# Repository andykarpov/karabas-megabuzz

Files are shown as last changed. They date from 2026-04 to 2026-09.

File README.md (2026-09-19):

## Karabas-MegaBuzz

Simple FPGA based sound card for ZX Spectrum (NemoBus). 
Inspired by a ZX-Multisound and karabas-opl3 soundcards :)

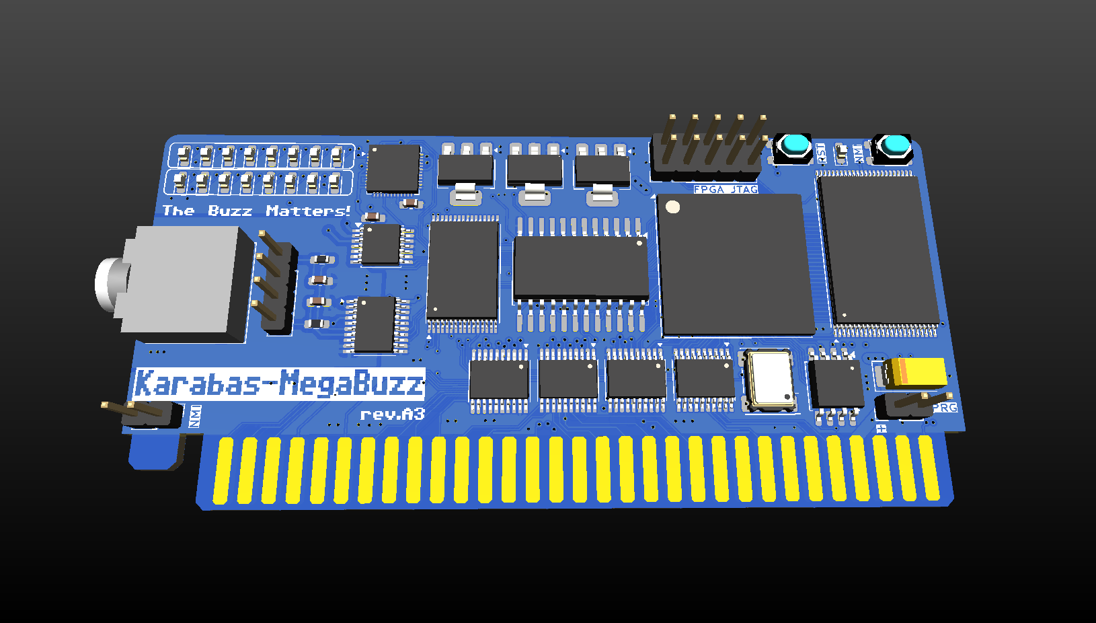
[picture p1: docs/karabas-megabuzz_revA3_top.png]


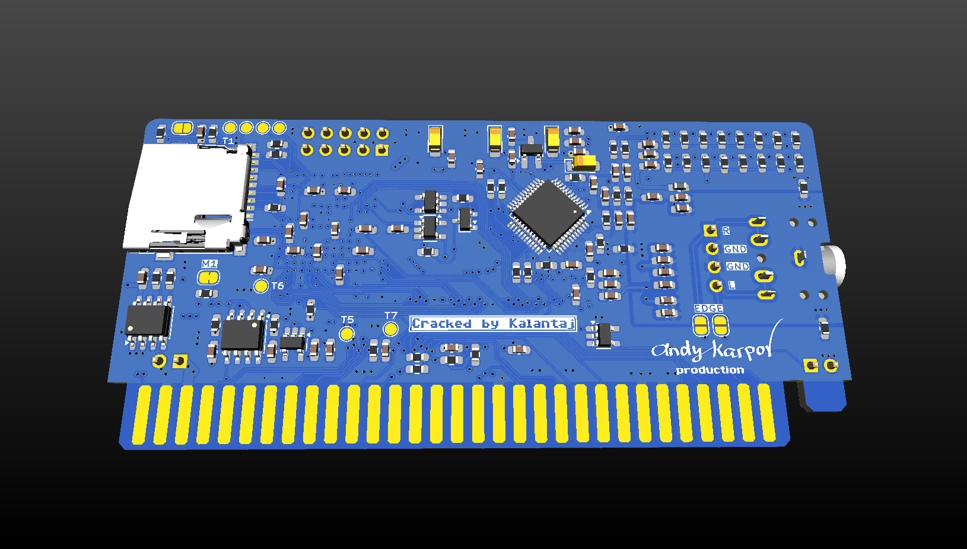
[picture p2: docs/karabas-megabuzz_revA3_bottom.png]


### Tech specs

* Turbosound FM
* General Sound 2 MB
* OPL3 sound by YMF-262-M
* MIDI by Dream SAM2695
* SAA1099
* Soundrive, Covox + Beeper
* MP3, OGG, WMA, AAC decoding by VS1053/VS1063
* 16-bit DAC PCM5102
* XC6SLX16 / XC6SLX25 FPGA
* SD Card by Z-Controller / DivMMC (since rev.A1)
* Low profile PCB: 92x44mm
* 5V only power required

### Changelog & current status [ERRATA](ERRATA.md)

* Rev.A - initial release

* Rev.A1 - intermediate revision

    * [x] Added SD card
    * [x] Changed OPL3 chip power to 3v3 rail, reset controlled by FPGA
    * [x] Added NMI button
    * [x] Added SD LED
    * [x] Added PSRAM chip
    * [x] Added new signals to grab and emit on nemobus (NMI, ROMCS)
    * [x] Added ability to pass sound out via nemobus slot

* Rev.A2 - current revision

    * [x] Removed DIP switches
    * [x] Added 128kB SRAM chip for DivMMC
    * [x] Added 8kb EEPROM chip to store configuration

* Rev.A3 - current dev version

    * [x] Added VS1053 IC

### How-to & Documentation

Please [read the manual](HOWTO.md) how to flash your card with alt tools, like Altera Usb Blaster + openocd.

Some links to the documentation files:

* revA: [Schematics](docs/karabas-megabuzz-revA.pdf), [interactive BOM](docs/karabas-megabuzz-revA-ibom.html)
* revA1: [Schematics](docs/karabas-megabuzz-revA1.pdf), [interactive BOM](docs/karabas-megabuzz-revA1-ibom.html)
* revA2: [Schematics](docs/karabas-megabuzz-revA2.pdf), [interactive BOM](docs/karabas-megabuzz-revA2-ibom.html)
* revA3: [Schematics](docs/karabas-megabuzz-revA3.pdf), [interactive BOM](docs/karabas-megabuzz-revA3-ibom.html)

### Bitstreams & ROMs to flash into the SPI flash chip

| Board Revision | FPGA XC6SLX16 | FPGA XC6SLX25 |
| :--- | :--- | :--- |
| **Rev.A** | • [(Bitstream)](firmware/src/syn/work16/karabas_megabuzz.bin)<br>• [(GS ROM)](firmware/src/rtl/sound/gs105b.rom)<br>• [(CFG)](firmware/src/syn/cfg1.rom) | • [(Bitstream)](firmware/src/syn/work25/karabas_megabuzz.bin)<br>• [(GS ROM)](firmware/src/rtl/sound/gs105b.rom)<br>• [(CFG)](firmware/src/syn/cfg1.rom) |
| **Rev.A1** | • [(Bitstream)](firmware/src/syn/work16/karabas_megabuzz_a1.bin)<br>• [(GS ROM)](firmware/src/rtl/sound/gs105b.rom)<br>• [(CFG)](firmware/src/syn/cfg1.rom) | • [(Bitstream)](firmware/src/syn/work25/karabas_megabuzz_a1.bin)<br>• [(GS ROM)](firmware/src/rtl/sound/gs105b.rom)<br>• [(CFG)](firmware/src/syn/cfg1.rom) |
| **Rev.A2** | • [(Bitstream)](firmware/src/syn/work16/karabas_megabuzz_a2.bin)<br>• [(GS ROM)](firmware/src/rtl/sound/gs105b.rom)<br>• [(CFG)](firmware/src/syn/cfg1.rom) | • [(Bitstream)](firmware/src/syn/work25/karabas_megabuzz_a2.bin)<br>• [(GS ROM)](firmware/src/rtl/sound/gs105b.rom)<br>• [(CFG)](firmware/src/syn/cfg1.rom) |
| **Rev.A3** | • [(Bitstream)](firmware/src/syn/work16/karabas_megabuzz_a3.bin)<br>• [(GS ROM)](firmware/src/rtl/sound/gs105b.rom)<br>• [(CFG)](firmware/src/syn/cfg1.rom) | • [(Bitstream)](firmware/src/syn/work25/karabas_megabuzz_a3.bin)<br>• [(GS ROM)](firmware/src/rtl/sound/gs105b.rom)<br>• [(CFG)](firmware/src/syn/cfg1.rom) |

### Related projects

* Karabas-OPL3 - [link](https://github.com/andykarpov/karabas-opl3)
* BomgeMoon - [link](https://github.com/Kulicheg/BomgeMoon)
* ZX-Multisound - [link](https://github.com/UzixLS/zx-multisound)
* Turbo Sound FM - [link](http://www.nedopc.com/TURBOSOUND/ts-fm.php)
* ZXM-SoundCard - [link](http://micklab.ru/My%20Soundcard/ZXMSoundCard.htm)
* ZXM-GeneralSound - [link](http://micklab.ru/My%20Soundcard/ZXMGeneralSound.htm)
* NeoGS - [link](http://www.nedopc.com/gs/ngs.php)

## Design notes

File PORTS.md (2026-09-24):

# 🎵 Порты Megabuzz

Все звуковые устройства на стороне Megabuzz доступны через свои порты. Также имеются служебные порты для управления самим Megabuzz (для ревизий `A2`, `A3`). В данной документации будут описаны только специфические порты - для vs1053, для управления флагами настроек.

## 🔌 Порты ZXUNO

Для управления чипом vs1053 и служебные порты доступны через набор регистров портов ZXUNO `#FC3B` / `#FD3B`.

### 🔌 Порт выбора регистра ZXUNO - `#FC3B`

Данный порт используется по стандарту ZXUNO для выбора регистра, с которым работает порт данных `#FD3B`.

На данный момент плата Megabuzz поддерживает такие кастомные регистры портов ZXUNO:

- `#F5` - регистр статуса и управления FIFO VS1053
- `#F6` - регистр данных FIFO VS1053
- `#F7` - регистр байта конфигурации Megabuzz
- `#F8` - регистр ПЗУ Megabuzz
- `#F9` - регистр управления Megabuzz
- `#FA` - регистр адреса байта конфигурации Megabuzz
- `#FB` - регистр громкости VS1053
- `#FC` - регистр эффектов VS1053

##### 📟 Регистр `#F5` - статус и управление FIFO VS1053

при чтении из порта данных, возвращается:

- 7️⃣ бит 7 - статус переполнения FIFO VS1053
- 6️⃣...0️⃣ биты 6:0 - количество занятых блоков по 32 байта в FIFO VS1053

при записи в порт данных

- 7️⃣ бит 7 - сбрасывает FIFO и VS1053 через soft reset
- 6️⃣...0️⃣ биты 6:0 = 0

##### 📟 Регистр `#F6` - данные FIFO VS1053

- при записи - записывается переданный байт данных в FIFO VS1053
- при чтении - отдается то же самое, что и для регистра #F5 (то есть статус FIFO)

##### 📟 Регистр `#F7` - регистр байта конфигурации Megabuzz

- при записи в порт данных - пишется байт конфигурации по адресу, выставленному для регистра `#FA`
- при чтении из порта данных - отдается байт конфигурации по адресу, выстанвленному для регистра `#FA`

В данных момент существует только 2 байта конфигурации

Первый байт конфигурации (адрес = 0x00):

- 0️⃣ бит 0 - DivMMC вкл = 1, выкл = 0
- 1️⃣ бит 1 - Z-Controller вкл = 1, выкл = 0
- 2️⃣ бит 2 - Soundrive
- 3️⃣ бит 3 - Beeper
- 4️⃣ бит 4 - SAA1099
- 5️⃣ бит 5 - General Sound
- 6️⃣ бит 6 - Turbosound FM + MIDI
- 7️⃣ бит 7 - OPL3

Второй байт конфигурации (адрес = 0x01)

- 0️⃣ бит 0 - Включен ли столбик VU-метра
- 1️⃣ бит 1 - Включена ли точка VU-метра
- 2️⃣ бит 2 - Переключает направление VU-метра в обратную сторону

##### 📟 Регистр `#F8` - регистр ПЗУ Megabuzz

- 0️⃣ бит 0 - переключает между штатной ПЗУ хоста или ПЗУ конфигуратора Megabuzz. `1` = ПЗУ Megabuzz, `0` - ПЗУ спектрума

##### 📟 Регистр `#F9` - регистр управления Megabuzz

- 0️⃣ бит 0 - значение `1` - осуществляет сброс хоста

##### 📟 Регистр `#FA` - адрес байта конфигурации Megabuzz

- 7️⃣...0️⃣ биты 7:0 - задают адрес байта конфигурации. Валидные значения на сегодня - `0x00`, `0x01`

##### 📟 Регистр `#FB` - громкость VS1053

- значение `0x00` - максимальная громкость
- значение `0xFE` - минимальная громкость

По-умолчанию, плата сбрасывается со значением громкости `0x08` (ослабление примерно `-5дБ` от максимальной громкости).

##### 📟 Регистр `#FС` - управление эффектами VS1053

- 7️⃣...6️⃣ биты 7:6 - ear speaker (`00` - off, `01` - low, `10` - mid, `11` - high)
- 5️⃣...3️⃣ биты 5:3 - treble boost (`000` - off, `111` - max +10.5dB) at 5kHz
- 2️⃣...0️⃣ биты 2:0 - bass boost (`000` - off, `111` - max + 14dB) at 60Hz

По-умолчанию, регистр эффектов содержит значение `0x00`

### 🔌 Порт данных ZXUNO - `#FD3B`

В данный порт пишется значение в регистр, выбранный перед этим через порт `#FC3B`.
Значения регистров доступны и для чтения через этот порт.

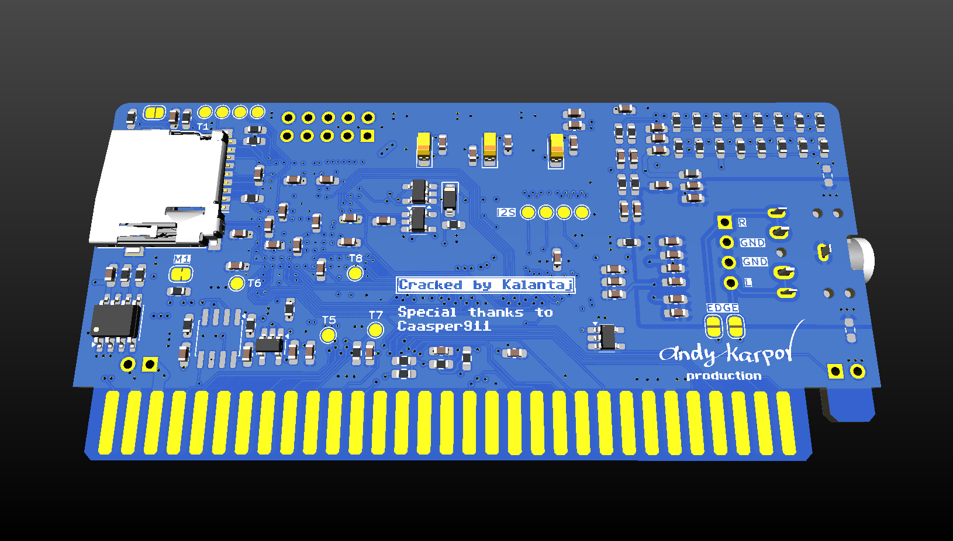
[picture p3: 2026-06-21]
docs/karabas-megabuzz_revA2_bottom.png

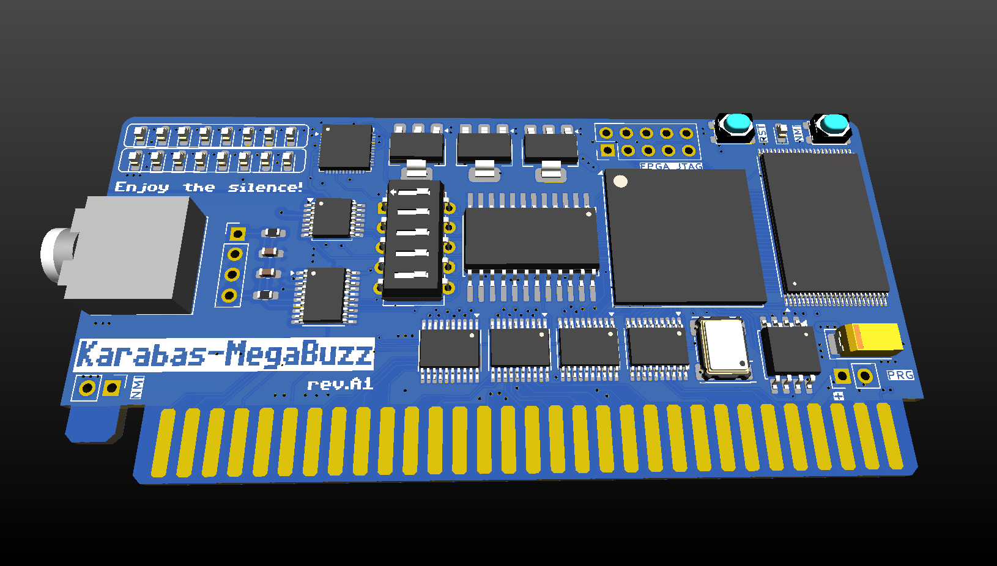
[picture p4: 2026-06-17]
docs/karabas-megabuzz_revA1_top.png

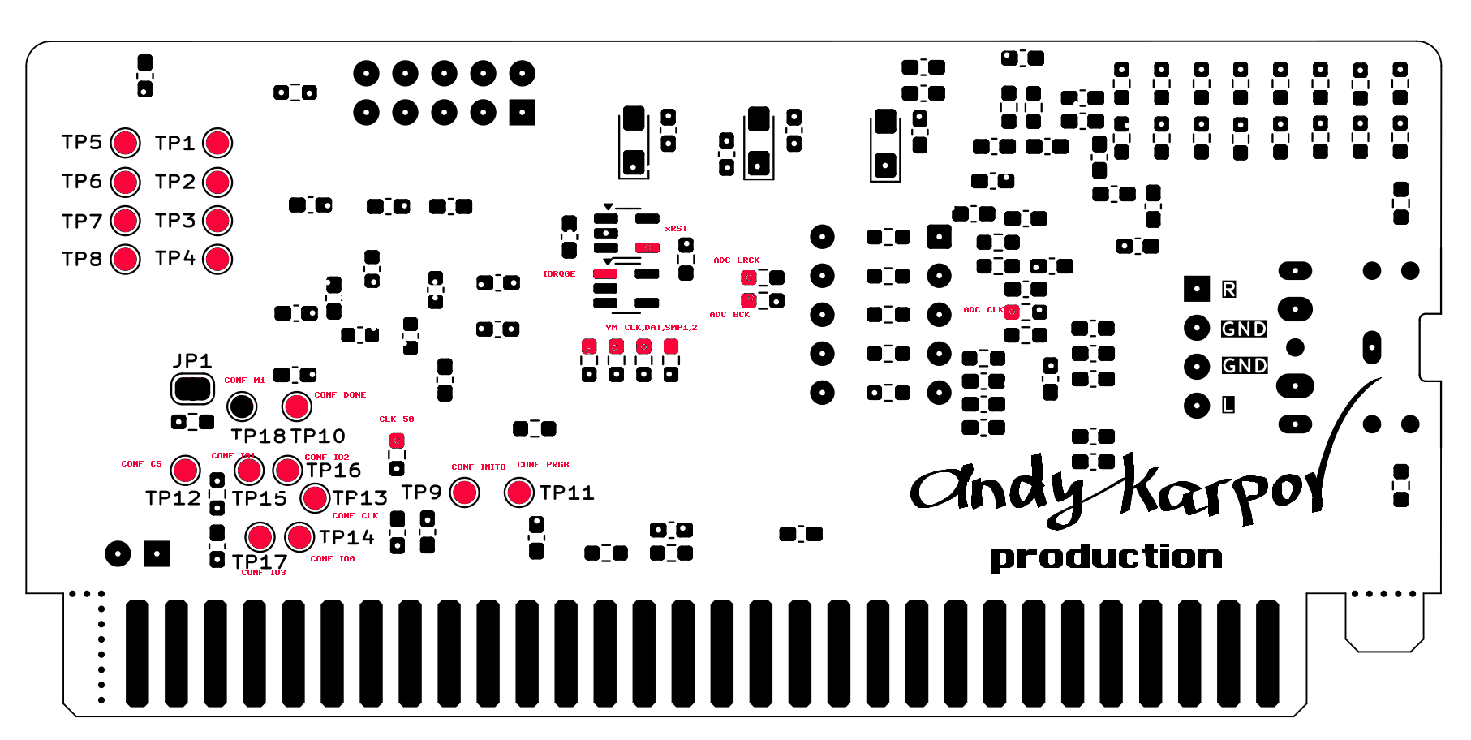
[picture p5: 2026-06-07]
docs/karabas-megabuzz_revA_bottom_map.png

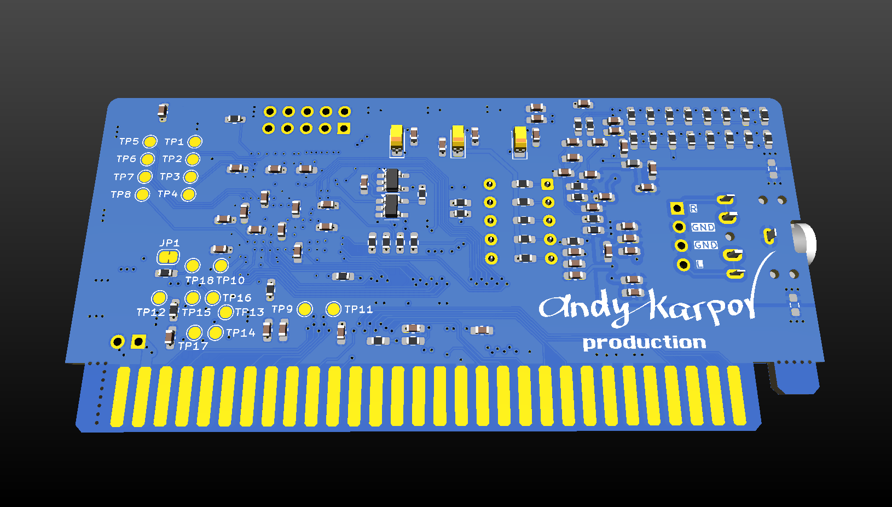
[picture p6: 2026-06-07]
docs/karabas-megabuzz_revA_bottom.png

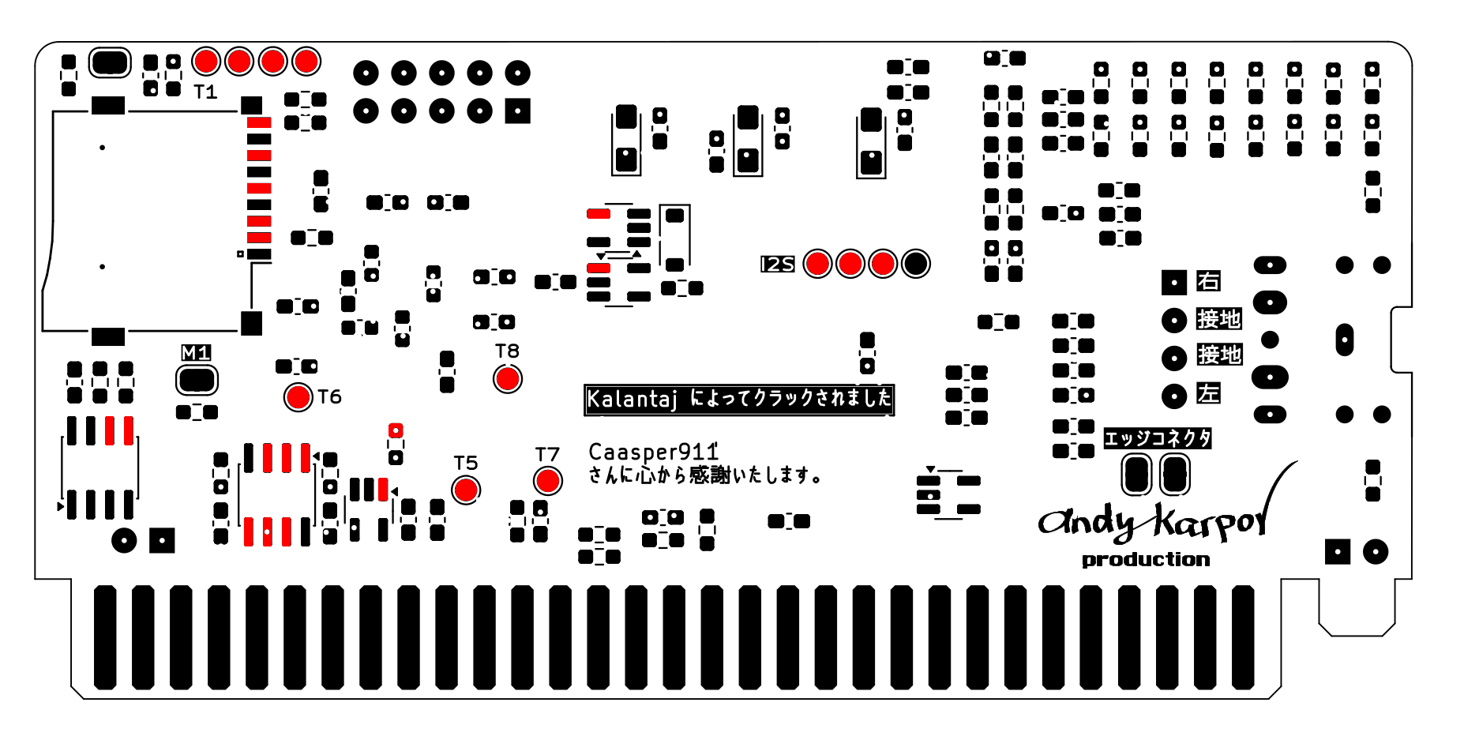
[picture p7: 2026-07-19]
docs/karabas-megabuzz_revA2_bottom_map.png

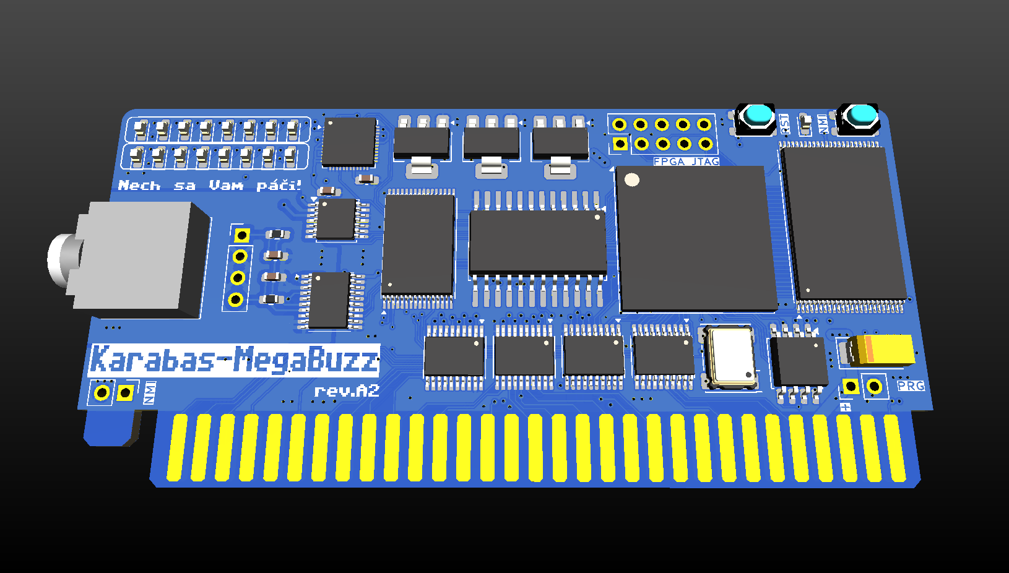
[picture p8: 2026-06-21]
docs/karabas-megabuzz_revA2_top.png

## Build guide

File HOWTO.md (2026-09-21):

## Karabas-MegaBuzz How-to

### Прозвонка спартана

Запаивание компонентов на плату желательно начать со спартана. 
После запаивания спартана, желательно прозвонить плату.
Для этого мультиметр в режиме прозвонки (диодов), красным щупом становимся на землю. 
А черным щупом тыкаем в пятаки, отмеченные красным цветом на карте прозвонки [верх revA](docs/karabas-megabuzz_revA_top_map.png) и [низ revA](docs/karabas-megabuzz_revA_bottom_map.png).
Для ревизии revA2 также имеются карты прозвонки: [верх revA2](docs/karabas-megabuzz_revA2_top_map.png) и [низ revA2](docs/karabas-megabuzz_revA2_bottom_map.png)
Все отмеченные пятаки должны показывать примеро одинаковые показания.
Если звонится в 0 - значит, вероятно, шар имеет КЗ с землей.
Если не звонится - значит, вероятно, шар не сел. Нужно еще раз подогреть плату, подуть феном, качнуть камень.

### Прошивка

Чтобы запустить плату, ее необходимо прошить.
Для удешевления конструкции, на плате JTAG header разведен для подключения Altera USB Blaster.

Соответственно, шить SPI флешку можно несколькими путями:

1) засунуть в программатор и прошить BIN-файл прошивки, ПЗУ для GS и конфигурационную ПЗУ (битстрим с 0 адреса, ПЗУ для GS с адреса 0x100000, конфиг с адреса 0x1F0000)
2) подключить Xilinx Platform USB Cable программатор и прошить с помощью iMPACT (битстрим с 0 адреса, ПЗУ для GS с адреса 0x100000, конфиг с адреса 0x1F0000)
3) взять сторонний опен-сорсный проект openFPGALoader и прошить любым JTAG-совместимым программатором, включая Altera USB Blaster
4) то же самое, но через openOCD
5) то же самое, но через urJTAG

Первые 2 пункта нет смысла описывать.
Остановимся подробнее на пунктах 3 и 4 - openFPGALoader (годится пока только для камней xc6slx16, под xc6slx25 в openFpgaLoader'е есть какие-то косяки, флешку он через jtag-spi мост не видит) и openocd.

#### Прошивка с помощью openFPGALoader

1) Ставим openFPGALoader (в современных linux-дистрибутивах он есть из коробки, но версия древняя, поэтому лучше собрать из сырцов согласно мануалу с сайта производителя). Также имеются сборки под windows и mac os.
2) Подключаем USB Blaster
3) Подаем питание 5В на плату (можно через специальный разъем prg на плате)
4) make flash - прошьет прошивку под камень XC6SLX16 для revA
5) make flash_a1 - прошьет прошивку под камень XC6SLX16 для revA1
6) makr flash_a2 - прошьет прошивку под камень XC6SLX16 для revA2
7) make flash_rom - прольет 32kB образ ПЗУ GS по адресу 0x100000 во флеш (актуально для revA1 и revA2, опционально для revA)
8) make flash_cfg1 - прольет 256 байт конфига cfg1 по адресу 0x1F0000 во флеш (актуально для revA2, опционально для revA и revA1)
9) make flash_cfg2 - прольет 256 байт конфига cfg2 по адресу 0x1F0000 во флеш (актуально для revA2, опционально для revA и revA1)

Если влом юзать makefile, можно руками, пример прошивки битстрима для SLX16:

`openFPGALoader -c usb-blaster --fpga-part xc6slx16ftg256 -f work16/karabas_megabuzz.bit`

Пример прошивки ПЗУ GS:

`openFPGALoader -c usb-blaster --fpga-part xc6slx16ftg256 -f -o 0x100000 ../rtl/sound/gs105b.rom`

После программирования плата запустится.
Покажет индикацию уровня сигнала от максимума до минимума.
Кнопкой RESET также покажет индикацию. Это верный признак, что FPGA-часть платы запустилась.

#### Прошивка с помощью openocd

1) Ставим openocd (в современных linux-дистрибутивах он есть из коробки). Также имеются сборки под windows и mac os.
2) Подключаем USB Blaster
3) Подаем питание 5В на плату (можно через специальный разъем prg на плате)
4) make flash25 - прошьет прошивку под камень XC6SLX25 для revA
5) make flash25_a1 - прошьет прошивку под камень XC6SLX25 для revA1 с ПЗУ GS и конфигом cfg1
6) make flash25_a2 - прошьет прошивку под камень XC6SLX25 для revA2 с ПЗУ GS и конфигом cfg1
7) make flash25_a2_nommc - прошьет прошивку под камень XC6SLX25 для revA2 с ПЗУ GS и конфигом cfg2

Если влом юзать makefile, можно руками, пример прошивки битстрима для SLX25:

`sudo openocd -f ocd.cfg -c "init; jtagspi_init 0 bscan_spi_xc6slx25.bit; jtagspi_program work25/karabas_megabuzz_a2.bin 0; jtagspi_program ../rtl/sound/gs105b.rom 0x100000; jtagspi_program cfg1.rom 0x1F0000; xc6s_program xc6s.tap; exit"`

После программирования плата запустится.
Покажет индикацию уровня сигнала от максимума до минимума.
Кнопкой RESET также покажет индикацию. Это верный признак, что FPGA-часть платы запустилась.

ЗЫ: по аналогии можно шить и XC6SLX16 камни, через openocd. соответствующий jtag-spi мост есть - bscan_spi_xc6slx16.bit.

### DIP-переключатели

На плате revA и revA1 имеется 5 дип-переключателей.
Если его не запаивать, все девайсы на плате будут работать.

#### Назначение переключателей для revA:

1) SW1 - Soundrive + Covox + Beeper
2) SW2 - SAA1099
3) SW3 - General Sound
4) SW4 - TurbosoundFM + Midi
5) SW5 - OPL3

#### Назначение переключателей для revA1:

1) SW1 - DivMMC
2) SW2 - Soundrive + Covox + Beeper + SAA1099
3) SW3 - General Sound
4) SW4 - TurbosoundFM + Midi
5) SW5 - OPL3

#### Назначение переключателей для revA2 и revA3:

на плате отсутствуют дип-переключатели.
вместо этого в первом байте конфигурационной ПЗУ (cfg1.rom или cfg2.rom) это все переключается битами (1 - включено, 0 - выключено. например байт 0xFF означает, что все оборудование включечно):

- бит 0 - DivMMC
- бит 1 - ZC
- бит 2 - Soundrive + Covox
- бит 3 - Beeper
- бит 4 - SAA1099
- бит 5 - General Sound
- бит 6 - Turbosound + FM + Midi
- бит 7 - OPL3

Важно: Если после старта платы зажать на ней кнопки reset + nmi, то плата провалится в конфигурационную ПЗУ, с помощью которой можно настроить все эти биты конфигурации и применить их (сохранить в байт конфигурации на флеш). 

Из бонусов, кроме звуковых устройств, также можно настраивать тип светодиодного индикатора и менять его направление. Можно вообще отключить, чтоб не мозолил глаза :)

### Тест-поинты на обратной стороне платы

#### revA

- TP1 - выход /OPL3_RST - для доработки rev.A (сброс OPL3 при старте платы - нужно оторвать ногу 8 RST от платы и завести проводком на TP1)
- TP2 - если засоплить на землю, меняет направление индикаторов
- TP3 - если засоплить на землю, не будет показывать столбик VU
- TP4 - если засоплить на землю, не будет показывать точку VU
- TP5-TP8 - пока свободны
- Остальные - связаны с соотв сигналами конфигурации спартана.

#### revA1

- TP1 - TP4 - зарезервировано
- TP5 - TP8 - системные

#### revA2, revA3

- TP1 - TP4 - зарезервировано
- TP5 - TP8 - системные
- I2S - выход звука i2s

### Воспроизведение MP3

На плате ревизии A3 имеется аппаратный mp3 декодер (микросхема vs1053 / vs1063).
Для NMI browser от Bob Fossil имеется плагин mp3, который нужно положить в bin/bplugins/ на SD-карте.
Умеет воспроизводить MP3 файлы, в том числе подряд в директории.

Управление:

    - Space - следующий трек
    - Q - выход

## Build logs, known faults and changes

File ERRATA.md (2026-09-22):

### revA:
----

1. Начальный сброс OPL3.

Чипу OPL3 нужен сброс, когда у нее есть тактирование.
Хост стартует быстрее, чем плата megabuzz, соответственно чип не ресетится при старте и имеет какой-то мусор в регистрах. 
В результате - какое-то бульканье из OPL3 чипа, пока не сбросить хост еще раз.

2. Слишком короткий сигнал сброса в ZX-Evolution - чип OPL3 не успевает сброситься по F12.

Решение обеих проблем: не подключать /RST сигнал чипа OPL3 к ZX-BUS, а управлять им со стороны FPGA.
Формировать сигнал сброса для OPL3 (и для MIDI чипа заодно) длительностью не менее 2.7мкс.

Внимание: Эти моменты с сигналом /RST поправлены в последних обновлениях схемы и герберах revA от 2026-06-04.
Только первоначальная ревизия платы revA требует доработок.
Для тех, кто заказал первые ревизии плат revA, чтобы пофиксить эту проблемку, нужно поднять ногу /RST у OPL3 чипа и прокинуть ее проводочком на TP1.
Так как чип на одной стороне платы, а TP1 на другой, предлагается пропустить проводок через один из неиспользуемых пинов разъема JTAG, предварительно не запаивая туда пин.

3. 5в сигналы от OPL3 к FPGA. сейчас идут по упрощенной схеме через гасящие резисторы.
Но сколько так продержится FPGA - непонятно.
Было решено в ревизии A1 запитать чип OPL3 от 3.3В (пишут, что неофициально - это работает).
И, соответственно, прокинуть сигналы ШД с 3.3-вольтовой шины данных.
Это готово в rev.A1, протестировано, вполне работает.

### RevA1:

1. Неправильно разведены сигналы блокировки ПЗУ
- отрезать сигнал от A25 слота NemoBus
- подсоединить A15 и B4 к месту, откуда шел сигнал к A25

2. Светодиод LED1 не подключен к FPGA
- хотфикса нет (не принципиально, не горит - и фиг с ним)

(В master ветке проекта от 2026-06-17 уже внесены соотв исправления на плату revA1).

### RevA2:

- пока багов в схеме и разводке не обнаружено.

### RevA3:

- отсутствуют pulldown на GPIO0, GPIO1 у чипа VS1053. как хотфикс - просто засоплить на землю (земляная нога есть рядом).
- отсутствует pullup на RX у VS1053. хотфикс - притянуть к ближайшему 3.3v
- исправления необходимы только для плат, выпущенных до 2026-09-23.

(В master ветке проекта от 2026-09-23 уже внесены соотв исправления на плату revA3).

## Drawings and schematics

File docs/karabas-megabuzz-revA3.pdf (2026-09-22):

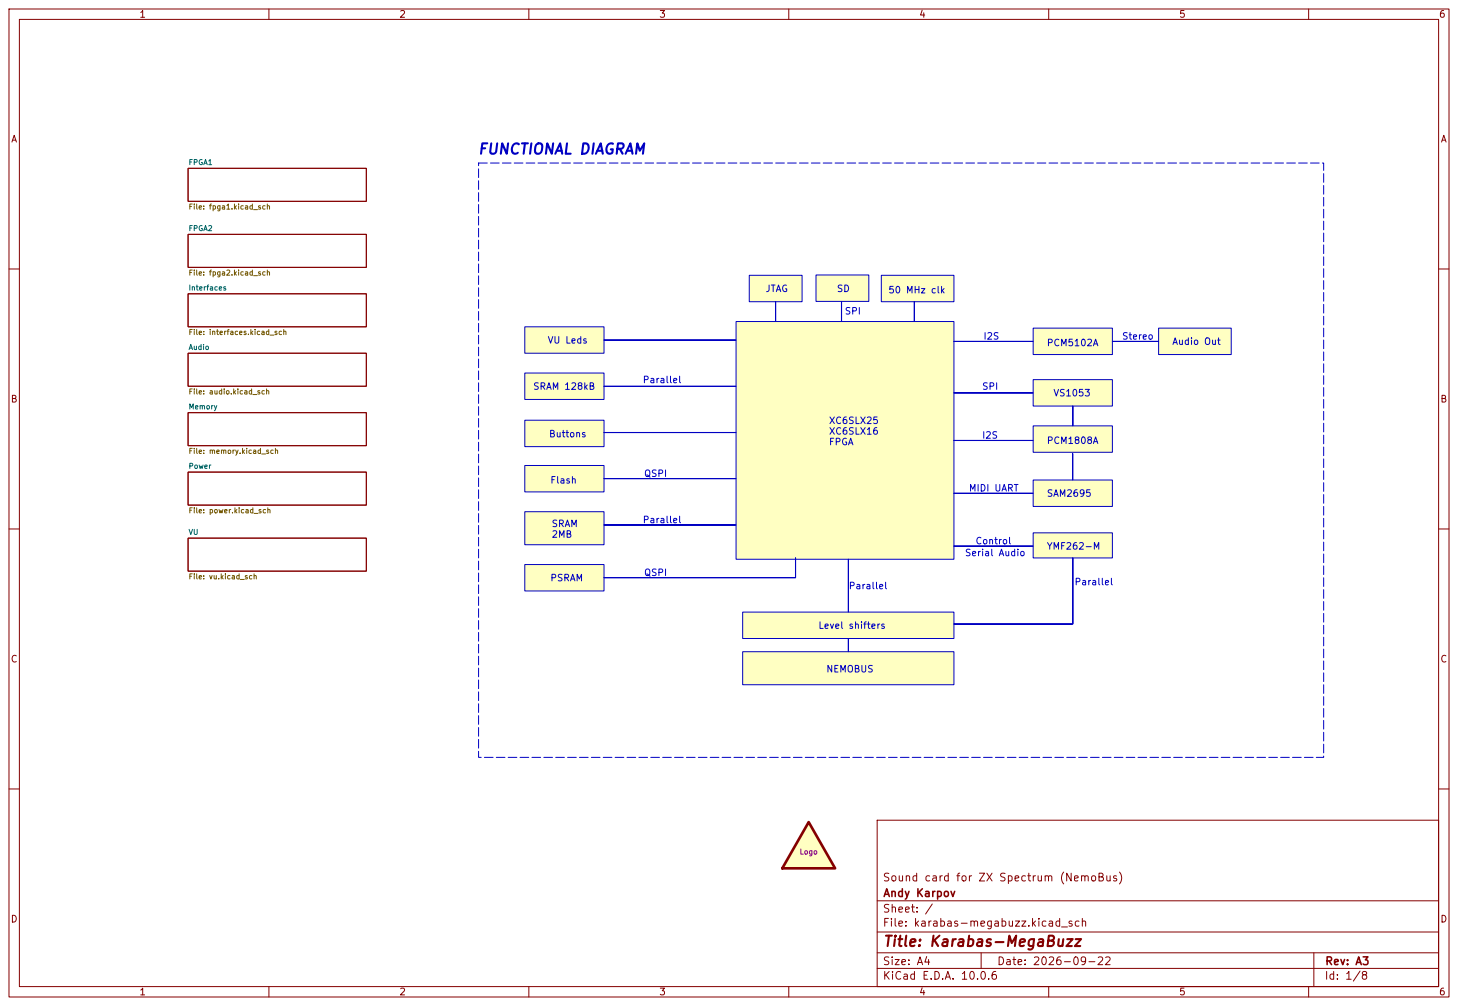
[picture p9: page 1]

File: fpga1.kicad_sch Memory File: memory.kicad_sch
Interfaces File: interfaces.kicad_sch Power File: power.kicad_sch

Audio Out Stereo PSRAM

Sound card for ZX Spectrum (NemoBus)
Andy Karpov
Sheet: /
File: karabas-megabuzz.kicad_sch
Title: Karabas-MegaBuzz

Size: A4 | Rev: A3
KiCad E.D.A. 10.0.6 | Id: 1/8

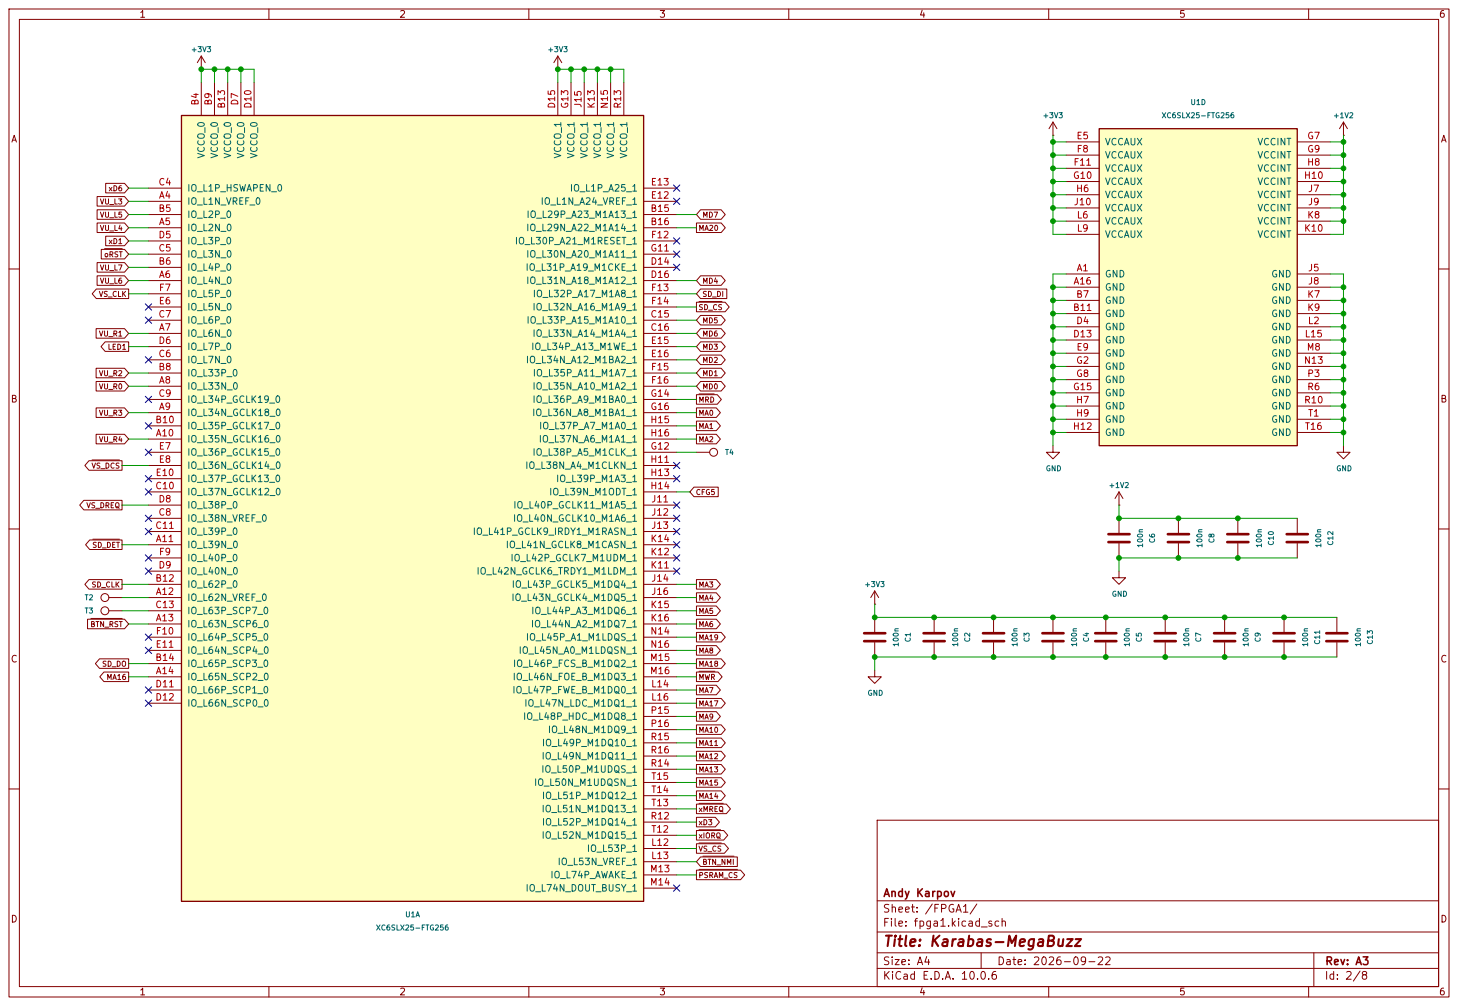
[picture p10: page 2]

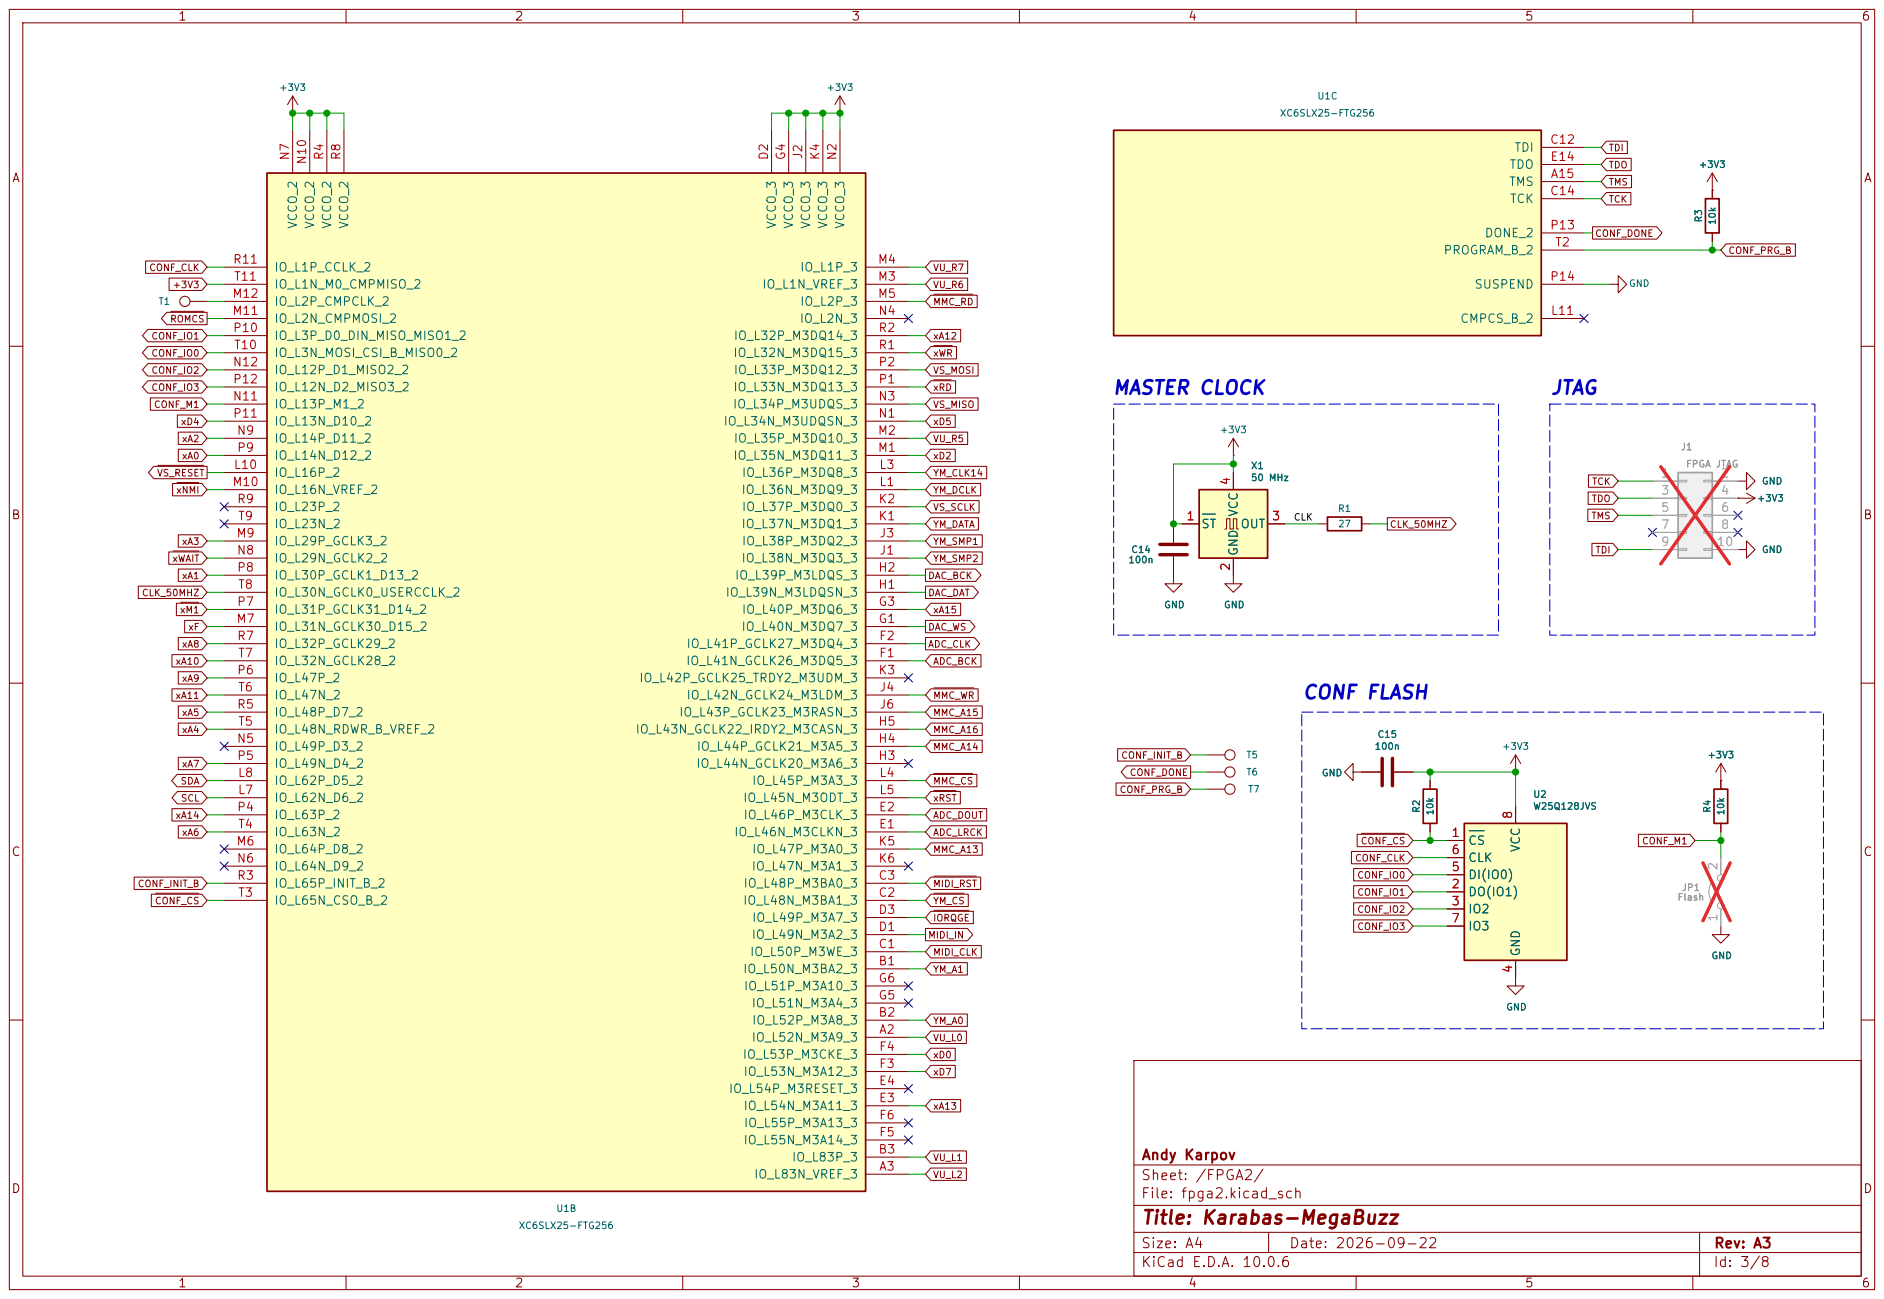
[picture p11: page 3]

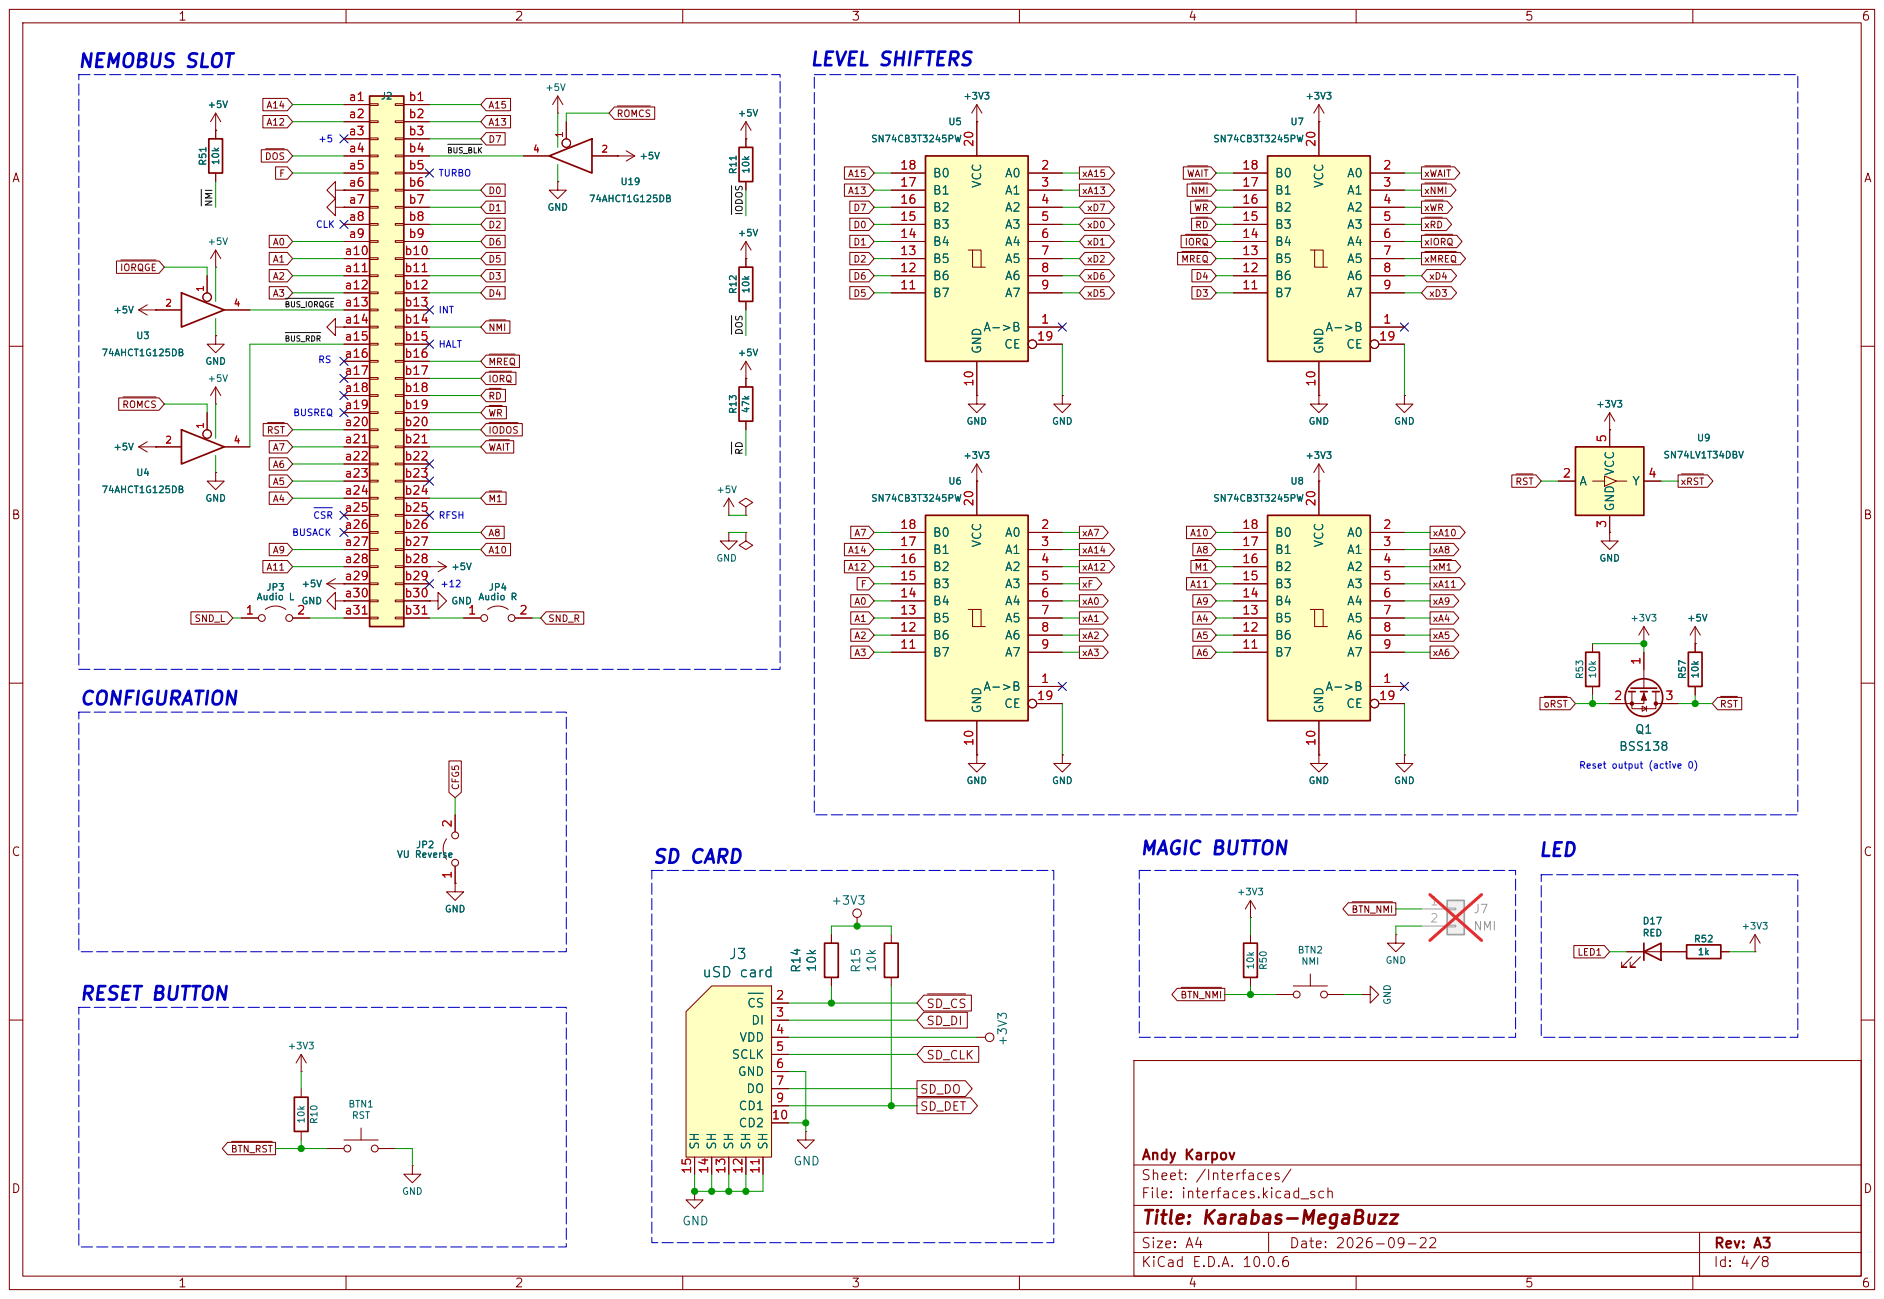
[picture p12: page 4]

SCLK 5 GND 6 DO 7 CD1 9 CD2 10 SH 11 SH 12 SH 13 SH 14 SH 15

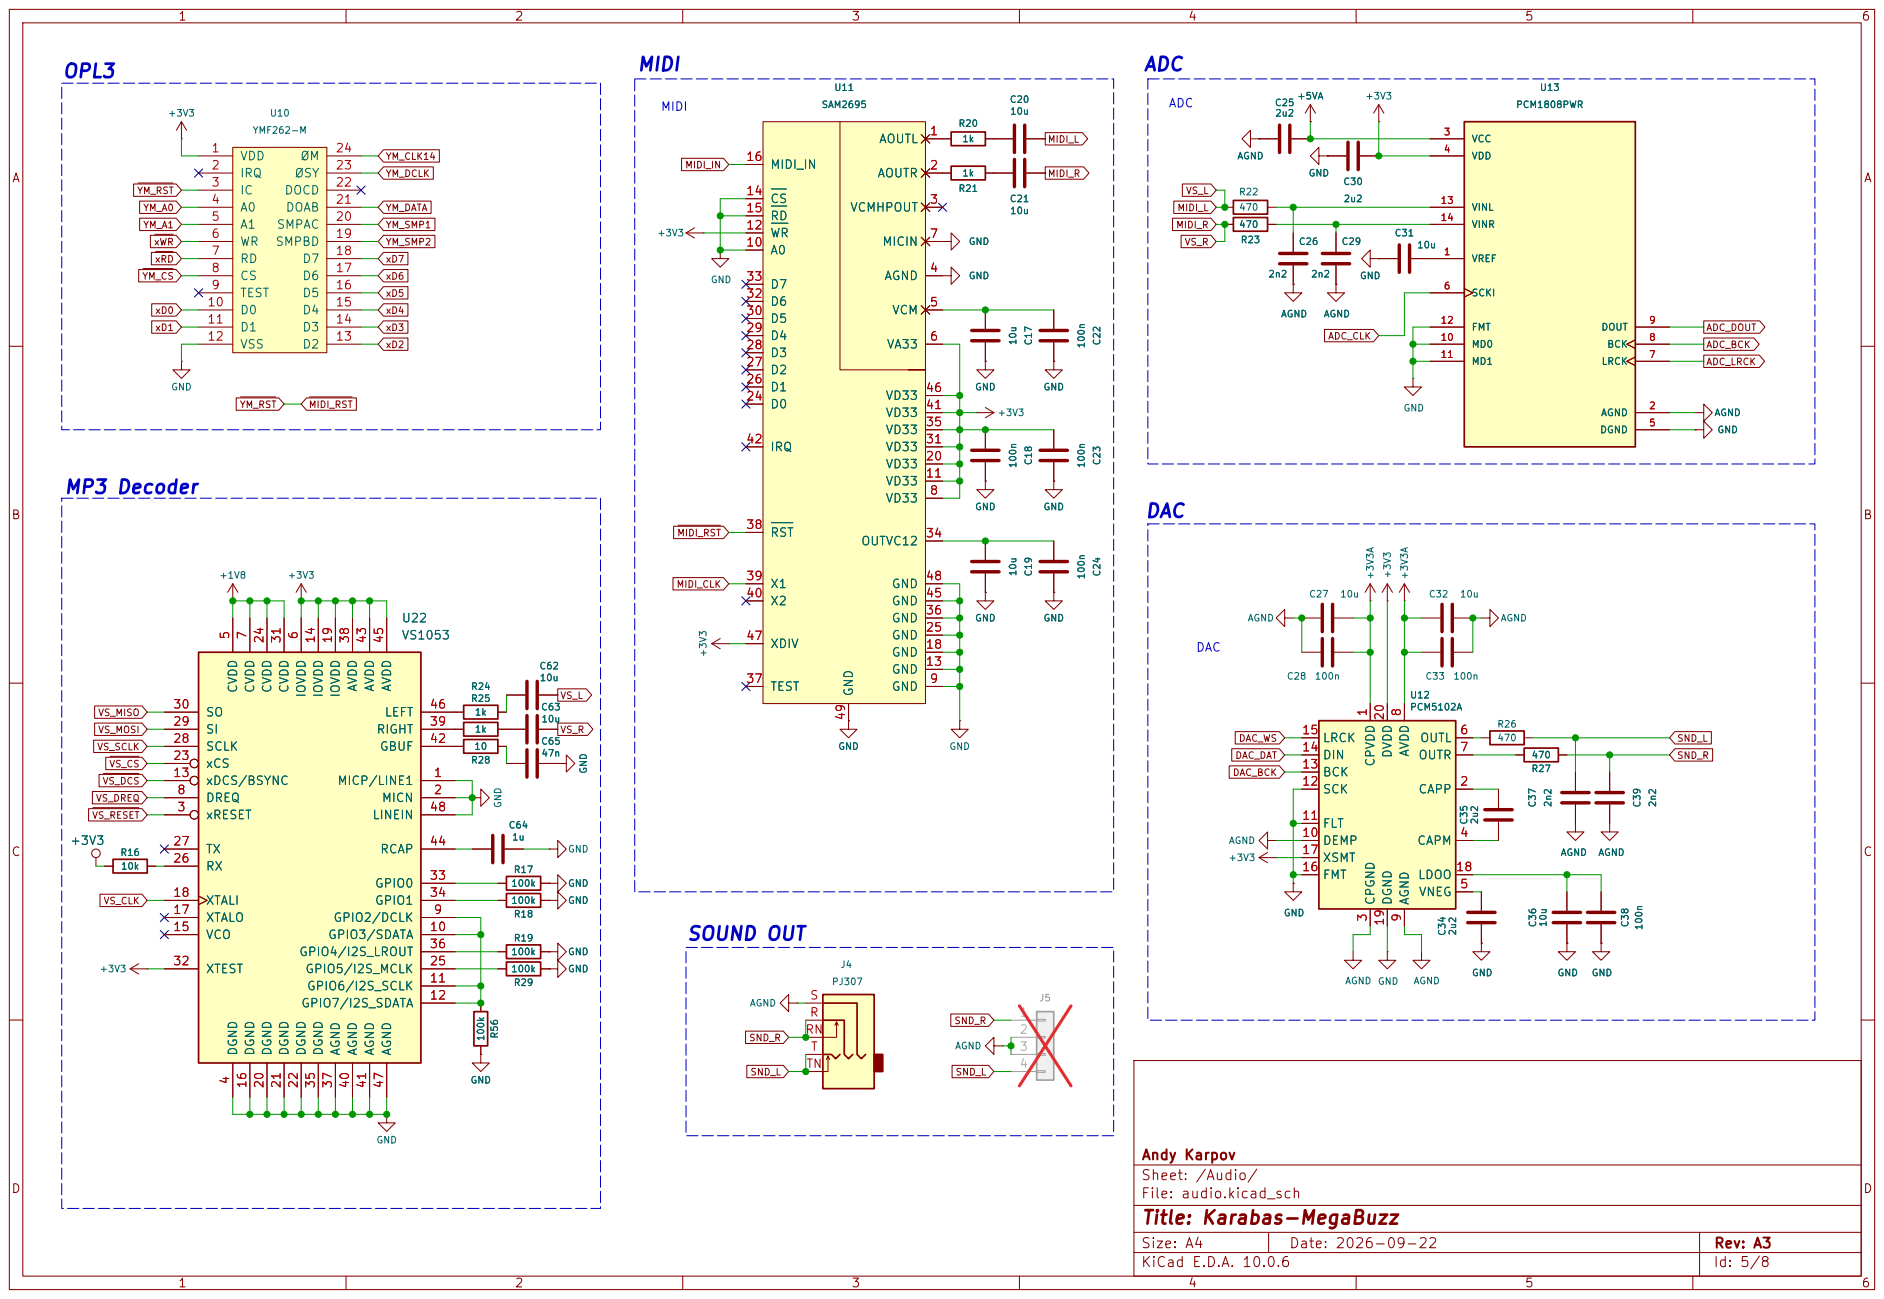
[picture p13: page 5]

SCK 12 BCK 13 DIN 14 LRCK 15

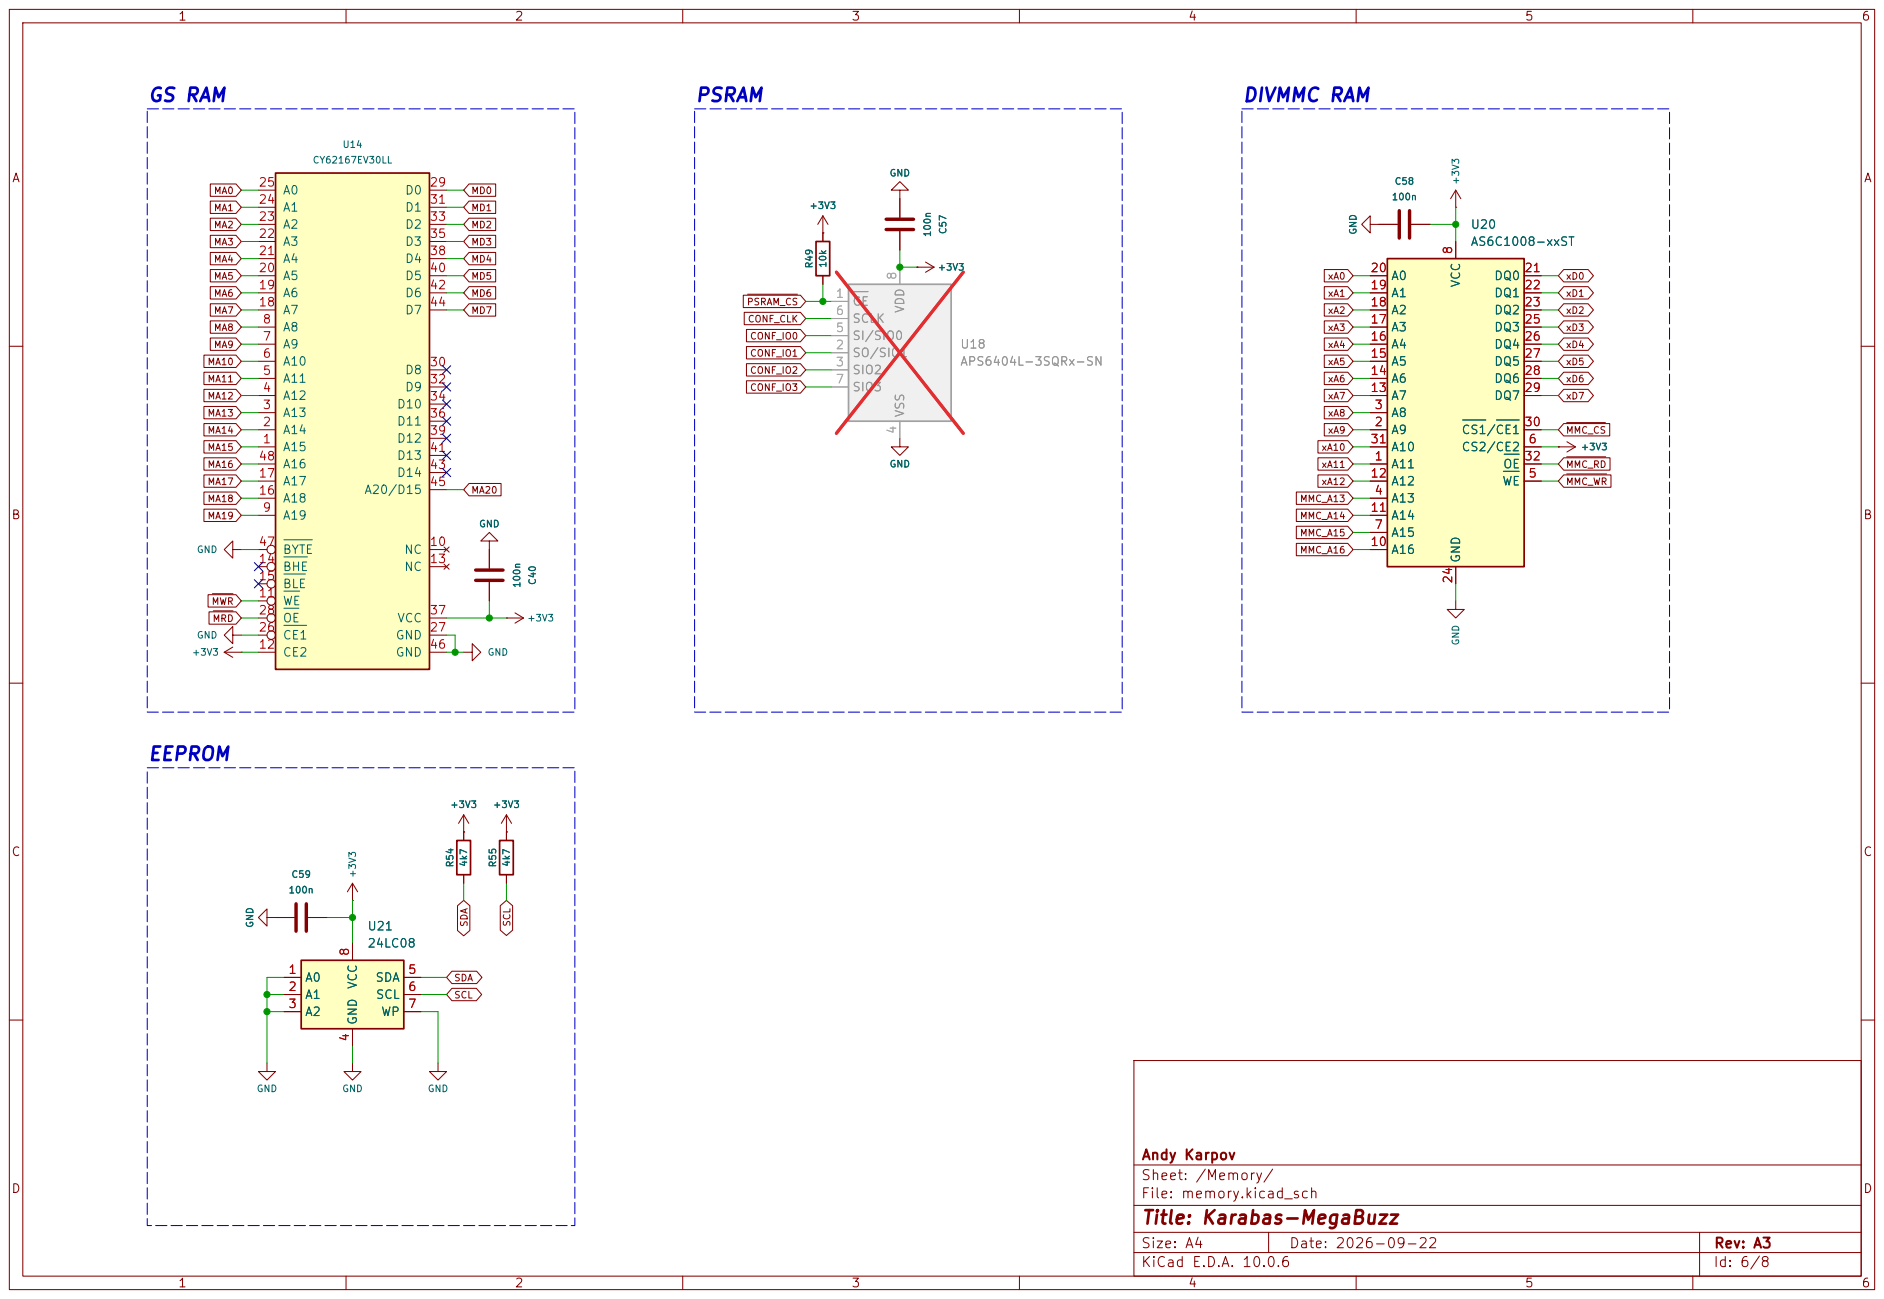
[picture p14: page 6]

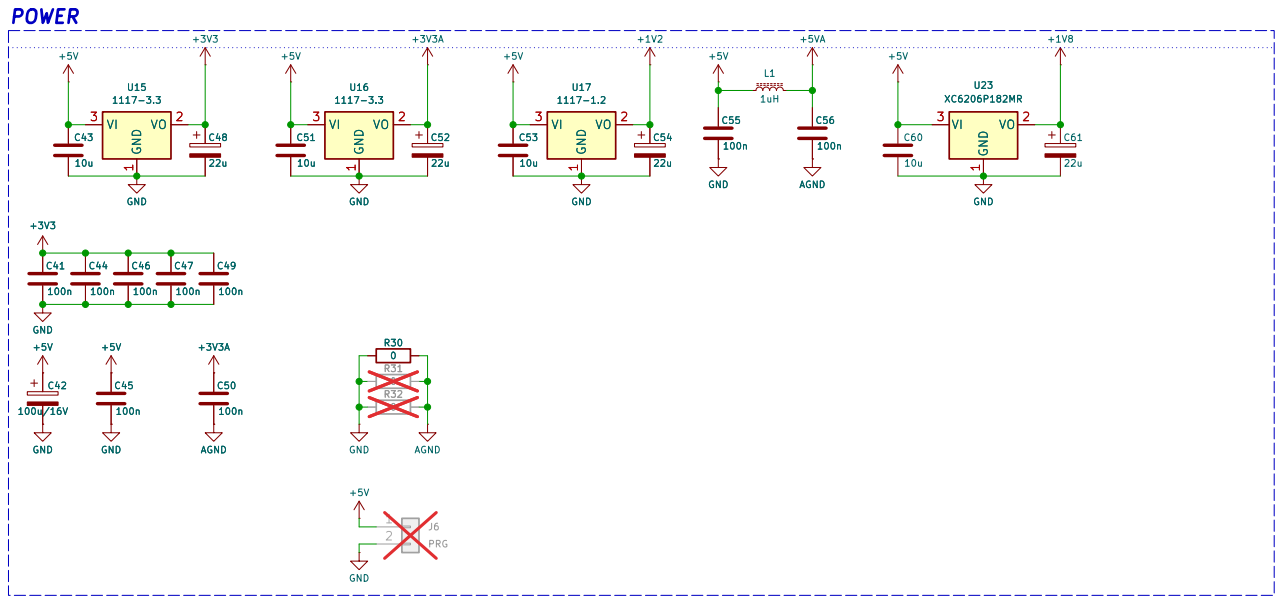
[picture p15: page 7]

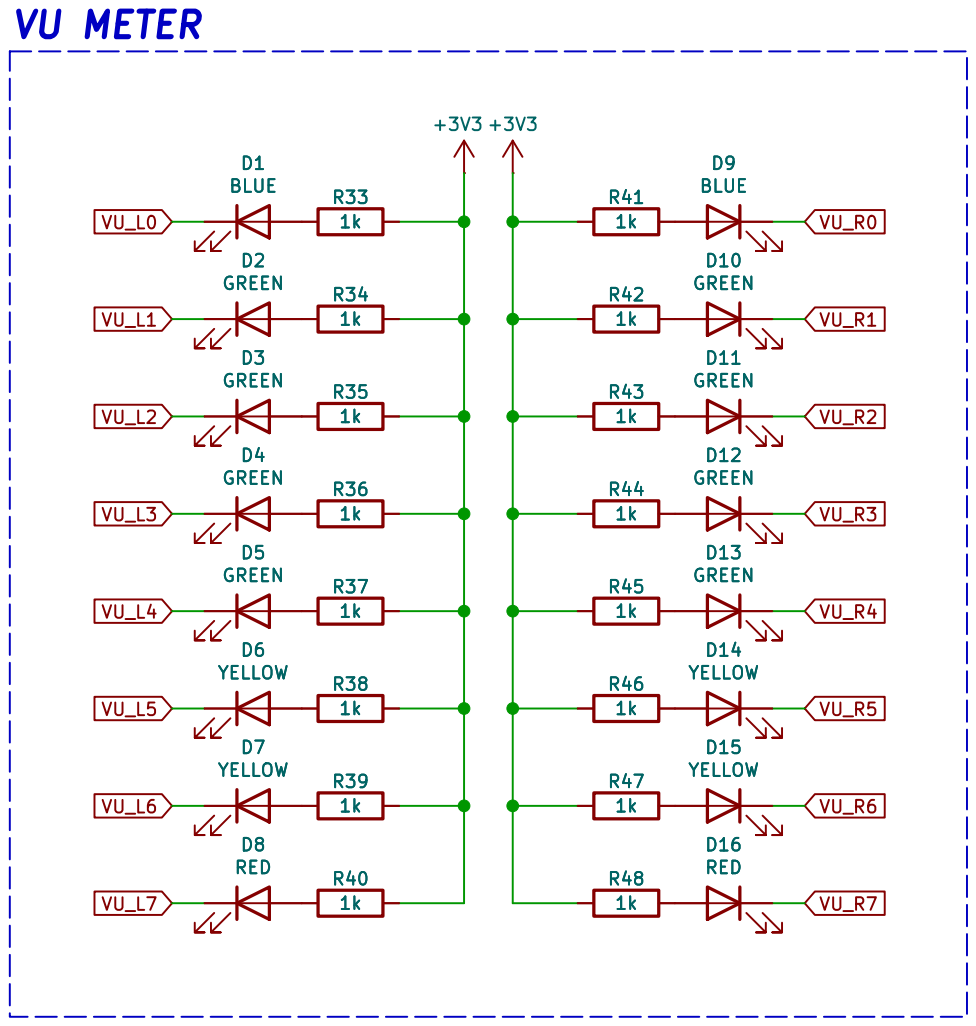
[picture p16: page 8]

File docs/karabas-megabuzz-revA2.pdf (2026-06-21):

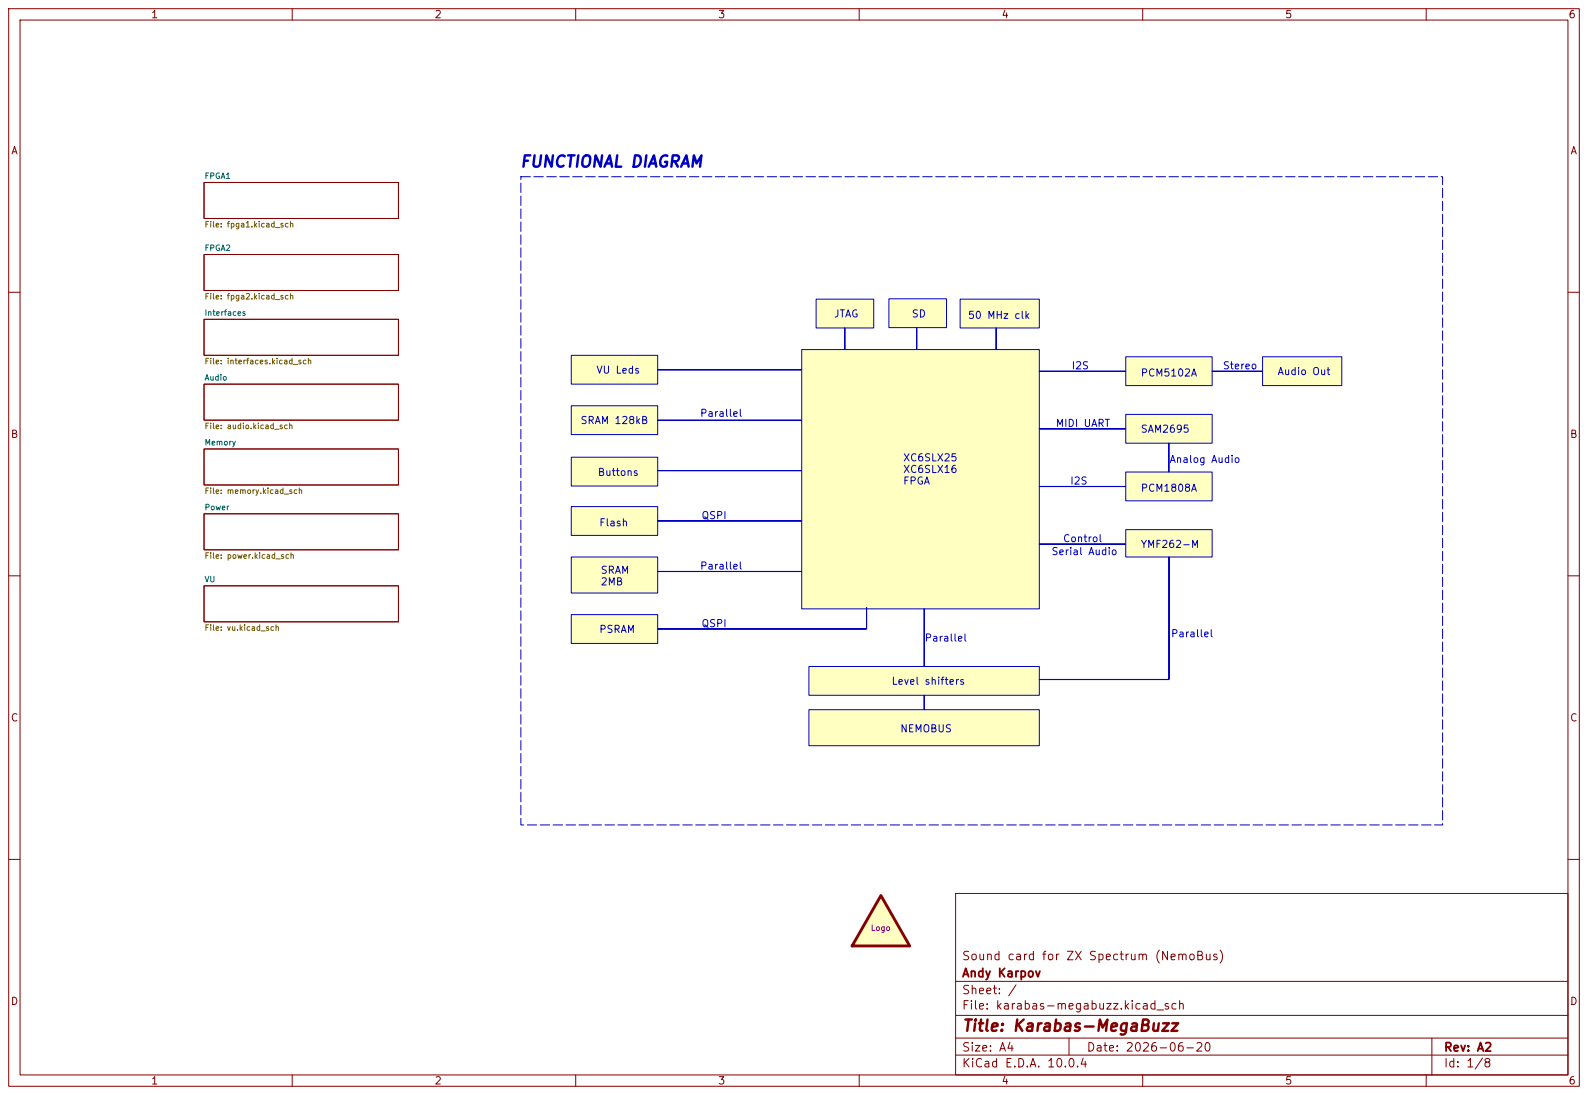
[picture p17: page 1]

File: fpga1.kicad_sch Power File: power.kicad_sch

File: audio.kicad_sch Memory File: memory.kicad_sch

Sound card for ZX Spectrum (NemoBus)
Andy Karpov
Sheet: /
File: karabas-megabuzz.kicad_sch
Title: Karabas-MegaBuzz

Size: A4 | Rev: A2
KiCad E.D.A. 10.0.4 | Id: 1/8

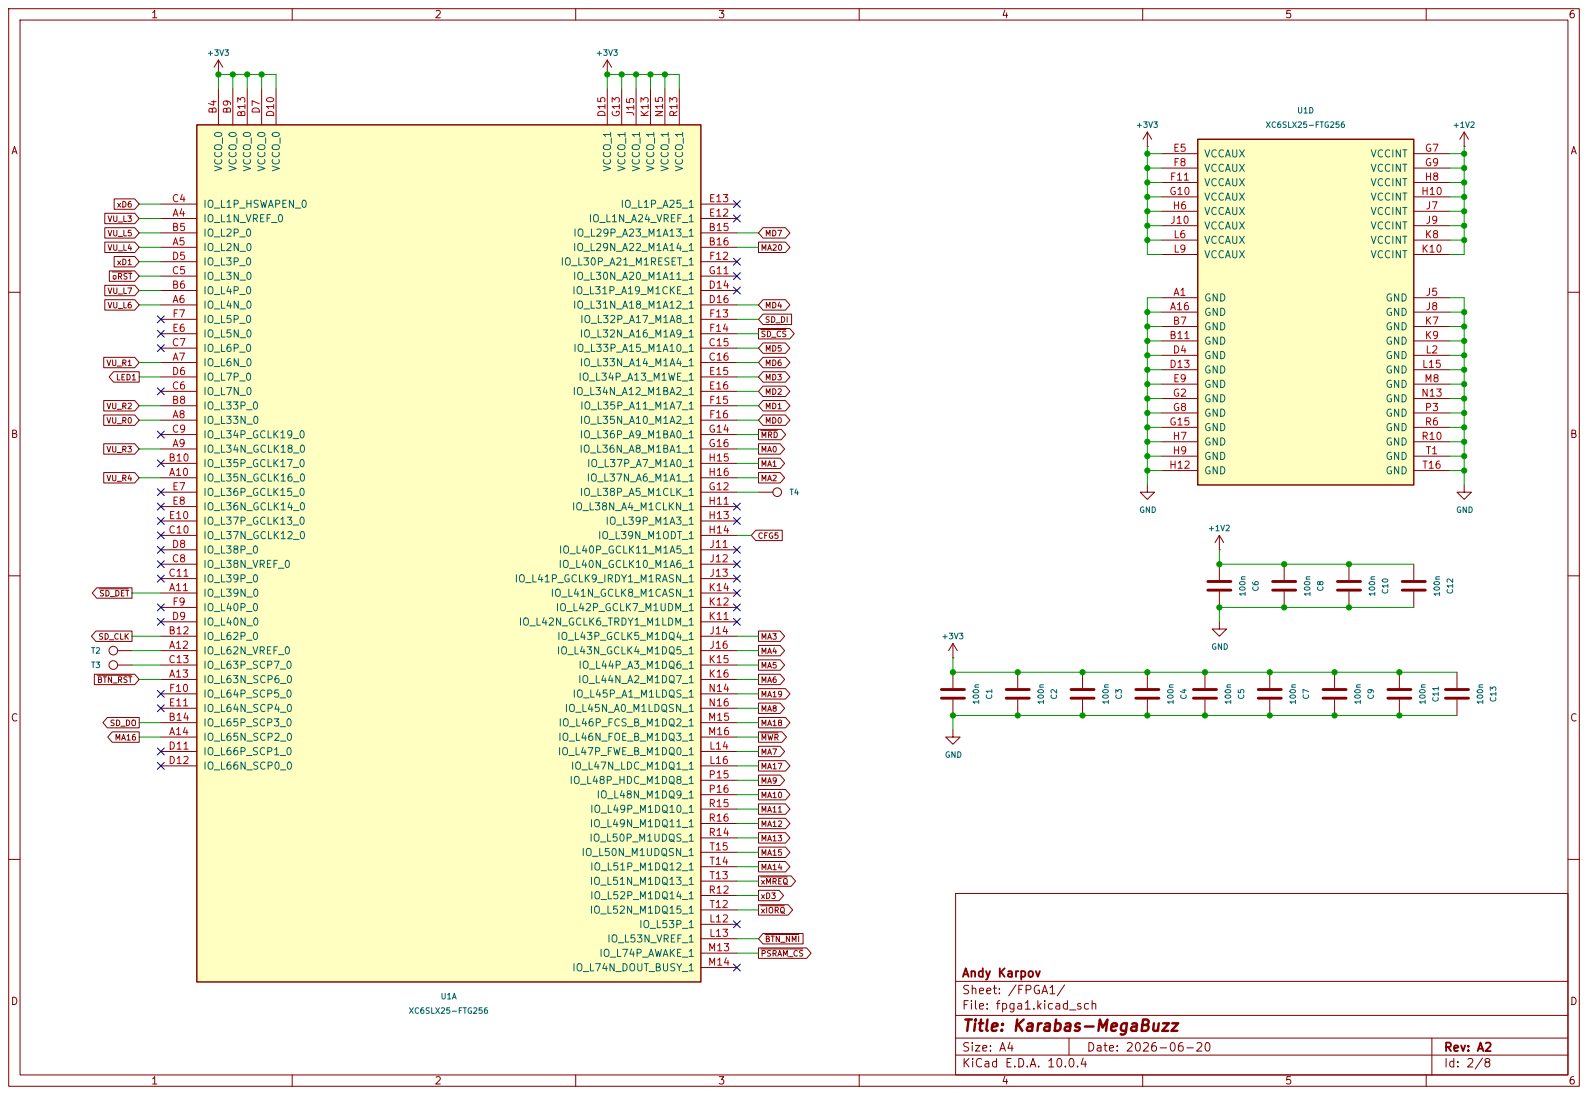
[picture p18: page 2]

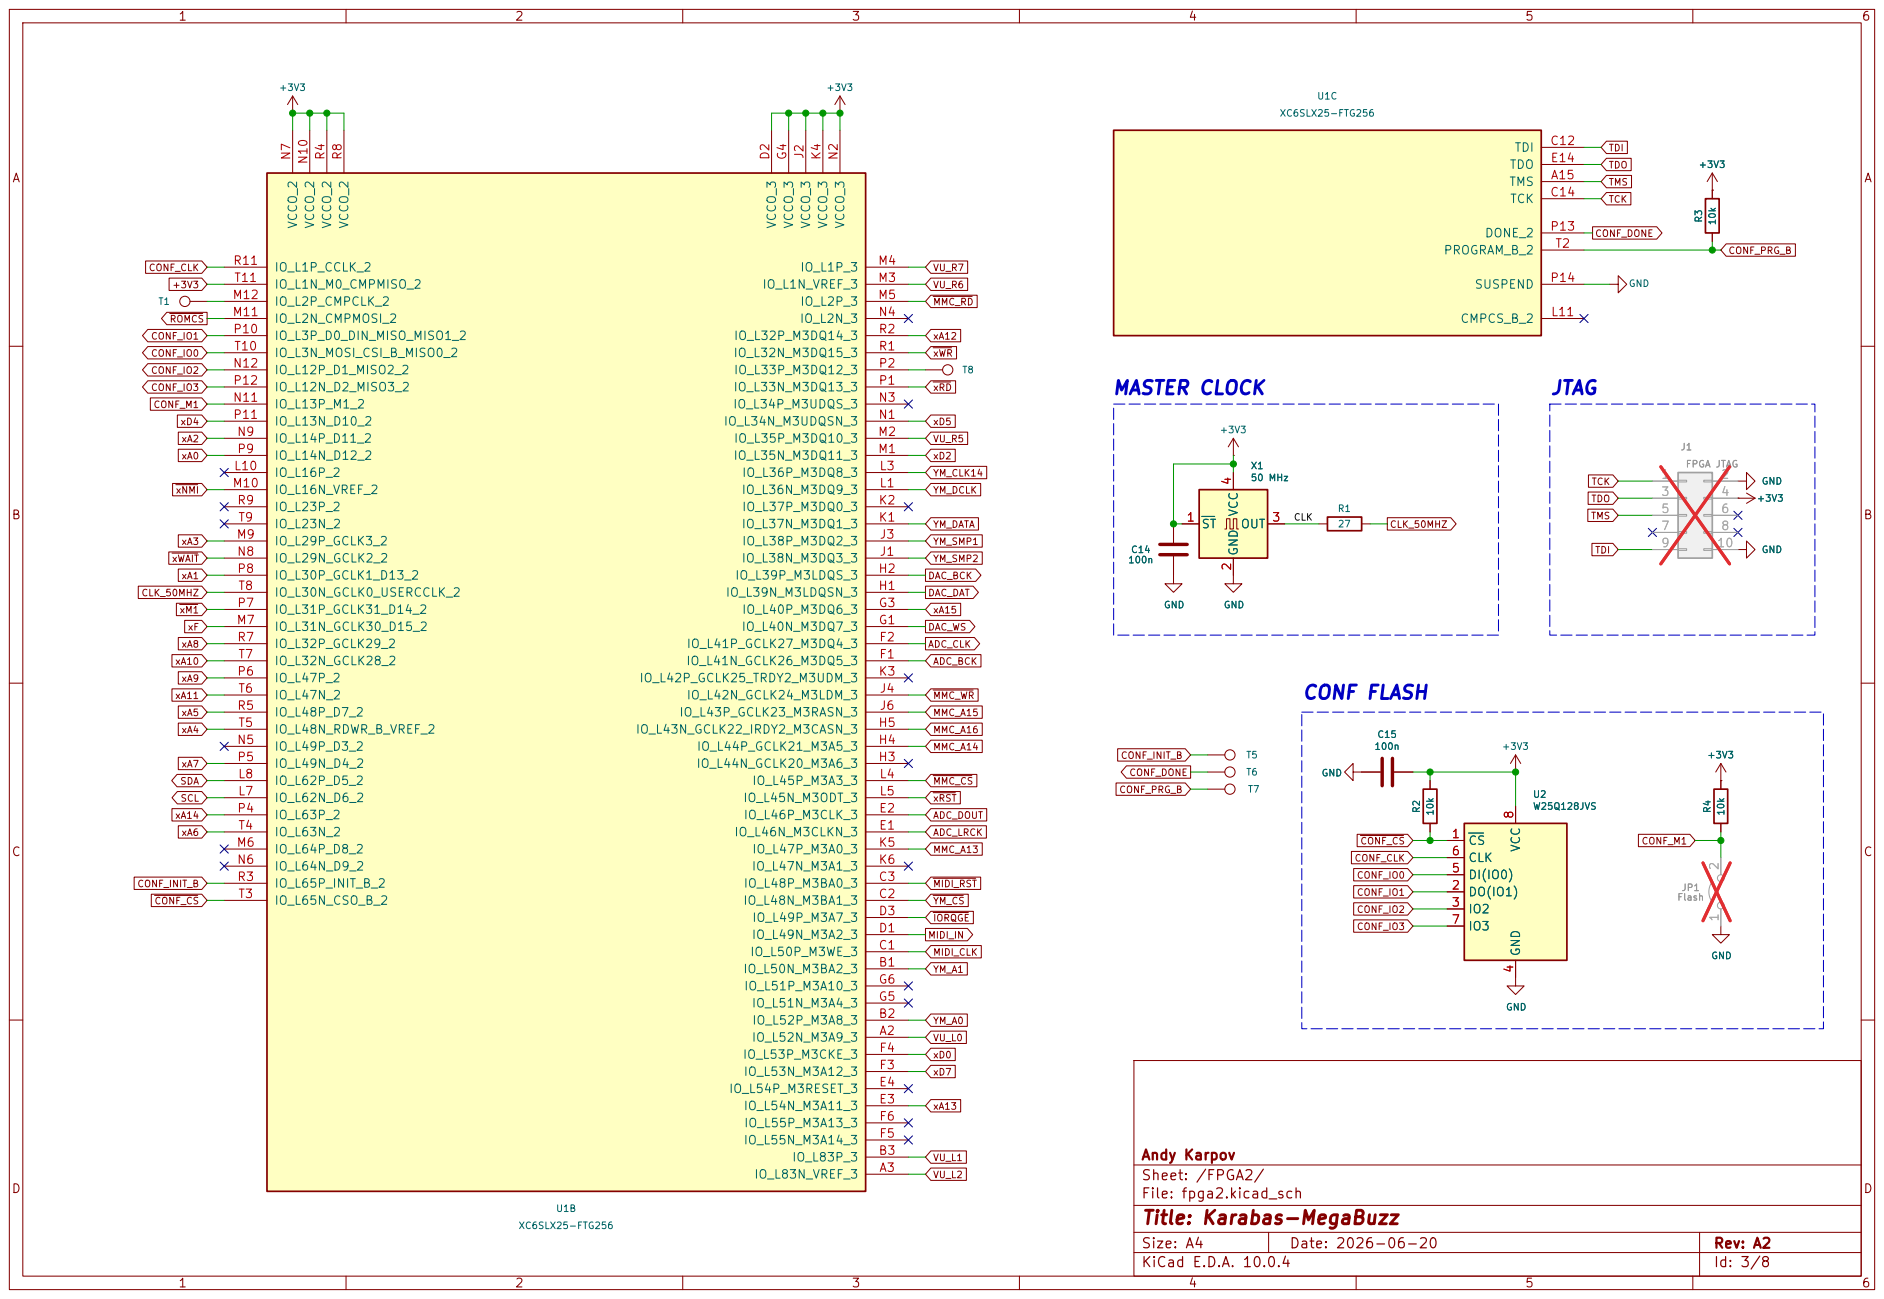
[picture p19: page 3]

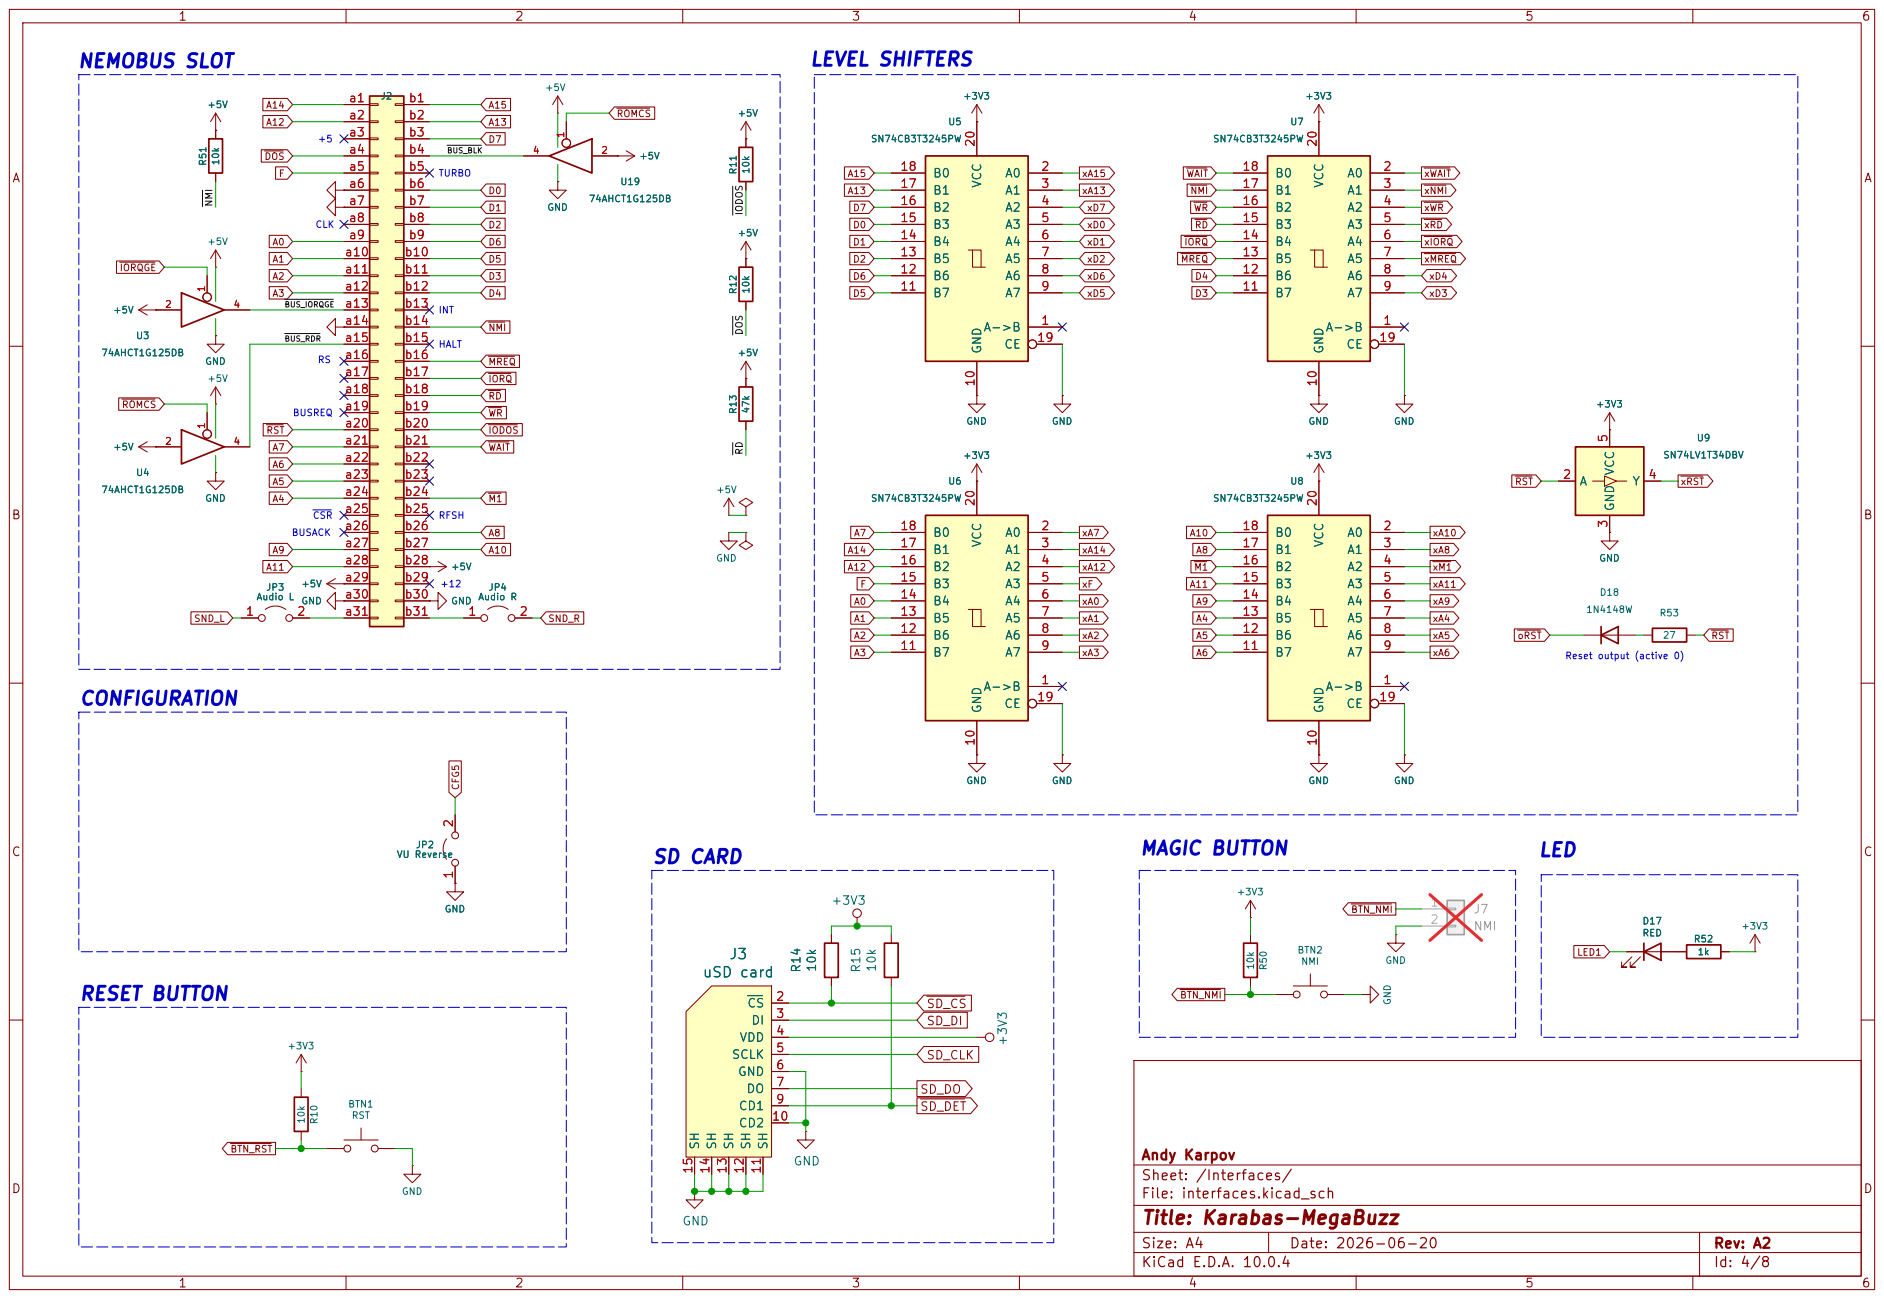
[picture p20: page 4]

Reset output (active 0) +5 CLK

uSD card
Andy Karpov CS 2 DI 3

SCLK 5 GND 6 DO 7 CD1 9 CD2 10 SH 11 SH 12 SH 13 SH 14 SH 15


U12 PCM5102A GND
SCK 12 BCK 13 DIN 14 LRCK 15




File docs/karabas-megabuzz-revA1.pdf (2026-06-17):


File: fpga1.kicad_sch Power File: power.kicad_sch

Level shifters QSPI VU Leds PSRAM

File: audio.kicad_sch Memory File: memory.kicad_sch

Sound card for ZX Spectrum (NemoBus)
Andy Karpov
Sheet: /
File: karabas-megabuzz.kicad_sch
Title: Karabas-MegaBuzz

Size: A4 | Rev: A1
KiCad E.D.A. 10.0.3 | Id: 1/8




2 2
3 3
4 4

SCLK 5 GND 6 DO 7 CD1 9 CD2 10 SH 11 SH 12 SH 13 SH 14 SH 15


SCK 12 BCK 13 DIN 14 LRCK 15




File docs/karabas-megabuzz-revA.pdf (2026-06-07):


File: fpga1.kicad_sch Memory File: memory.kicad_sch
Interfaces File: interfaces.kicad_sch Power File: power.kicad_sch

JTAG QSPI Flash SRAM

FPGAParallel Level shifters Button DIP Switches VU Leds

Sound card for ZX Spectrum (NemoBus)
Andy Karpov
Sheet: /
File: karabas-megabuzz.kicad_sch
Title: Karabas-MegaBuzz

Size: A4 | Rev: A
KiCad E.D.A. 10.0.3 | Id: 1/8





SCK 12 BCK 13 DIN 14 LRCK 15




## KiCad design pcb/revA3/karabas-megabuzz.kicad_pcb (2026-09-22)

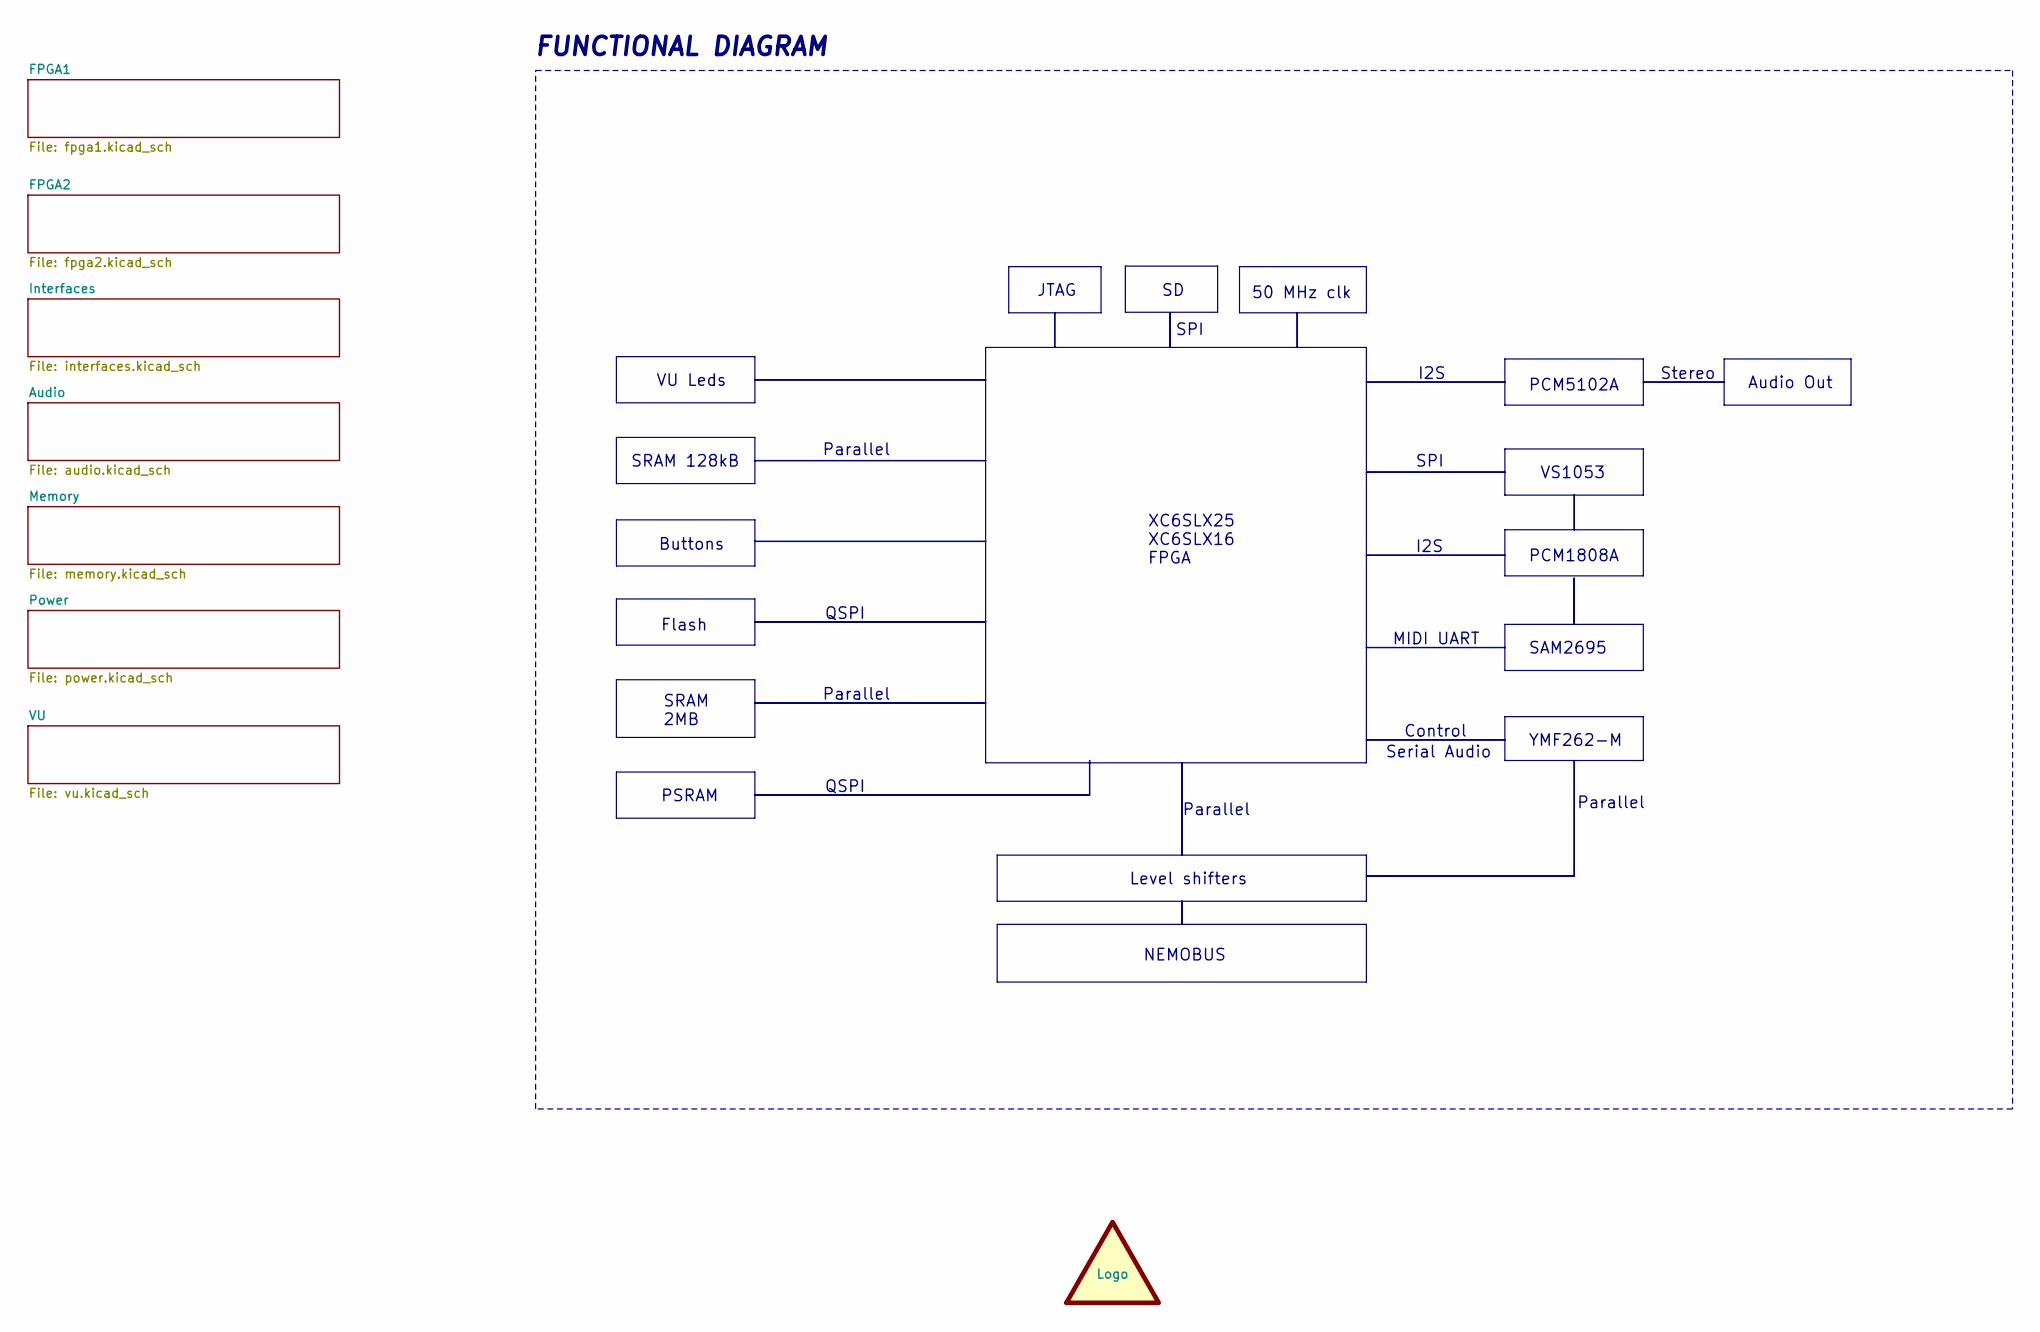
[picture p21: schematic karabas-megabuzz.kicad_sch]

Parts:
LOGO1: graphic; andy_karpov_logo5_silk

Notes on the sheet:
PCM5102A
VU Leds
XC6SLX25 XC6SLX16 FPGA
MIDI UART
Buttons
PCM1808A
VS1053
Parallel
YMF262-M
NEMOBUS
SRAM 128kB
Audio Out
I2S
QSPI
SPI
JTAG
50 MHz clk
Flash
SRAM 2MB
Level shifters
Control
Serial Audio
PSRAM
FUNCTIONAL DIAGRAM
SAM2695
Stereo

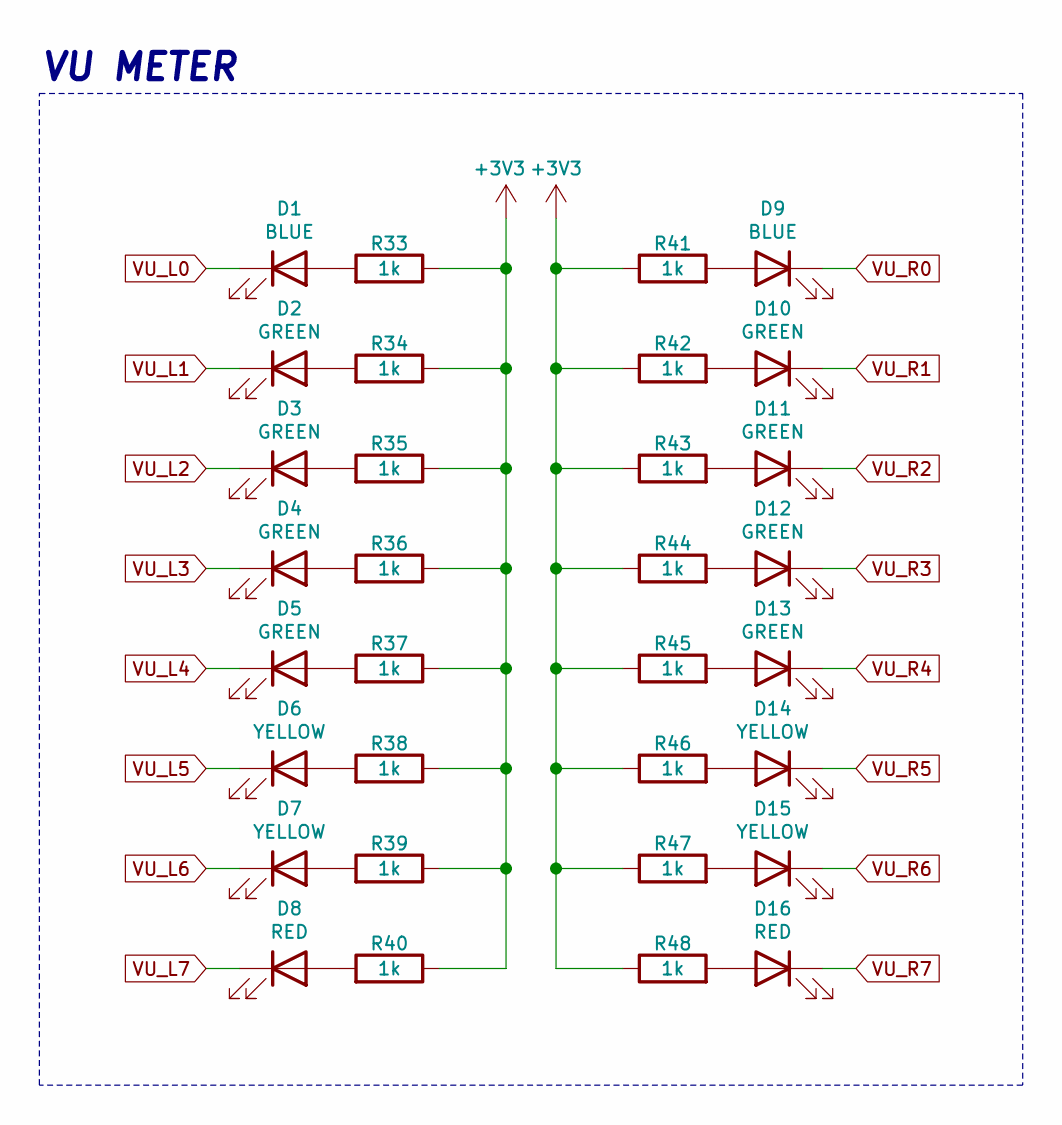
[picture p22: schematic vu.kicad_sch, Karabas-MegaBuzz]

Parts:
D1, D9: BLUE; LED_0603_1608Metric_Pad1.05x0.95mm_HandSolder
D2, D3, D4, D5, D10, D11, D12, D13: GREEN; LED_0603_1608Metric_Pad1.05x0.95mm_HandSolder
D6, D7, D14, D15: YELLOW; LED_0603_1608Metric_Pad1.05x0.95mm_HandSolder
D8, D16: RED; LED_0603_1608Metric_Pad1.05x0.95mm_HandSolder
R33, R34, R35, R36, R37, R38, R39, R40, R41, R42, R43, R44, R45, R46, R47, R48: 1k; R_0603_1608Metric_Pad0.98x0.95mm_HandSolder

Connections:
+3V3: R33.1, R34.1, R35.1, R36.1, R37.1, R38.1, R39.1, R40.1, R41.1, R42.1, R43.1, R44.1, R45.1, R46.1, R47.1, R48.1; also elsewhere on the board
unnamed: D1.2 (A), R33.2
unnamed: D2.2 (A), R34.2
unnamed: D3.2 (A), R35.2
unnamed: D4.2 (A), R36.2
unnamed: D5.2 (A), R37.2
unnamed: D6.2 (A), R38.2
unnamed: D7.2 (A), R39.2
unnamed: D8.2 (A), R40.2
unnamed: D9.2 (A), R41.2
unnamed: D10.2 (A), R42.2
unnamed: D11.2 (A), R43.2
unnamed: D12.2 (A), R44.2
unnamed: D13.2 (A), R45.2
unnamed: D14.2 (A), R46.2
unnamed: D15.2 (A), R47.2
unnamed: D16.2 (A), R48.2
VU_L0: D1.1 (K); also elsewhere on the board
VU_L1: D2.1 (K); also elsewhere on the board
VU_L2: D3.1 (K); also elsewhere on the board
VU_L3: D4.1 (K); also elsewhere on the board
VU_L4: D5.1 (K); also elsewhere on the board
VU_L5: D6.1 (K); also elsewhere on the board
VU_L6: D7.1 (K); also elsewhere on the board
VU_L7: D8.1 (K); also elsewhere on the board
VU_R0: D9.1 (K); also elsewhere on the board
VU_R1: D10.1 (K); also elsewhere on the board
VU_R2: D11.1 (K); also elsewhere on the board
VU_R3: D12.1 (K); also elsewhere on the board
VU_R4: D13.1 (K); also elsewhere on the board
VU_R5: D14.1 (K); also elsewhere on the board
VU_R6: D15.1 (K); also elsewhere on the board
VU_R7: D16.1 (K); also elsewhere on the board

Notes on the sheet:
VU METER

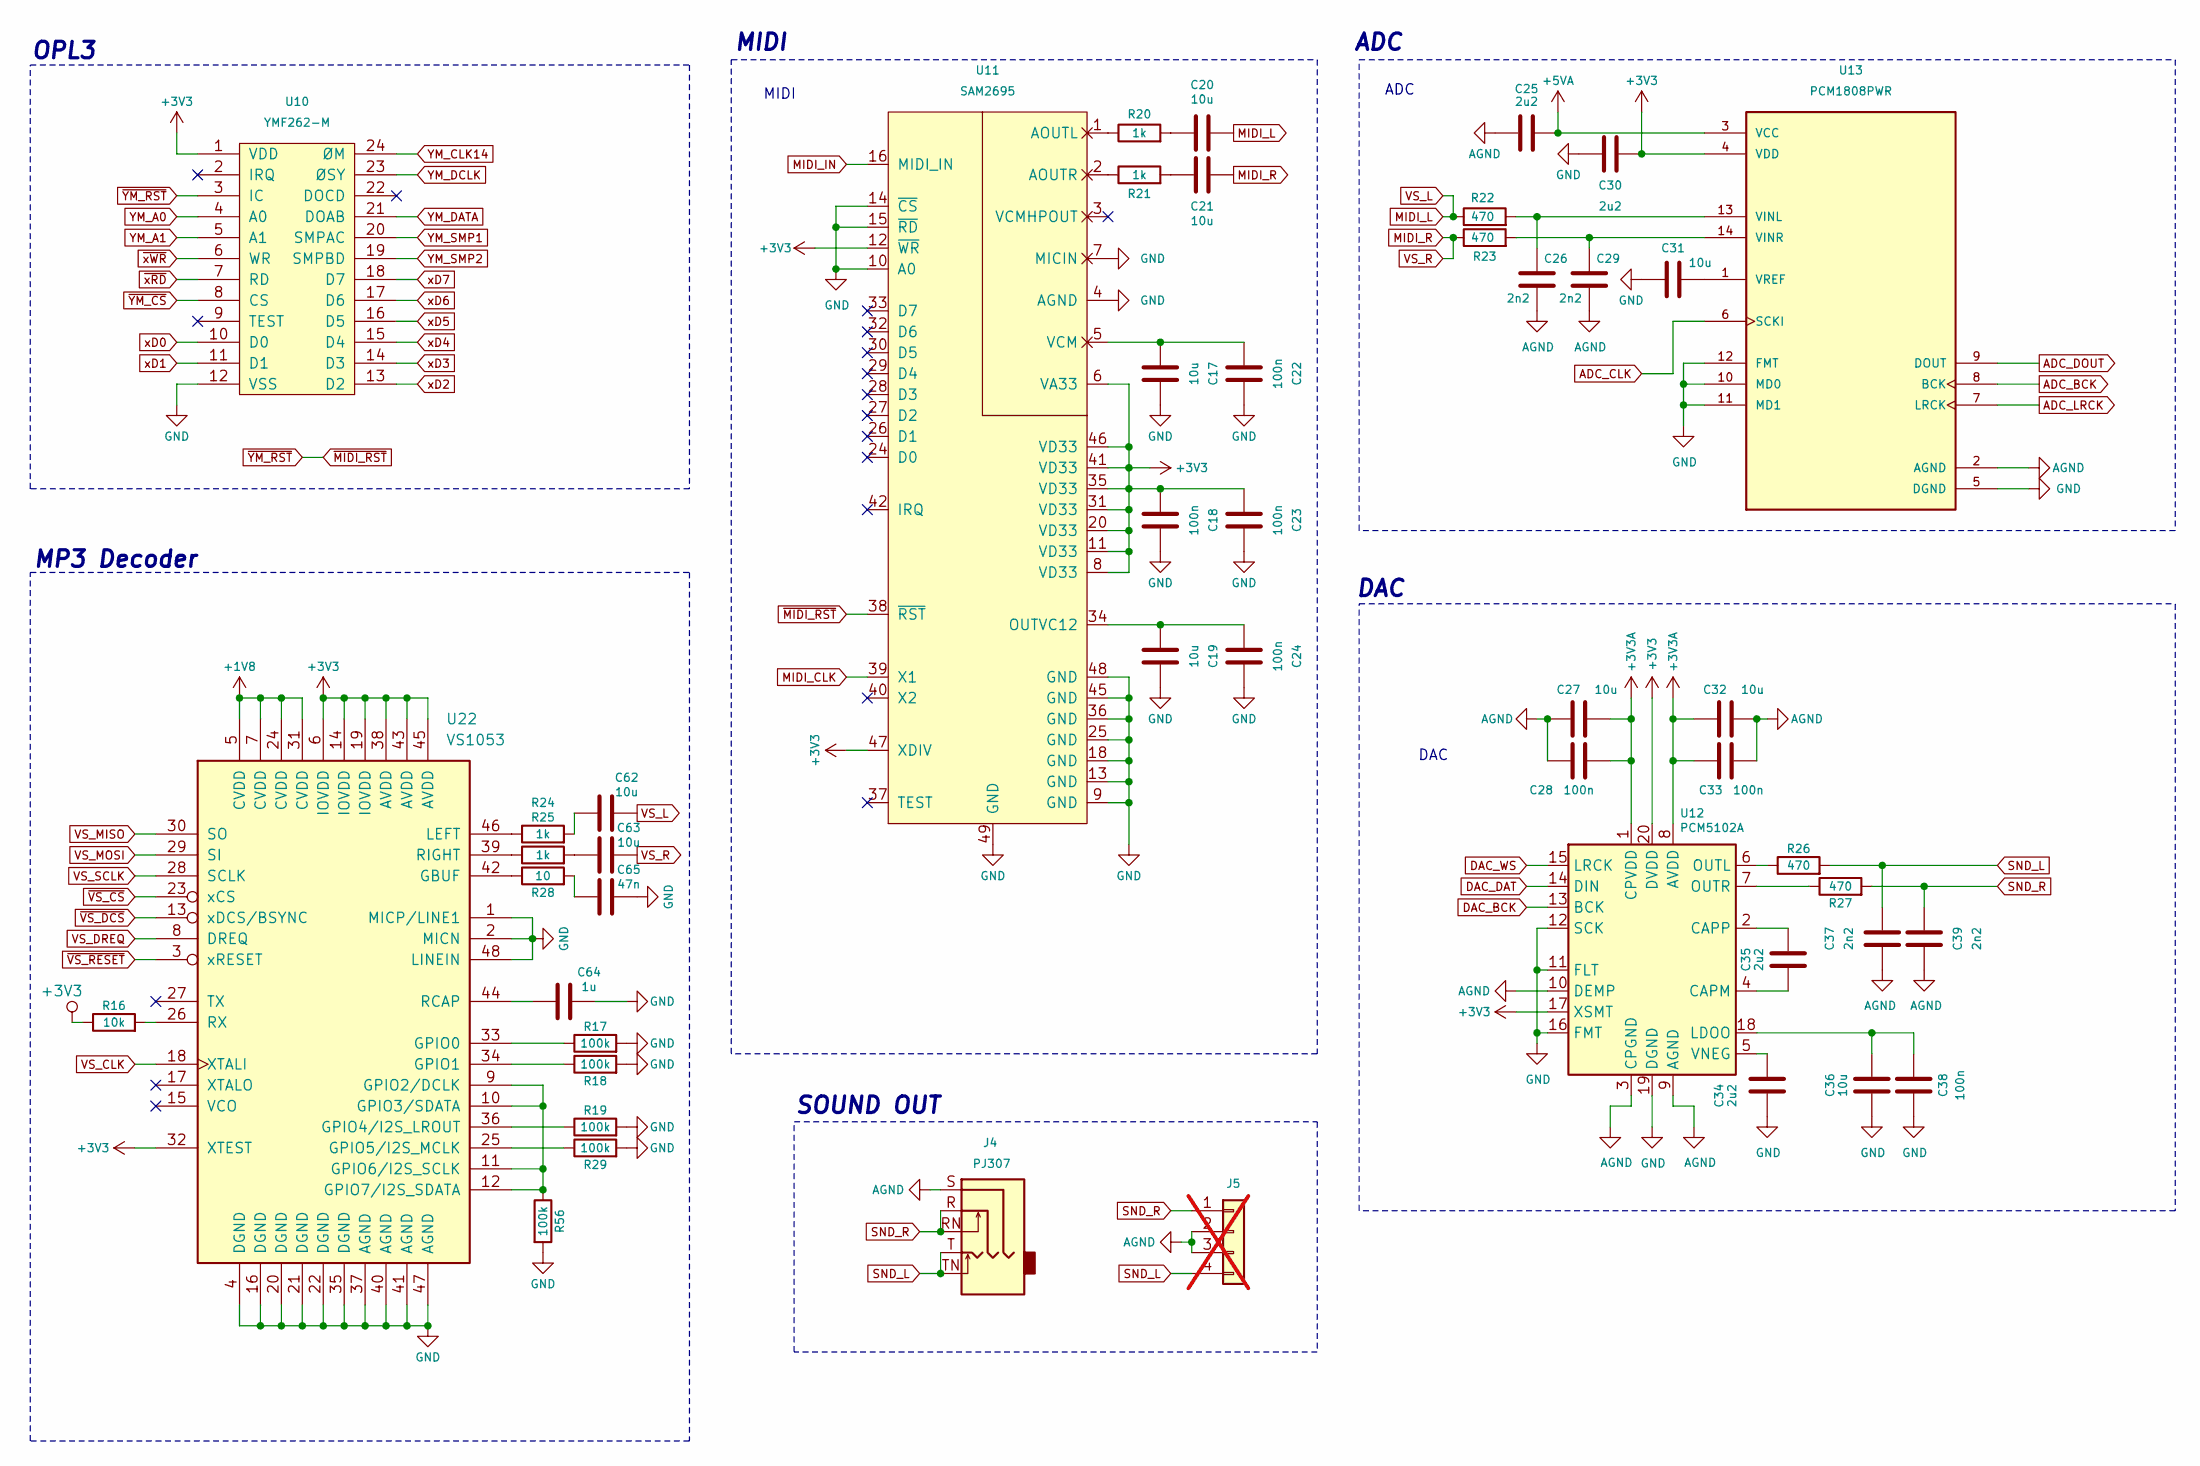
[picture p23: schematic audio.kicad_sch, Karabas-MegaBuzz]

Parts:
C17, C19, C20, C21, C27, C31, C32, C36, C62, C63: 10u; C_0603_1608Metric_Pad1.08x0.95mm_HandSolder
C18, C22, C23, C24, C28, C33, C38: 100n; C_0603_1608Metric_Pad1.08x0.95mm_HandSolder
C25, C30, C34, C35: 2u2; C_0603_1608Metric_Pad1.08x0.95mm_HandSolder
C26, C29, C37, C39: 2n2; C_0603_1608Metric_Pad1.08x0.95mm_HandSolder
C64: 1u; C_0603_1608Metric_Pad1.08x0.95mm_HandSolder
C65: 47n; C_0603_1608Metric_Pad1.08x0.95mm_HandSolder
J4: PJ307; Jack_3.5mm_CUI_SJ1-3525N_Horizontal
J5: Conn_01x04; PinHeader_1x04_P2.54mm_Vertical; not fitted
R16: 10k; R_0603_1608Metric_Pad0.98x0.95mm_HandSolder
R17, R18, R19, R29, R56: 100k; R_0603_1608Metric_Pad0.98x0.95mm_HandSolder
R20, R21, R24, R25: 1k; R_0603_1608Metric_Pad0.98x0.95mm_HandSolder
R22, R23, R26, R27: 470; R_0603_1608Metric_Pad0.98x0.95mm_HandSolder
R28: 10; R_0603_1608Metric_Pad0.98x0.95mm_HandSolder
U10: YMF262-M; ymf-262-m
U11: SAM2695; QFN-48-1EP_6x6mm_P0.4mm_EP4.2x4.2mm
U12: PCM5102A; TSSOP-20_4.4x6.5mm_P0.65mm
U13: PCM1808PWR; TSSOP-14_4.4x5mm_P0.65mm; PARTREV B
U22: VS1053; LQFP-48_7x7mm_P0.5mm

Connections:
+1V8: U22.5 (CVDD), U22.7 (CVDD), U22.24 (CVDD), U22.31 (CVDD); also elsewhere on the board
+3V3: C18.1, C23.1, C30.1, R16.1, U10.1 (VDD), U11.6 (VA33), U11.8 (VD33), U11.11 (VD33), U11.12 (~WR), U11.20 (VD33), U11.31 (VD33), U11.35 (VD33), U11.41 (VD33), U11.46 (VD33), U11.47 (XDIV), U12.17 (XSMT), U12.20 (DVDD), U13.4 (VDD), U22.6 (IOVDD), U22.14 (IOVDD), U22.19 (IOVDD), U22.32 (XTEST), U22.38 (AVDD), U22.43 (AVDD), U22.45 (AVDD); also elsewhere on the board
+3V3A: C27.1, C28.1, C32.2, C33.2, U12.1 (CPVDD), U12.8 (AVDD); also elsewhere on the board
+5VA: C25.2, U13.3 (VCC); also elsewhere on the board
ADC_BCK: U13.8 (BCK); also elsewhere on the board
ADC_CLK: U13.6 (SCKI); also elsewhere on the board
ADC_DOUT: U13.9 (DOUT); also elsewhere on the board
ADC_LRCK: U13.7 (LRCK); also elsewhere on the board
AGND: C25.1, C26.2, C27.2, C28.2, C29.2, C32.1, C33.1, C37.1, C39.1, J4.S, J5.2, J5.3, U12.3 (CPGND), U12.9 (AGND), U12.10 (DEMP), U13.2 (AGND); also elsewhere on the board
DAC_BCK: U12.13 (BCK); also elsewhere on the board
DAC_DAT: U12.14 (DIN); also elsewhere on the board
DAC_WS: U12.15 (LRCK); also elsewhere on the board
GND: C17.2, C18.2, C19.2, C22.2, C23.2, C24.2, C30.2, C31.1, C34.1, C36.1, C38.1, C64.2, C65.2, R17.2, R18.2, R19.2, R29.2, R56.2, U10.12 (VSS), U11.4 (AGND), U11.7 (MICIN), U11.9 (GND), U11.10 (A0), U11.13 (GND), U11.14 (~CS), U11.15 (~RD), U11.18 (GND), U11.25 (GND), U11.36 (GND), U11.45 (GND), U11.48 (GND), U11.49 (GND), U12.11 (FLT), U12.12 (SCK), U12.16 (FMT), U12.19 (DGND), U13.5 (DGND), U13.10 (MD0), U13.11 (MD1), U13.12 (FMT), U22.1 (MICP/LINE1), U22.2 (MICN), U22.4 (DGND), U22.16 (DGND), U22.20 (DGND), U22.21 (DGND), U22.22 (DGND), U22.35 (DGND), U22.37 (AGND), U22.40 (AGND), U22.41 (AGND), U22.47 (AGND), U22.48 (LINEIN); also elsewhere on the board
MIDI_CLK: U11.39 (X1); also elsewhere on the board
MIDI_IN: U11.16 (MIDI_IN); also elsewhere on the board
MIDI_L: C20.2, C62.2, R22.1
MIDI_R: C21.2, C63.2, R23.1
unnamed: C20.1, R20.2
unnamed: C21.1, R21.2
unnamed: C62.1, R24.2
unnamed: C63.1, R25.2
unnamed: C65.1, R28.2
unnamed: R20.1, U11.1 (AOUTL)
unnamed: R21.1, U11.2 (AOUTR)
unnamed: C19.1, C24.1, U11.34 (OUTVC12)
unnamed: C17.1, C22.1, U11.5 (VCM)
unnamed: C35.1, U12.4 (CAPM)
unnamed: C35.2, U12.2 (CAPP)
unnamed: C36.2, C38.2, U12.18 (LDOO)
unnamed: R26.1, U12.6 (OUTL)
unnamed: R27.1, U12.7 (OUTR)
unnamed: C34.2, U12.5 (VNEG)
unnamed: C26.1, R22.2, U13.13 (VINL)
unnamed: C29.1, R23.2, U13.14 (VINR)
unnamed: C31.2, U13.1 (VREF)
unnamed: R28.1, U22.42 (GBUF)
unnamed: R17.1, U22.33 (GPIO0)
unnamed: R18.1, U22.34 (GPIO1)
unnamed: R56.1, U22.9 (GPIO2/DCLK), U22.10 (GPIO3/SDATA), U22.11 (GPIO6/I2S_SCLK), U22.12 (GPIO7/I2S_SDATA)
unnamed: R19.1, U22.36 (GPIO4/I2S_LROUT)
unnamed: R29.1, U22.25 (GPIO5/I2S_MCLK)
unnamed: R24.1, U22.46 (LEFT)
unnamed: C64.1, U22.44 (RCAP)
unnamed: R25.1, U22.39 (RIGHT)
unnamed: R16.2, U22.26 (RX)
SND_L: C37.2, J4.T, J4.TN, J5.4, R26.2; also elsewhere on the board
SND_R: C39.2, J4.R, J4.RN, J5.1, R27.2; also elsewhere on the board
VS_CLK: U22.18 (XTALI); also elsewhere on the board
VS_DREQ: U22.8 (DREQ); also elsewhere on the board
VS_MISO: U22.30 (SO); also elsewhere on the board
VS_MOSI: U22.29 (SI); also elsewhere on the board
VS_SCLK: U22.28 (SCLK); also elsewhere on the board
YM_A0: U10.4 (A0); also elsewhere on the board
YM_A1: U10.5 (A1); also elsewhere on the board
YM_CLK14: U10.24 (ØM); also elsewhere on the board
YM_DATA: U10.21 (DOAB); also elsewhere on the board
YM_DCLK: U10.23 (ØSY); also elsewhere on the board
YM_SMP1: U10.20 (SMPAC); also elsewhere on the board
YM_SMP2: U10.19 (SMPBD); also elsewhere on the board
xD0: U10.10 (D0); also elsewhere on the board
xD1: U10.11 (D1); also elsewhere on the board
xD2: U10.13 (D2); also elsewhere on the board
xD3: U10.14 (D3); also elsewhere on the board
xD4: U10.15 (D4); also elsewhere on the board
xD5: U10.16 (D5); also elsewhere on the board
xD6: U10.17 (D6); also elsewhere on the board
xD7: U10.18 (D7); also elsewhere on the board
~MIDI_RST: U10.3 (IC), U11.38 (~RST); also elsewhere on the board
~VS_CS: U22.23 (xCS); also elsewhere on the board
~VS_DCS: U22.13 (xDCS/BSYNC); also elsewhere on the board
~VS_RESET: U22.3 (xRESET); also elsewhere on the board
~YM_CS: U10.8 (CS); also elsewhere on the board
~xRD: U10.7 (RD); also elsewhere on the board
~xWR: U10.6 (WR); also elsewhere on the board

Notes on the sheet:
SOUND OUT
MP3 Decoder
ADC
MIDI
DAC
OPL3

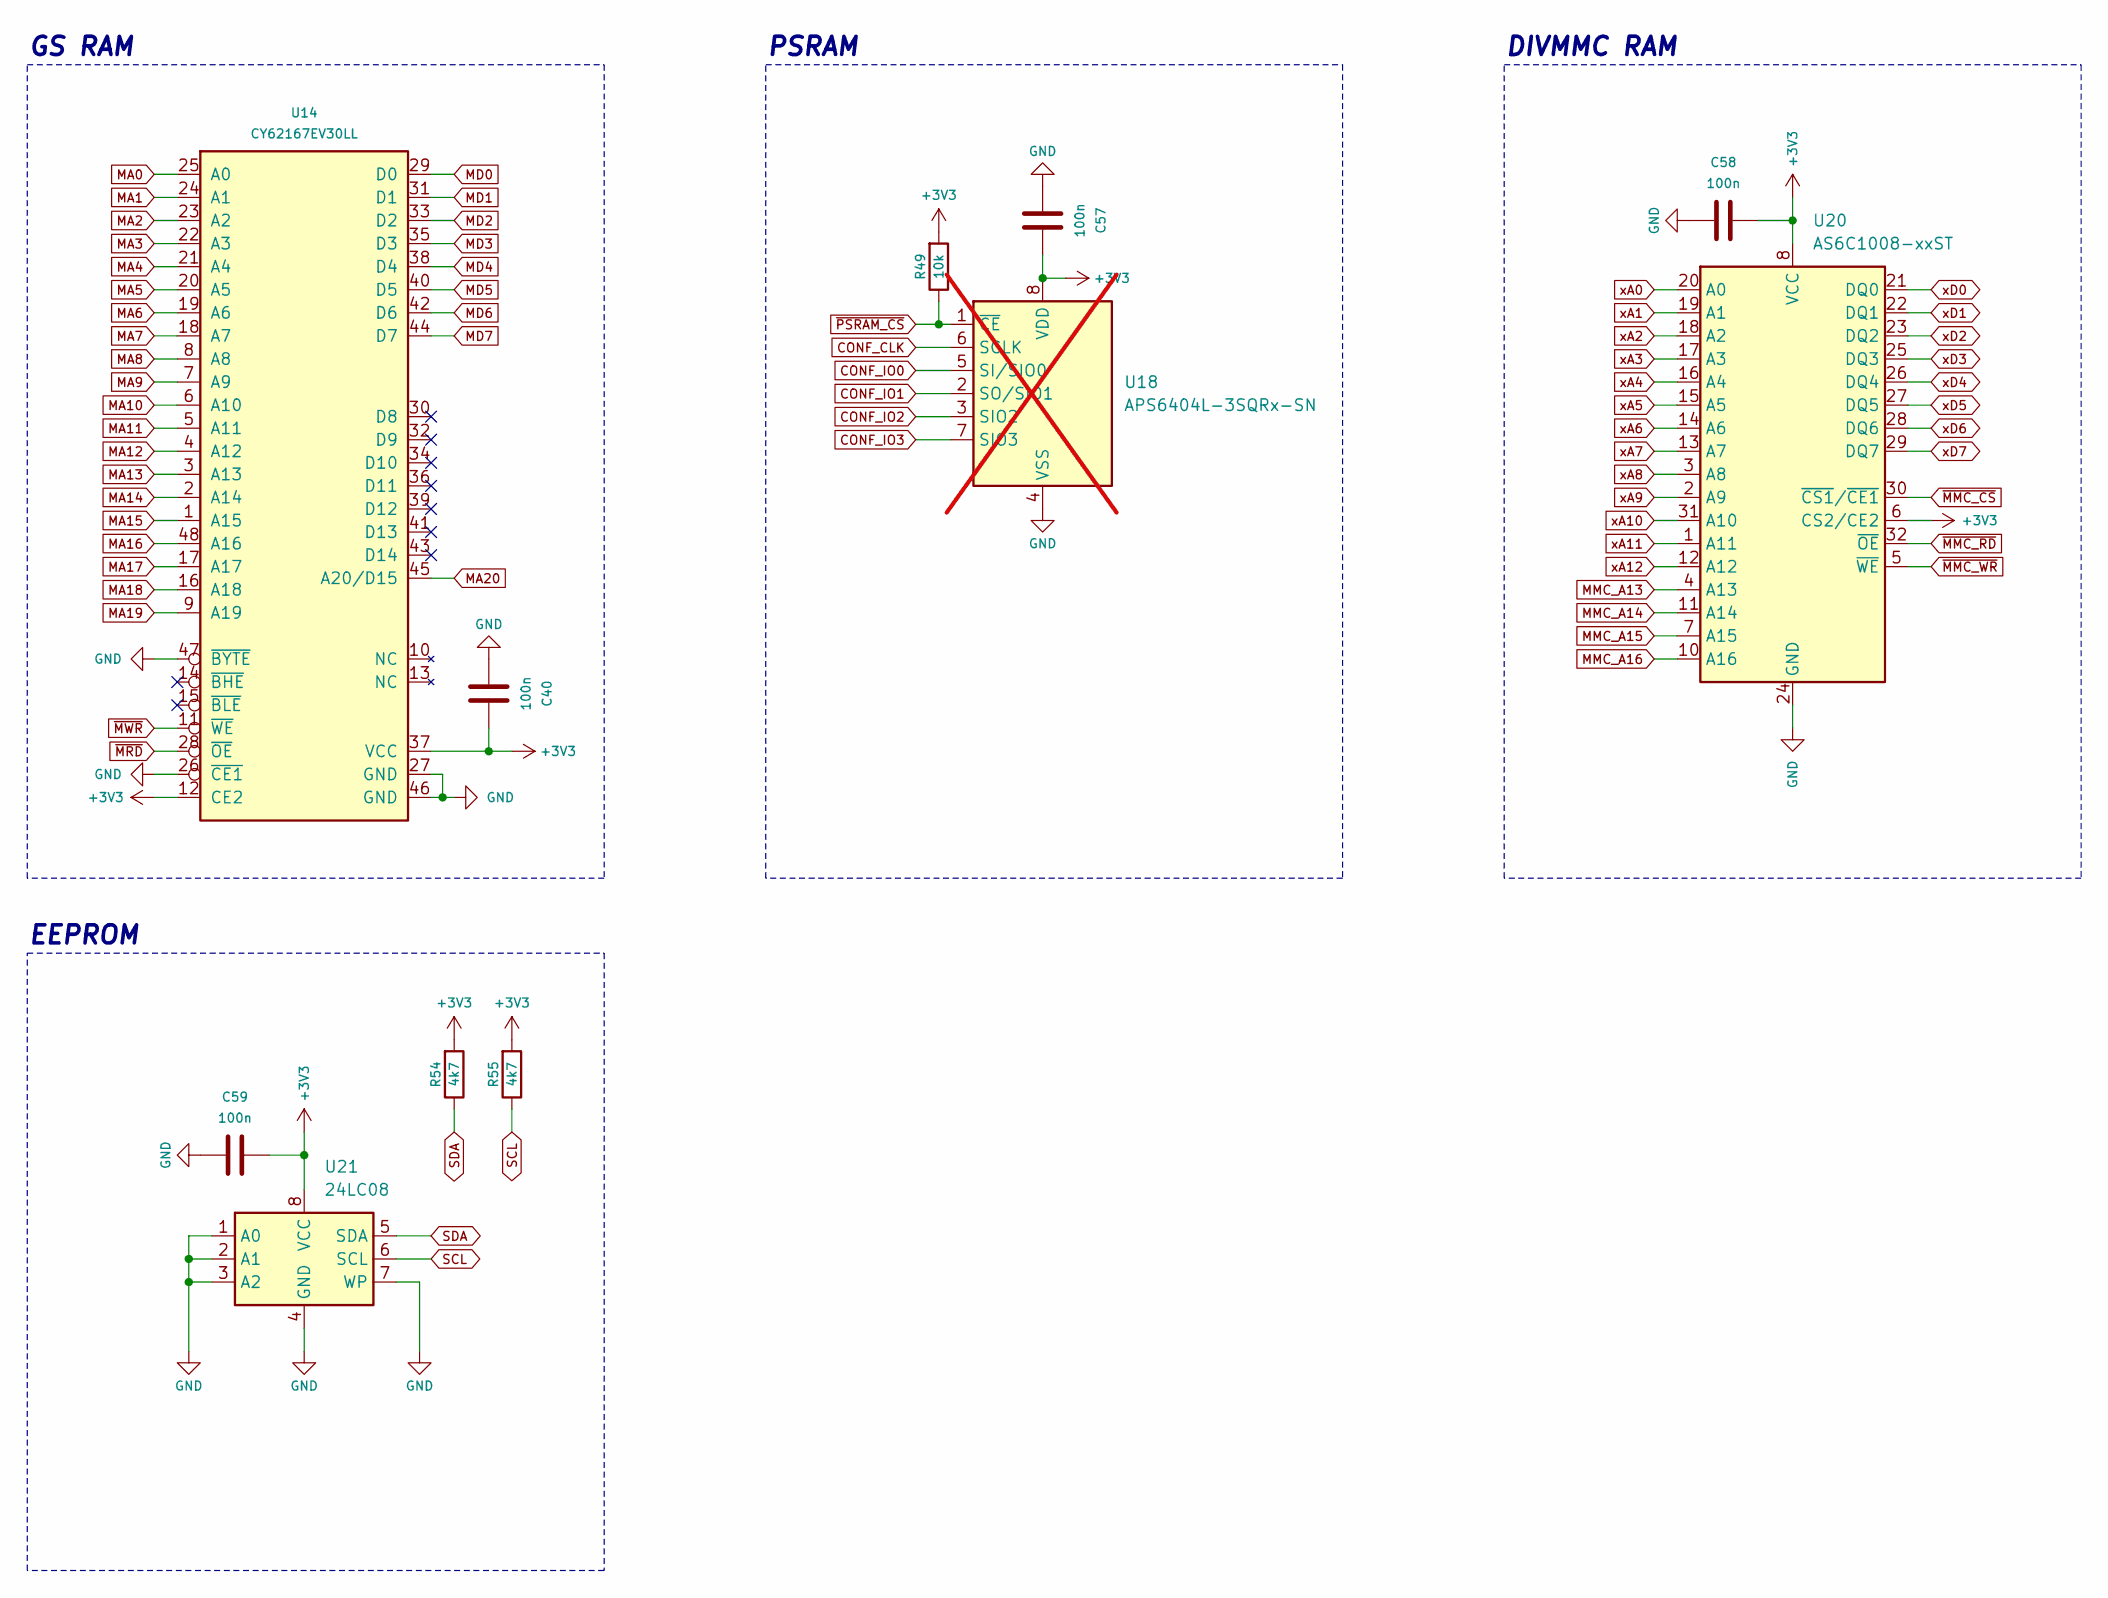
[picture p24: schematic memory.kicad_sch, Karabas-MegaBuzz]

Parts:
C40, C57, C58, C59: 100n; C_0603_1608Metric_Pad1.08x0.95mm_HandSolder
R49: 10k; R_0603_1608Metric_Pad0.98x0.95mm_HandSolder
R54, R55: 4k7; R_0603_1608Metric_Pad0.98x0.95mm_HandSolder
U14: CY62167EV30LL; TSOP-I-48_18.4x12mm_P0.5mm
U18: APS6404L-3SQRx-SN; SOIC-8_3.9x4.9mm_P1.27mm; not fitted
U20: AS6C1008-xxST; TSOP-I-32_11.8x8mm_P0.5mm
U21: 24LC08; SOIC-8_3.9x4.9mm_P1.27mm

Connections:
+3V3: C40.2, C57.2, C58.2, C59.2, R49.2, R54.2, R55.2, U14.12 (CE2), U14.37 (VCC), U18.8 (VDD), U20.6 (CS2/CE2), U20.8 (VCC), U21.8 (VCC); also elsewhere on the board
CONF_CLK: U18.6 (SCLK); also elsewhere on the board
CONF_IO0: U18.5 (SI/SIO0); also elsewhere on the board
CONF_IO1: U18.2 (SO/SIO1); also elsewhere on the board
CONF_IO2: U18.3 (SIO2); also elsewhere on the board
CONF_IO3: U18.7 (SIO3); also elsewhere on the board
GND: C40.1, C57.1, C58.1, C59.1, U14.26 (~CE1), U14.27 (GND), U14.46 (GND), U14.47 (~BYTE), U18.4 (VSS), U20.24 (GND), U21.1 (A0), U21.2 (A1), U21.3 (A2), U21.4 (GND), U21.7 (WP); also elsewhere on the board
MA0: U14.25 (A0); also elsewhere on the board
MA1: U14.24 (A1); also elsewhere on the board
MA2: U14.23 (A2); also elsewhere on the board
MA3: U14.22 (A3); also elsewhere on the board
MA4: U14.21 (A4); also elsewhere on the board
MA5: U14.20 (A5); also elsewhere on the board
MA6: U14.19 (A6); also elsewhere on the board
MA7: U14.18 (A7); also elsewhere on the board
MA8: U14.8 (A8); also elsewhere on the board
MA9: U14.7 (A9); also elsewhere on the board
MA10: U14.6 (A10); also elsewhere on the board
MA11: U14.5 (A11); also elsewhere on the board
MA12: U14.4 (A12); also elsewhere on the board
MA13: U14.3 (A13); also elsewhere on the board
MA14: U14.2 (A14); also elsewhere on the board
MA15: U14.1 (A15); also elsewhere on the board
MA16: U14.48 (A16); also elsewhere on the board
MA17: U14.17 (A17); also elsewhere on the board
MA18: U14.16 (A18); also elsewhere on the board
MA19: U14.9 (A19); also elsewhere on the board
MA20: U14.45 (A20/D15); also elsewhere on the board
MD0: U14.29 (D0); also elsewhere on the board
MD1: U14.31 (D1); also elsewhere on the board
MD2: U14.33 (D2); also elsewhere on the board
MD3: U14.35 (D3); also elsewhere on the board
MD4: U14.38 (D4); also elsewhere on the board
MD5: U14.40 (D5); also elsewhere on the board
MD6: U14.42 (D6); also elsewhere on the board
MD7: U14.44 (D7); also elsewhere on the board
MMC_A13: U20.4 (A13); also elsewhere on the board
MMC_A14: U20.11 (A14); also elsewhere on the board
MMC_A15: U20.7 (A15); also elsewhere on the board
MMC_A16: U20.10 (A16); also elsewhere on the board
SCL: R55.1, U21.6 (SCL); also elsewhere on the board
SDA: R54.1, U21.5 (SDA); also elsewhere on the board
xA0: U20.20 (A0); also elsewhere on the board
xA1: U20.19 (A1); also elsewhere on the board
xA2: U20.18 (A2); also elsewhere on the board
xA3: U20.17 (A3); also elsewhere on the board
xA4: U20.16 (A4); also elsewhere on the board
xA5: U20.15 (A5); also elsewhere on the board
xA6: U20.14 (A6); also elsewhere on the board
xA7: U20.13 (A7); also elsewhere on the board
xA8: U20.3 (A8); also elsewhere on the board
xA9: U20.2 (A9); also elsewhere on the board
xA10: U20.31 (A10); also elsewhere on the board
xA11: U20.1 (A11); also elsewhere on the board
xA12: U20.12 (A12); also elsewhere on the board
xD0: U20.21 (DQ0); also elsewhere on the board
xD1: U20.22 (DQ1); also elsewhere on the board
xD2: U20.23 (DQ2); also elsewhere on the board
xD3: U20.25 (DQ3); also elsewhere on the board
xD4: U20.26 (DQ4); also elsewhere on the board
xD5: U20.27 (DQ5); also elsewhere on the board
xD6: U20.28 (DQ6); also elsewhere on the board
xD7: U20.29 (DQ7); also elsewhere on the board
~MMC_CS: U20.30 (~CS1/~CE1); also elsewhere on the board
~MMC_RD: U20.32 (~OE); also elsewhere on the board
~MMC_WR: U20.5 (~WE); also elsewhere on the board
~MRD: U14.28 (~OE); also elsewhere on the board
~MWR: U14.11 (~WE); also elsewhere on the board
~PSRAM_CS: R49.1, U18.1 (~CE); also elsewhere on the board

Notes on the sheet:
PSRAM
GS RAM
DIVMMC RAM
EEPROM

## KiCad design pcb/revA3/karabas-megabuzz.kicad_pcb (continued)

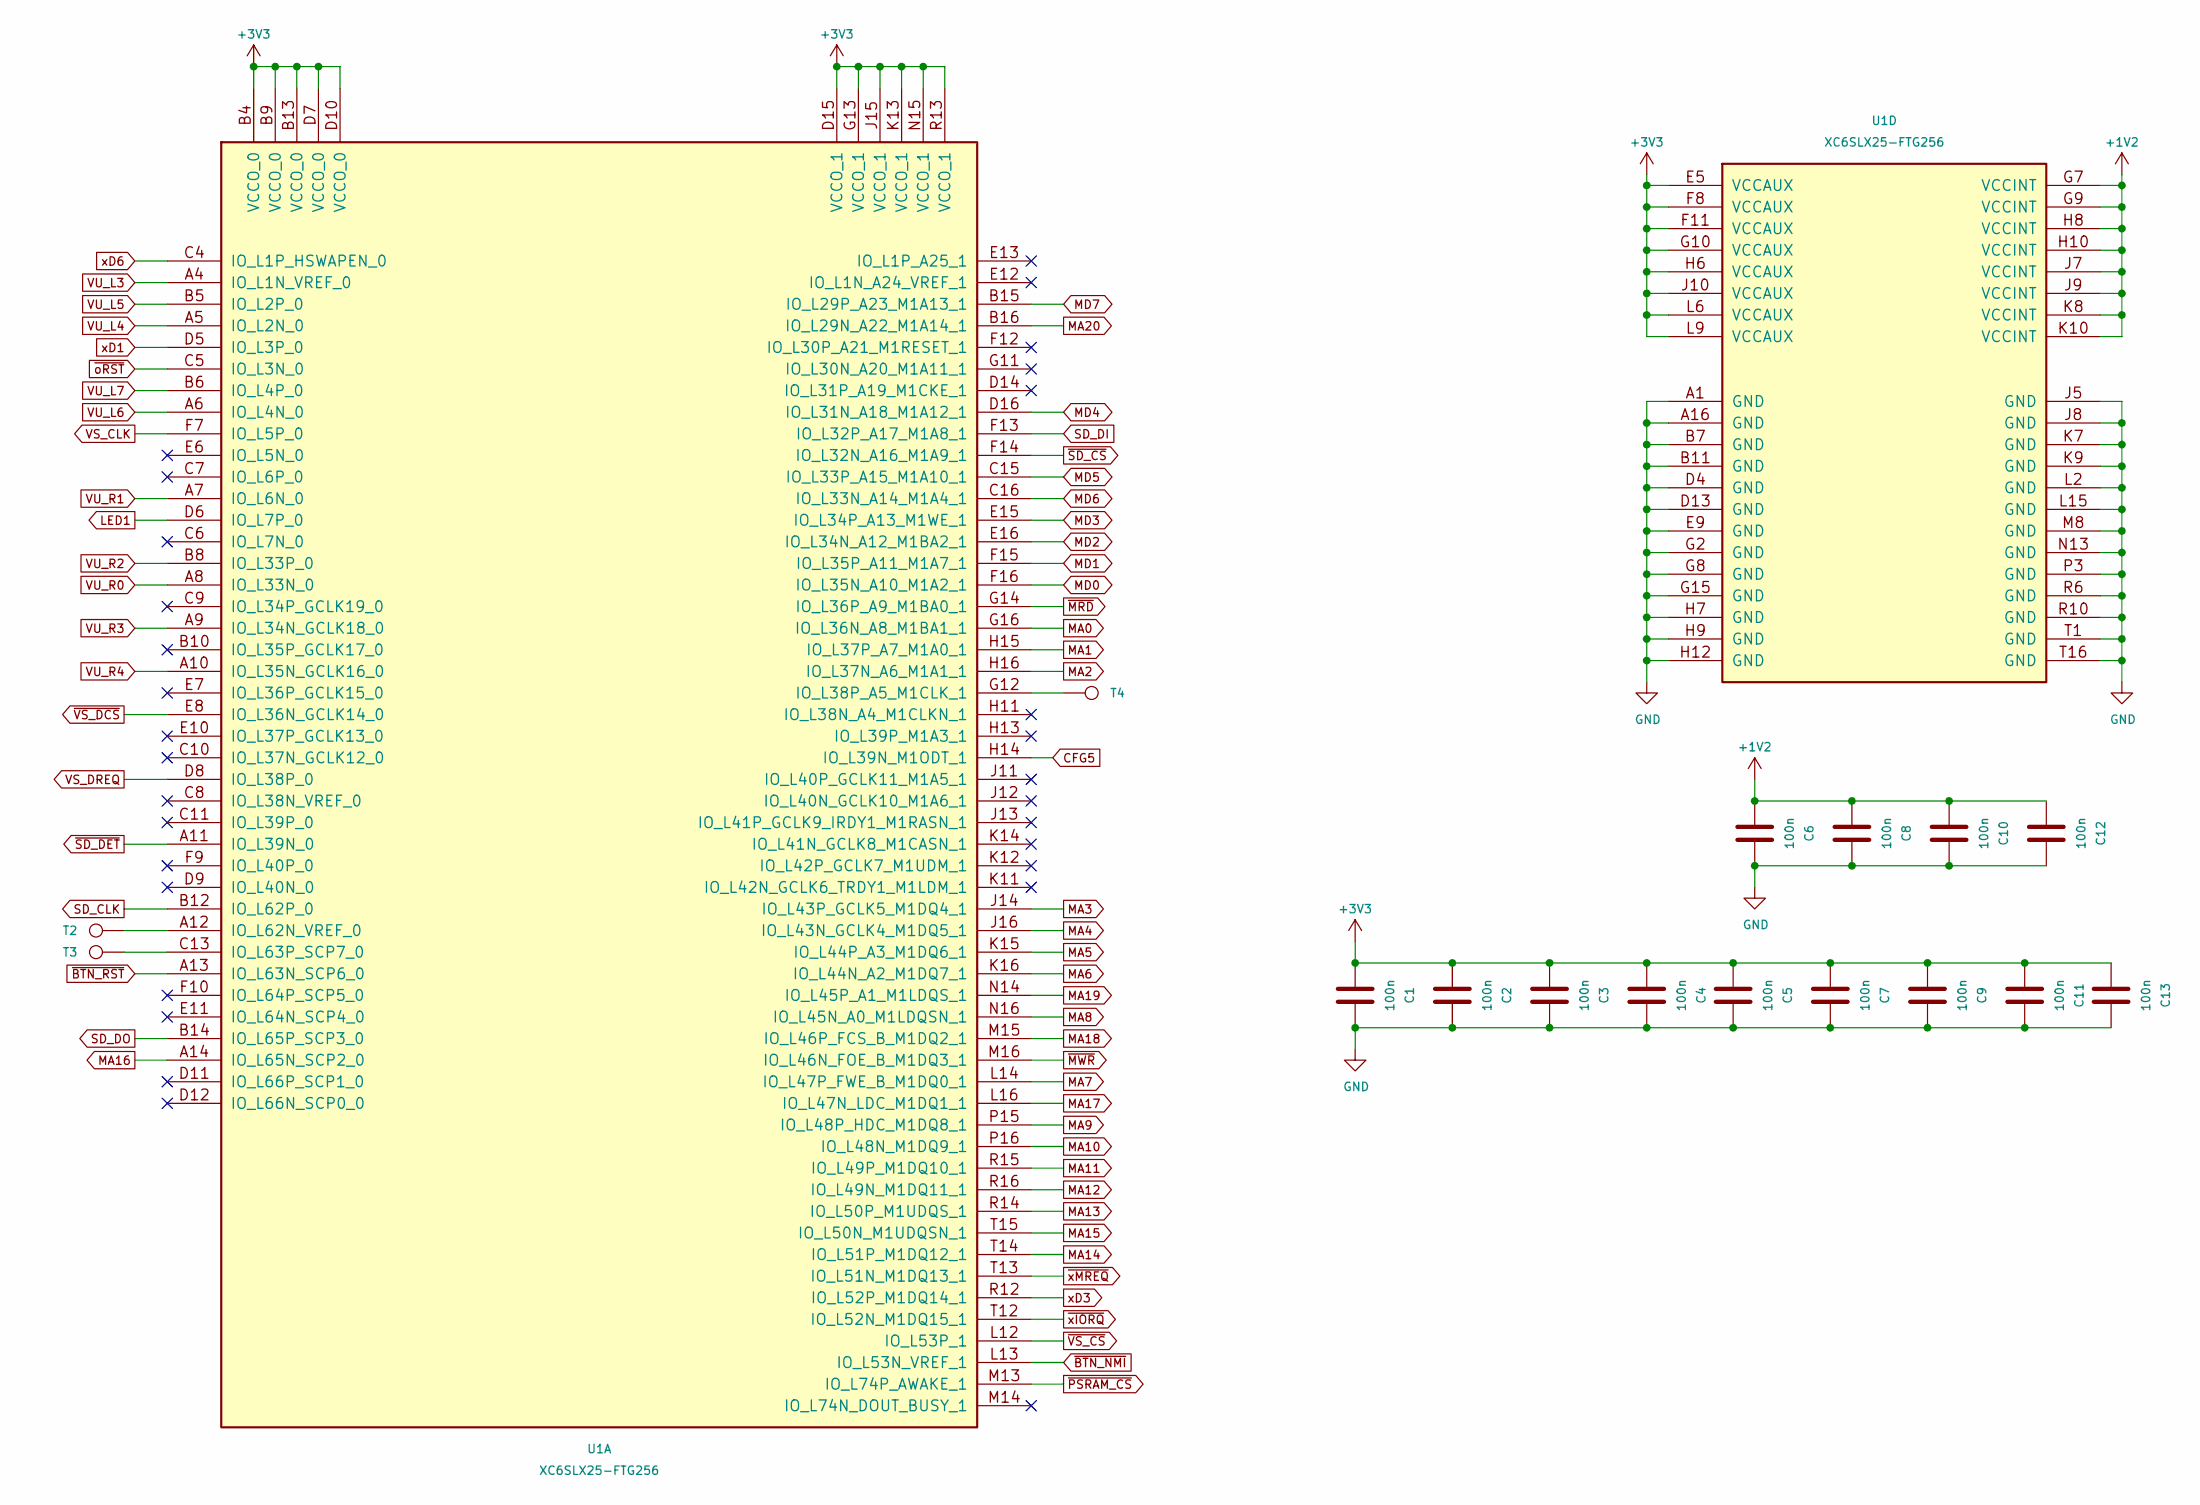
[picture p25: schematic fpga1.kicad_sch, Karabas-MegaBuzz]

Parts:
C1, C2, C3, C4, C5, C7, C9, C11, C13: 100n; C_0603_1608Metric_Pad1.08x0.95mm_HandSolder
C6, C8, C10, C12: 100n; C_0603_1608Metric
T2: TestPoint2; TestPoint_Pad_D1.5mm
T3, T4: TestPoint; TestPoint_Pad_D1.5mm
U1: XC6SLX25-FTG256; BGA-256_17.0x17.0mm_Layout16x16_P1.0mm_Ball0.5mm_Pad0.4mm_N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

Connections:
+1V2: C6.1, C8.1, C10.1, C12.1, U1.G7 (VCCINT), U1.G9 (VCCINT), U1.H8 (VCCINT), U1.H10 (VCCINT), U1.J7 (VCCINT), U1.J9 (VCCINT), U1.K8 (VCCINT), U1.K10 (VCCINT); also elsewhere on the board
+3V3: C1.1, C2.1, C3.1, C4.1, C5.1, C7.1, C9.1, C11.1, C13.1, U1.B4 (VCCO_0), U1.B9 (VCCO_0), U1.B13 (VCCO_0), U1.D7 (VCCO_0), U1.D10 (VCCO_0), U1.D15 (VCCO_1), U1.E5 (VCCAUX), U1.F8 (VCCAUX), U1.F11 (VCCAUX), U1.G10 (VCCAUX), U1.G13 (VCCO_1), U1.H6 (VCCAUX), U1.J10 (VCCAUX), U1.J15 (VCCO_1), U1.K13 (VCCO_1), U1.L6 (VCCAUX), U1.L9 (VCCAUX), U1.N15 (VCCO_1), U1.R13 (VCCO_1); also elsewhere on the board
CFG5: U1.H14 (IO_L39N_M1ODT_1); also elsewhere on the board
GND: C1.2, C2.2, C3.2, C4.2, C5.2, C6.2, C7.2, C8.2, C9.2, C10.2, C11.2, C12.2, C13.2, U1.A1 (GND), U1.A16 (GND), U1.B7 (GND), U1.B11 (GND), U1.D4 (GND), U1.D13 (GND), U1.E9 (GND), U1.G2 (GND), U1.G8 (GND), U1.G15 (GND), U1.H7 (GND), U1.H9 (GND), U1.H12 (GND), U1.J5 (GND), U1.J8 (GND), U1.K7 (GND), U1.K9 (GND), U1.L2 (GND), U1.L15 (GND), U1.M8 (GND), U1.N13 (GND), U1.P3 (GND), U1.R6 (GND), U1.R10 (GND), U1.T1 (GND), U1.T16 (GND); also elsewhere on the board
LED1: U1.D6 (IO_L7P_0); also elsewhere on the board
MA0: U1.G16 (IO_L36N_A8_M1BA1_1); also elsewhere on the board
MA1: U1.H15 (IO_L37P_A7_M1A0_1); also elsewhere on the board
MA2: U1.H16 (IO_L37N_A6_M1A1_1); also elsewhere on the board
MA3: U1.J14 (IO_L43P_GCLK5_M1DQ4_1); also elsewhere on the board
MA4: U1.J16 (IO_L43N_GCLK4_M1DQ5_1); also elsewhere on the board
MA5: U1.K15 (IO_L44P_A3_M1DQ6_1); also elsewhere on the board
MA6: U1.K16 (IO_L44N_A2_M1DQ7_1); also elsewhere on the board
MA7: U1.L14 (IO_L47P_FWE_B_M1DQ0_1); also elsewhere on the board
MA8: U1.N16 (IO_L45N_A0_M1LDQSN_1); also elsewhere on the board
MA9: U1.P15 (IO_L48P_HDC_M1DQ8_1); also elsewhere on the board
MA10: U1.P16 (IO_L48N_M1DQ9_1); also elsewhere on the board
MA11: U1.R15 (IO_L49P_M1DQ10_1); also elsewhere on the board
MA12: U1.R16 (IO_L49N_M1DQ11_1); also elsewhere on the board
MA13: U1.R14 (IO_L50P_M1UDQS_1); also elsewhere on the board
MA14: U1.T14 (IO_L51P_M1DQ12_1); also elsewhere on the board
MA15: U1.T15 (IO_L50N_M1UDQSN_1); also elsewhere on the board
MA16: U1.A14 (IO_L65N_SCP2_0); also elsewhere on the board
MA17: U1.L16 (IO_L47N_LDC_M1DQ1_1); also elsewhere on the board
MA18: U1.M15 (IO_L46P_FCS_B_M1DQ2_1); also elsewhere on the board
MA19: U1.N14 (IO_L45P_A1_M1LDQS_1); also elsewhere on the board
MA20: U1.B16 (IO_L29N_A22_M1A14_1); also elsewhere on the board
MD0: U1.F16 (IO_L35N_A10_M1A2_1); also elsewhere on the board
MD1: U1.F15 (IO_L35P_A11_M1A7_1); also elsewhere on the board
MD2: U1.E16 (IO_L34N_A12_M1BA2_1); also elsewhere on the board
MD3: U1.E15 (IO_L34P_A13_M1WE_1); also elsewhere on the board
MD4: U1.D16 (IO_L31N_A18_M1A12_1); also elsewhere on the board
MD5: U1.C15 (IO_L33P_A15_M1A10_1); also elsewhere on the board
MD6: U1.C16 (IO_L33N_A14_M1A4_1); also elsewhere on the board
MD7: U1.B15 (IO_L29P_A23_M1A13_1); also elsewhere on the board
unnamed: T4.1 (1_1), U1.G12 (IO_L38P_A5_M1CLK_1)
unnamed: T2.1 (1_1), U1.A12 (IO_L62N_VREF_0)
unnamed: T3.1 (1_1), U1.C13 (IO_L63P_SCP7_0)
SD_CLK: U1.B12 (IO_L62P_0); also elsewhere on the board
SD_DI: U1.F13 (IO_L32P_A17_M1A8_1); also elsewhere on the board
SD_DO: U1.B14 (IO_L65P_SCP3_0); also elsewhere on the board
VS_CLK: U1.F7 (IO_L5P_0); also elsewhere on the board
VS_DREQ: U1.D8 (IO_L38P_0); also elsewhere on the board
VU_L3: U1.A4 (IO_L1N_VREF_0); also elsewhere on the board
VU_L4: U1.A5 (IO_L2N_0); also elsewhere on the board
VU_L5: U1.B5 (IO_L2P_0); also elsewhere on the board
VU_L6: U1.A6 (IO_L4N_0); also elsewhere on the board
VU_L7: U1.B6 (IO_L4P_0); also elsewhere on the board
VU_R0: U1.A8 (IO_L33N_0); also elsewhere on the board
VU_R1: U1.A7 (IO_L6N_0); also elsewhere on the board
VU_R2: U1.B8 (IO_L33P_0); also elsewhere on the board
VU_R3: U1.A9 (IO_L34N_GCLK18_0); also elsewhere on the board
VU_R4: U1.A10 (IO_L35N_GCLK16_0); also elsewhere on the board
xD1: U1.D5 (IO_L3P_0); also elsewhere on the board
xD3: U1.R12 (IO_L52P_M1DQ14_1); also elsewhere on the board
xD6: U1.C4 (IO_L1P_HSWAPEN_0); also elsewhere on the board
~BTN_NMI: U1.L13 (IO_L53N_VREF_1); also elsewhere on the board
~BTN_RST: U1.A13 (IO_L63N_SCP6_0); also elsewhere on the board
~MRD: U1.G14 (IO_L36P_A9_M1BA0_1); also elsewhere on the board
~MWR: U1.M16 (IO_L46N_FOE_B_M1DQ3_1); also elsewhere on the board
~PSRAM_CS: U1.M13 (IO_L74P_AWAKE_1); also elsewhere on the board
~SD_CS: U1.F14 (IO_L32N_A16_M1A9_1); also elsewhere on the board
~SD_DET: U1.A11 (IO_L39N_0); also elsewhere on the board
~VS_CS: U1.L12 (IO_L53P_1); also elsewhere on the board
~VS_DCS: U1.E8 (IO_L36N_GCLK14_0); also elsewhere on the board
~oRST: U1.C5 (IO_L3N_0); also elsewhere on the board
~xIORQ: U1.T12 (IO_L52N_M1DQ15_1); also elsewhere on the board
~xMREQ: U1.T13 (IO_L51N_M1DQ13_1); also elsewhere on the board

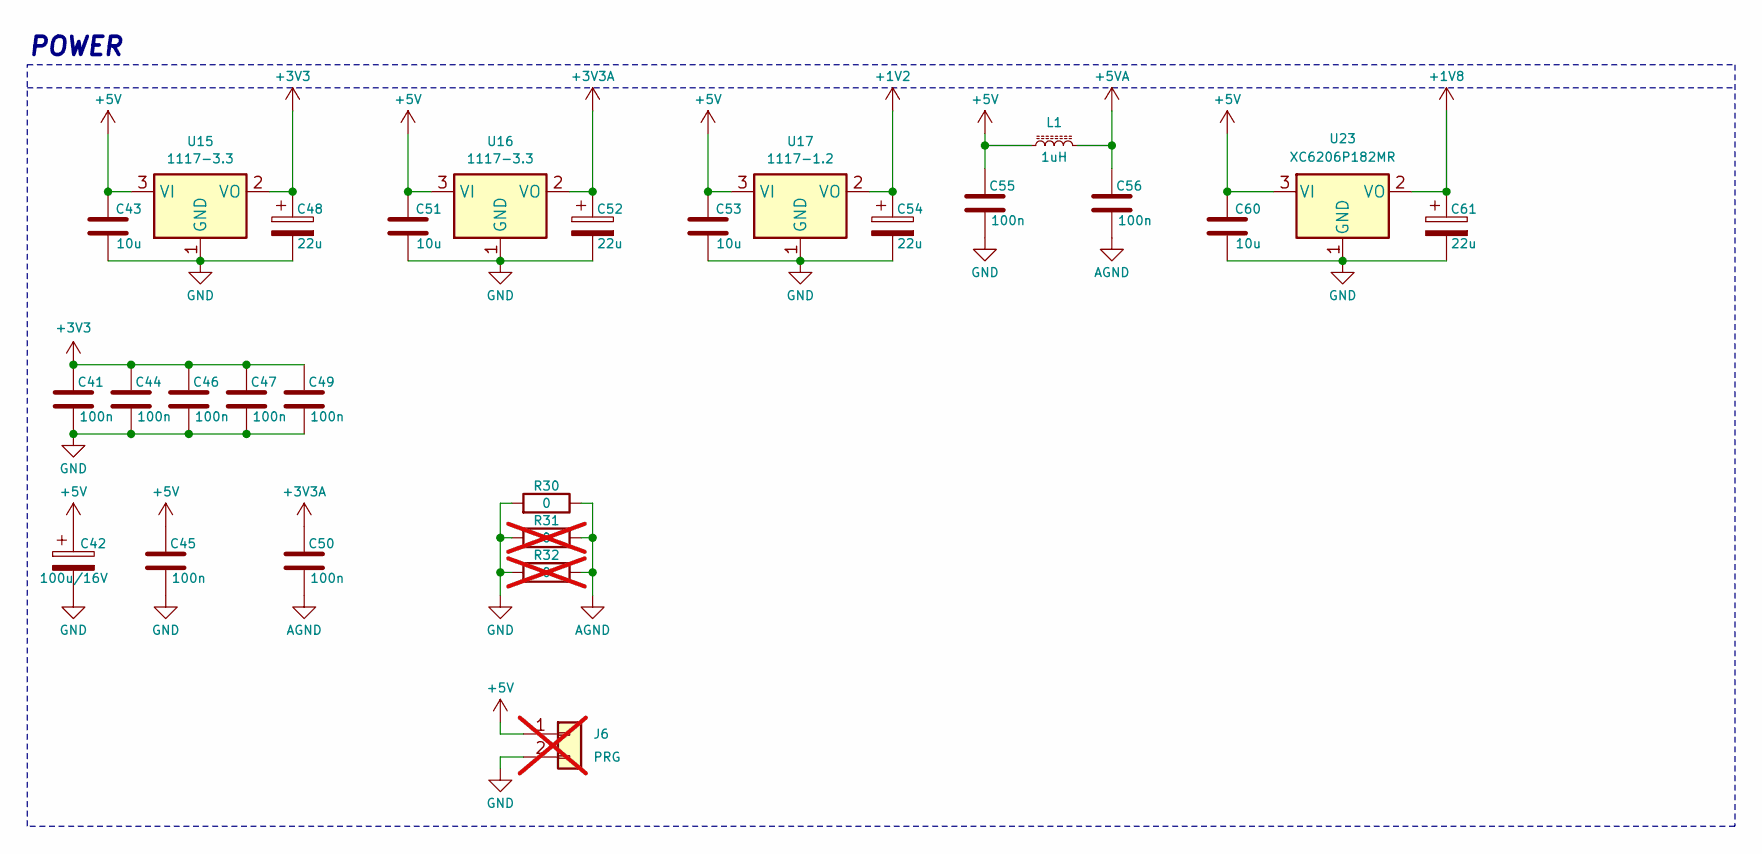
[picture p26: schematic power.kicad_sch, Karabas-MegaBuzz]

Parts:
C41, C44, C45, C46, C47, C49, C50, C55, C56: 100n; C_0603_1608Metric_Pad1.08x0.95mm_HandSolder
C42: 100u/16V; CP_EIA-6032-28_Kemet-C_HandSolder
C43, C51, C53, C60: 10u; C_0603_1608Metric_Pad1.08x0.95mm_HandSolder
C48, C52, C54, C61: 22u; CP_EIA-3216-18_Kemet-A_HandSolder
J6: PRG; PinHeader_1x02_P2.54mm_Vertical; not fitted
L1: 1uH; L_0603_1608Metric_Pad1.05x0.95mm_HandSolder
R30: 0; R_0603_1608Metric_Pad0.98x0.95mm_HandSolder
R31, R32: 0; R_0603_1608Metric_Pad0.98x0.95mm_HandSolder; not fitted
U15, U16: 1117-3.3; SOT-223-3_TabPin2
U17: 1117-1.2; SOT-223-3_TabPin2
U23: XC6206P182MR; SOT-23_Handsoldering

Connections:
+1V2: C54.1, U17.2 (VO); also elsewhere on the board
+1V8: C61.1, U23.2 (VO); also elsewhere on the board
+3V3: C41.1, C44.1, C46.1, C47.1, C48.1, C49.1, U15.2 (VO); also elsewhere on the board
+3V3A: C50.1, C52.1, U16.2 (VO); also elsewhere on the board
+5V: C42.1, C43.1, C45.2, C51.1, C53.1, C55.1, C60.1, J6.1, L1.1, U15.3 (VI), U16.3 (VI), U17.3 (VI), U23.3 (VI); also elsewhere on the board
+5VA: C56.1, L1.2; also elsewhere on the board
AGND: C50.2, C56.2, R30.1, R31.1, R32.1; also elsewhere on the board
GND: C41.2, C42.2, C43.2, C44.2, C45.1, C46.2, C47.2, C48.2, C49.2, C51.2, C52.2, C53.2, C54.2, C55.2, C60.2, C61.2, J6.2, R30.2, R31.2, R32.2, U15.1 (GND), U16.1 (GND), U17.1 (GND), U23.1 (GND); also elsewhere on the board

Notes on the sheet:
POWER

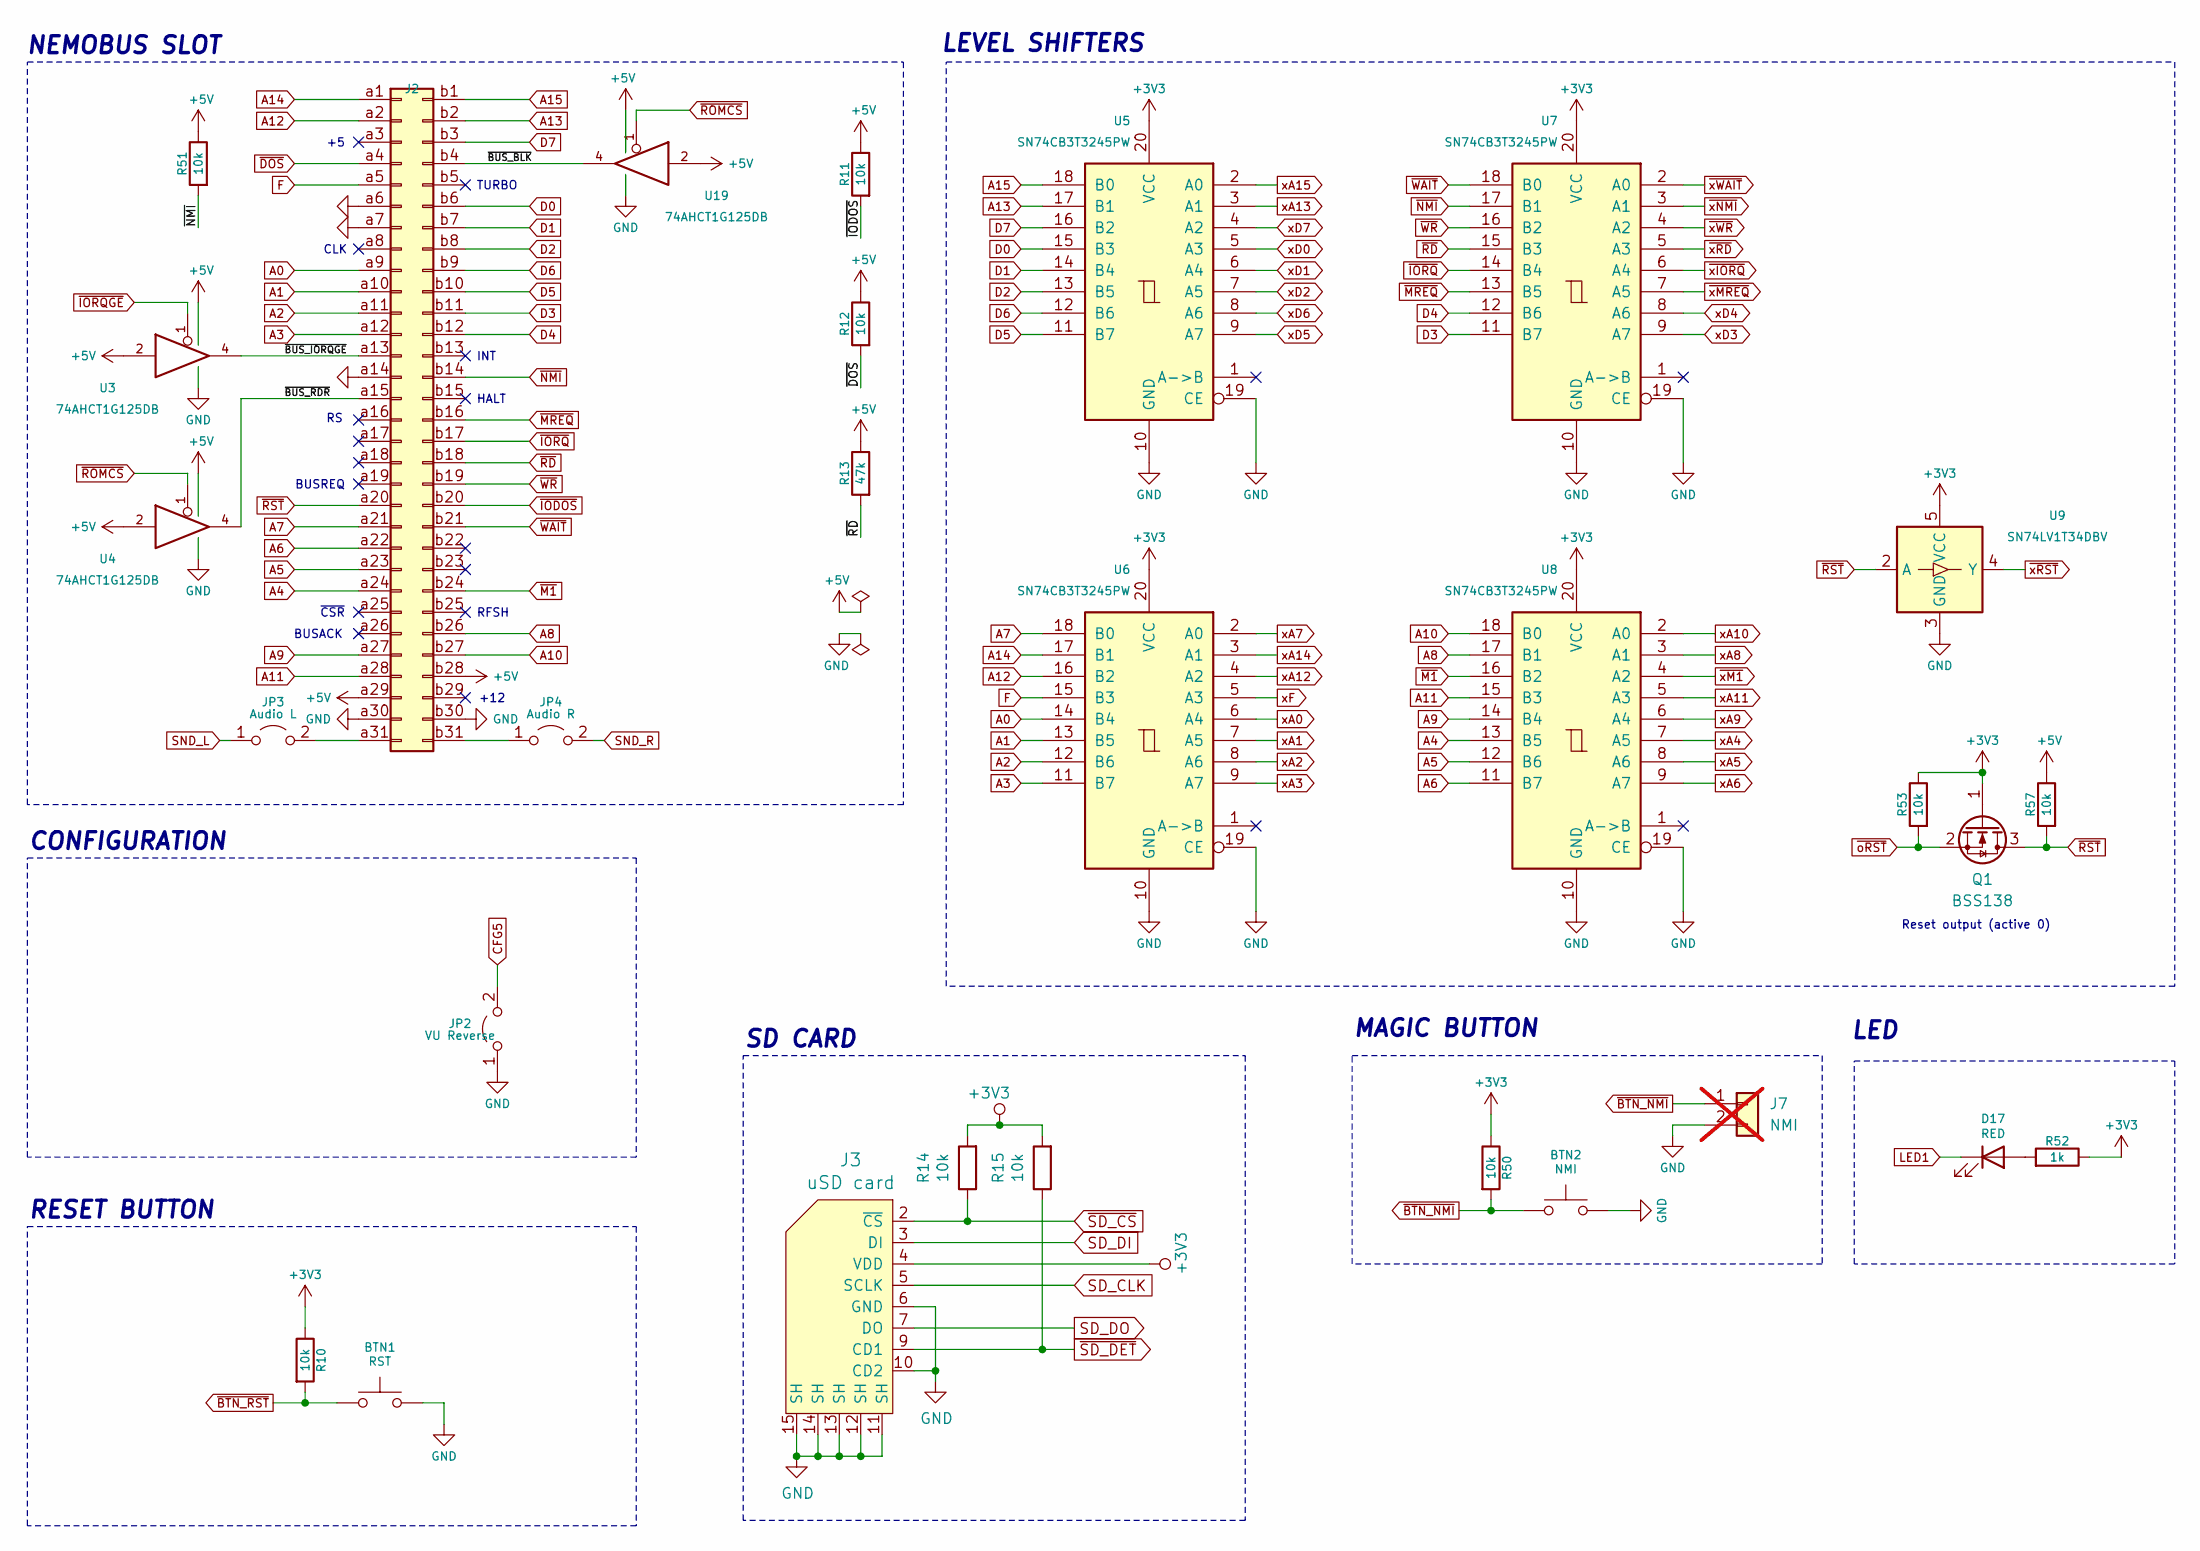
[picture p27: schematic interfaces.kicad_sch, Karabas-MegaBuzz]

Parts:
BTN1: RST; SW_SPST_PTS810_handsoldering
BTN2: NMI; SW_SPST_PTS810_handsoldering
D17: RED; LED_0603_1608Metric_Pad1.05x0.95mm_HandSolder
J2: Conn_02x31_Row_Letter_First; ZX_NEMO_62_EDGE
J3: uSD card; Conn_uSDcard
J7: NMI; PinHeader_1x02_P2.54mm_Vertical; not fitted
JP2: VU Reverse; SolderJumper-2_P1.3mm_Open_RoundedPad1.0x1.5mm
JP3: Audio L; SolderJumper-2_P1.3mm_Open_RoundedPad1.0x1.5mm
JP4: Audio R; SolderJumper-2_P1.3mm_Open_RoundedPad1.0x1.5mm
Q1: BSS138; SOT-23
R10, R11, R12, R14, R15, R50, R51, R53, R57: 10k; R_0603_1608Metric_Pad0.98x0.95mm_HandSolder
R13: 47k; R_0603_1608Metric_Pad0.98x0.95mm_HandSolder
R52: 1k; R_0603_1608Metric_Pad0.98x0.95mm_HandSolder
U3, U4, U19: 74AHCT1G125DB; SOT-23-5_HandSoldering
U5, U6, U7, U8: SN74CB3T3245PW; TSSOP-20_4.4x6.5mm_P0.65mm
U9: SN74LV1T34DBV; SOT-23-5_HandSoldering

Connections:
+3V3: J3.4 (VDD), Q1.1 (G), R10.1, R14.2, R15.2, R50.1, R52.1, R53.1, U5.20 (VCC), U6.20 (VCC), U7.20 (VCC), U8.20 (VCC), U9.5 (VCC); also elsewhere on the board
+5V: J2.a29, J2.b28, R11.1, R12.1, R13.1, R51.1, R57.1, U3.2, U3.5 (VCC), U4.2, U4.5 (VCC), U19.2, U19.5 (VCC); also elsewhere on the board
/Interfaces/~BUS_BLK: J2.b4, U19.4
/Interfaces/~BUS_IORQGE: J2.a13, U3.4
/Interfaces/~BUS_RDR: J2.a15, U4.4
A0: J2.a9, U6.14 (B4)
A1: J2.a10, U6.13 (B5)
A2: J2.a11, U6.12 (B6)
A3: J2.a12, U6.11 (B7)
A4: J2.a24, U8.13 (B5)
A5: J2.a23, U8.12 (B6)
A6: J2.a22, U8.11 (B7)
A7: J2.a21, U6.18 (B0)
A8: J2.b26, U8.17 (B1)
A9: J2.a27, U8.14 (B4)
A10: J2.b27, U8.18 (B0)
A11: J2.a28, U8.15 (B3)
A12: J2.a2, U6.16 (B2)
A13: J2.b2, U5.17 (B1)
A14: J2.a1, U6.17 (B1)
A15: J2.b1, U5.18 (B0)
CFG5: JP2.2 (B); also elsewhere on the board
D0: J2.b6, U5.15 (B3)
D1: J2.b7, U5.14 (B4)
D2: J2.b8, U5.13 (B5)
D3: J2.b11, U7.11 (B7)
D4: J2.b12, U7.12 (B6)
D5: J2.b10, U5.11 (B7)
D6: J2.b9, U5.12 (B6)
D7: J2.b3, U5.16 (B2)
F: J2.a5, U6.15 (B3)
GND: BTN1.2, BTN2.2, J2.a6, J2.a7, J2.a14, J2.a30, J2.b30, J3.6 (GND), J3.10 (CD2), J3.11 (SH), J3.12 (SH), J3.13 (SH), J3.14 (SH), J3.15 (SH), J7.2, JP2.1 (A), U3.3 (GND), U4.3 (GND), U5.10 (GND), U5.19 (CE), U6.10 (GND), U6.19 (CE), U7.10 (GND), U7.19 (CE), U8.10 (GND), U8.19 (CE), U9.3 (GND), U19.3 (GND); also elsewhere on the board
LED1: D17.1 (K); also elsewhere on the board
unnamed: D17.2 (A), R52.2
unnamed: J2.a31, JP3.2 (B)
unnamed: J2.b31, JP4.1 (A)
SD_CLK: J3.5 (SCLK); also elsewhere on the board
SD_DI: J3.3 (DI); also elsewhere on the board
SD_DO: J3.7 (DO); also elsewhere on the board
SND_L: JP3.1 (A); also elsewhere on the board
SND_R: JP4.2 (B); also elsewhere on the board
xA0: U6.6 (A4); also elsewhere on the board
xA1: U6.7 (A5); also elsewhere on the board
xA2: U6.8 (A6); also elsewhere on the board
xA3: U6.9 (A7); also elsewhere on the board
xA4: U8.7 (A5); also elsewhere on the board
xA5: U8.8 (A6); also elsewhere on the board
xA6: U8.9 (A7); also elsewhere on the board
xA7: U6.2 (A0); also elsewhere on the board
xA8: U8.3 (A1); also elsewhere on the board
xA9: U8.6 (A4); also elsewhere on the board
xA10: U8.2 (A0); also elsewhere on the board
xA11: U8.5 (A3); also elsewhere on the board
xA12: U6.4 (A2); also elsewhere on the board
xA13: U5.3 (A1); also elsewhere on the board
xA14: U6.3 (A1); also elsewhere on the board
xA15: U5.2 (A0); also elsewhere on the board
xD0: U5.5 (A3); also elsewhere on the board
xD1: U5.6 (A4); also elsewhere on the board
xD2: U5.7 (A5); also elsewhere on the board
xD3: U7.9 (A7); also elsewhere on the board
xD4: U7.8 (A6); also elsewhere on the board
xD5: U5.9 (A7); also elsewhere on the board
xD6: U5.8 (A6); also elsewhere on the board
xD7: U5.4 (A2); also elsewhere on the board
xF: U6.5 (A3); also elsewhere on the board
~BTN_NMI: BTN2.1, J7.1, R50.2; also elsewhere on the board
~BTN_RST: BTN1.1, R10.2; also elsewhere on the board
~DOS: J2.a4, R12.2
~IODOS: J2.b20, R11.2
~IORQGE: U3.1; also elsewhere on the board
~IORQ: J2.b17, U7.14 (B4)
~M1: J2.b24, U8.16 (B2)
~MREQ: J2.b16, U7.13 (B5)
~NMI: J2.b14, R51.2, U7.17 (B1)
~RD: J2.b18, R13.2, U7.15 (B3)
~ROMCS: U4.1, U19.1; also elsewhere on the board
~RST: J2.a20, Q1.3 (D), R57.2, U9.2 (A)
~SD_CS: J3.2 (~CS), R14.1; also elsewhere on the board
~SD_DET: J3.9 (CD1), R15.1; also elsewhere on the board
~WAIT: J2.b21, U7.18 (B0)
~WR: J2.b19, U7.16 (B2)
~oRST: Q1.2 (S), R53.2; also elsewhere on the board
~xIORQ: U7.6 (A4); also elsewhere on the board
~xM1: U8.4 (A2); also elsewhere on the board
~xMREQ: U7.7 (A5); also elsewhere on the board
~xNMI: U7.3 (A1); also elsewhere on the board
~xRD: U7.5 (A3); also elsewhere on the board
~xRST: U9.4 (Y); also elsewhere on the board
~xWAIT: U7.2 (A0); also elsewhere on the board
~xWR: U7.4 (A2); also elsewhere on the board

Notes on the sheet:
BUSREQ
SD CARD
CLK
CONFIGURATION
RFSH
Reset output (active 0)
+12
HALT
LEVEL SHIFTERS
TURBO
LED
~{CSR}
NEMOBUS SLOT
RESET BUTTON
BUSACK
MAGIC BUTTON
INT

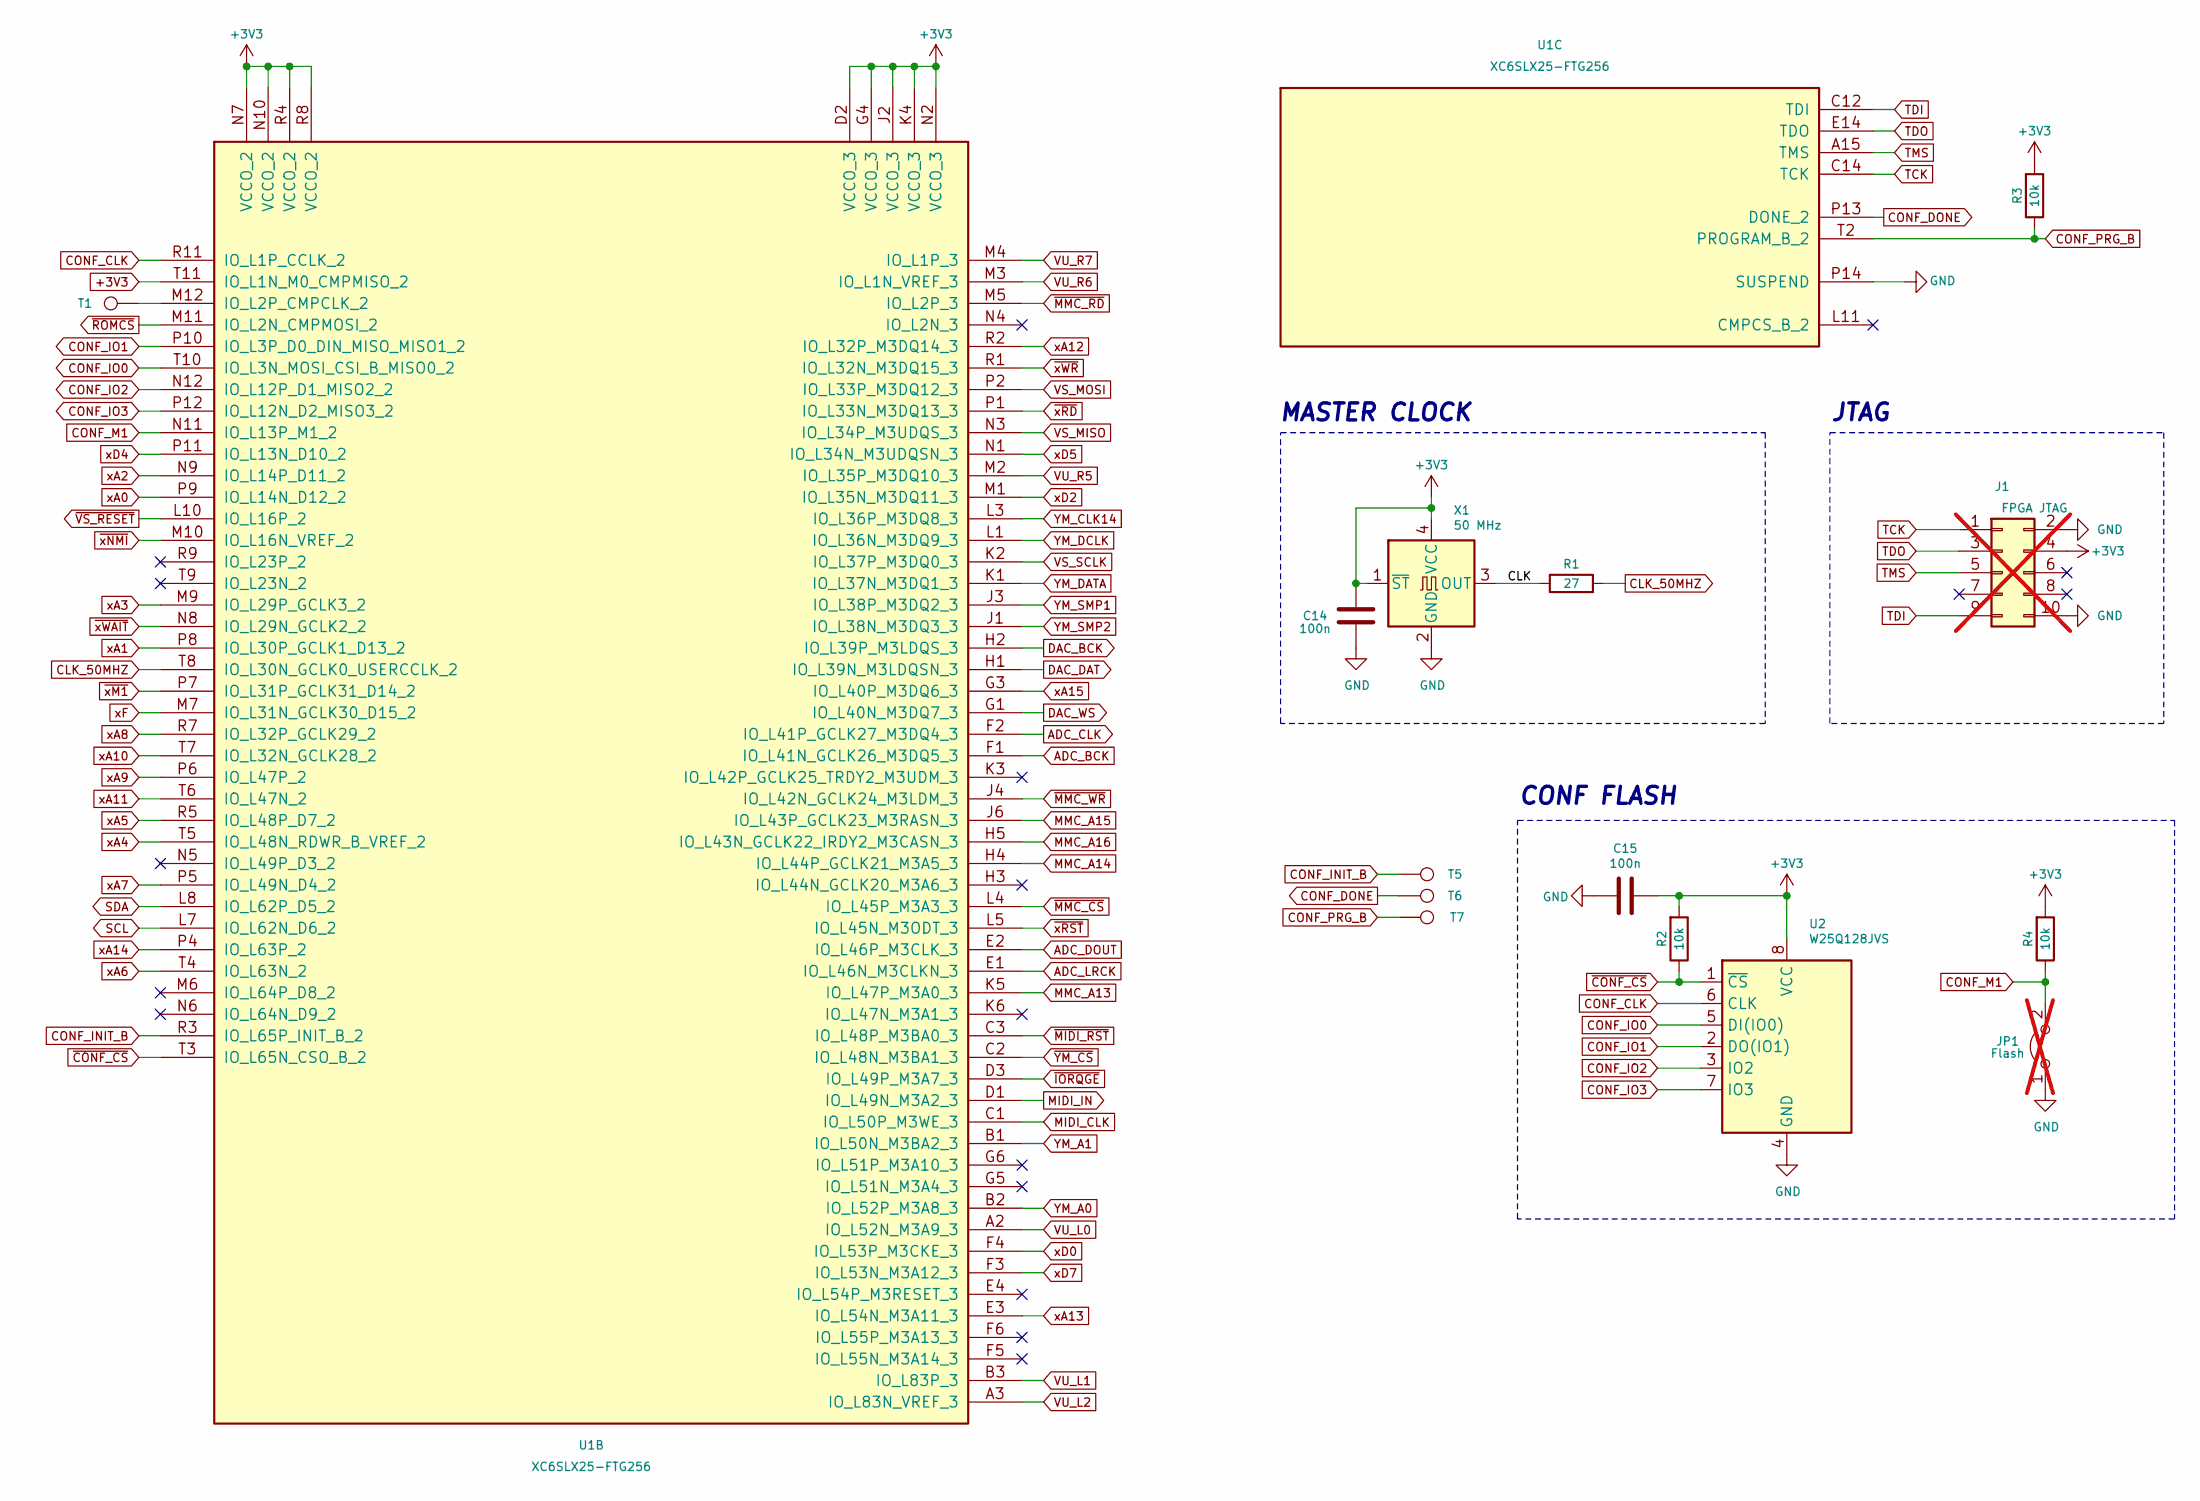
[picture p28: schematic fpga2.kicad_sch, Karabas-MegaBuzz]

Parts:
C14, C15: 100n; C_0603_1608Metric_Pad1.08x0.95mm_HandSolder
J1: FPGA JTAG; PinHeader_2x05_P2.54mm_Vertical; not fitted
JP1: Flash; SolderJumper-2_P1.3mm_Bridged_RoundedPad1.0x1.5mm; not fitted
R1: 27; R_0603_1608Metric_Pad0.98x0.95mm_HandSolder
R2, R3, R4: 10k; R_0603_1608Metric_Pad0.98x0.95mm_HandSolder
T1: TestPoint1; TestPoint_Pad_D1.5mm
T5, T6, T7: TestPoint; TestPoint_Pad_D1.5mm
U1: XC6SLX25-FTG256; BGA-256_17.0x17.0mm_Layout16x16_P1.0mm_Ball0.5mm_Pad0.4mm_N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
U2: W25Q128JVS; SOIC-8_5.3x5.3mm_P1.27mm
X1: 50 MHz; Oscillator_SMD_SeikoEpson_SG8002CA-4Pin_7.0x5.0mm

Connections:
+3V3: C14.1, C15.1, J1.4, R2.2, R3.2, R4.2, U1.D2 (VCCO_3), U1.G4 (VCCO_3), U1.J2 (VCCO_3), U1.K4 (VCCO_3), U1.N2 (VCCO_3), U1.N7 (VCCO_2), U1.N10 (VCCO_2), U1.R4 (VCCO_2), U1.R8 (VCCO_2), U1.T11 (IO_L1N_M0_CMPMISO_2), U2.8 (VCC), X1.1 (~ST), X1.4 (VCC); also elsewhere on the board
/FPGA2/CLK: R1.1, X1.3 (OUT)
ADC_BCK: U1.F1 (IO_L41N_GCLK26_M3DQ5_3); also elsewhere on the board
ADC_CLK: U1.F2 (IO_L41P_GCLK27_M3DQ4_3); also elsewhere on the board
ADC_DOUT: U1.E2 (IO_L46P_M3CLK_3); also elsewhere on the board
ADC_LRCK: U1.E1 (IO_L46N_M3CLKN_3); also elsewhere on the board
CLK_50MHZ: R1.2, U1.T8 (IO_L30N_GCLK0_USERCCLK_2)
CONF_CLK: U1.R11 (IO_L1P_CCLK_2), U2.6 (CLK); also elsewhere on the board
CONF_DONE: T6.1 (1_1), U1.P13 (DONE_2)
CONF_INIT_B: T5.1 (1_1), U1.R3 (IO_L65P_INIT_B_2)
CONF_IO0: U1.T10 (IO_L3N_MOSI_CSI_B_MISO0_2), U2.5 (DI(IO0)); also elsewhere on the board
CONF_IO1: U1.P10 (IO_L3P_D0_DIN_MISO_MISO1_2), U2.2 (DO(IO1)); also elsewhere on the board
CONF_IO2: U1.N12 (IO_L12P_D1_MISO2_2), U2.3 (IO2); also elsewhere on the board
CONF_IO3: U1.P12 (IO_L12N_D2_MISO3_2), U2.7 (IO3); also elsewhere on the board
CONF_M1: JP1.2 (B), R4.1, U1.N11 (IO_L13P_M1_2)
CONF_PRG_B: R3.1, T7.1 (1_1), U1.T2 (PROGRAM_B_2)
DAC_BCK: U1.H2 (IO_L39P_M3LDQS_3); also elsewhere on the board
DAC_DAT: U1.H1 (IO_L39N_M3LDQSN_3); also elsewhere on the board
DAC_WS: U1.G1 (IO_L40N_M3DQ7_3); also elsewhere on the board
GND: C14.2, C15.2, J1.2, J1.10, JP1.1 (A), U1.P14 (SUSPEND), U2.4 (GND), X1.2 (GND); also elsewhere on the board
MIDI_CLK: U1.C1 (IO_L50P_M3WE_3); also elsewhere on the board
MIDI_IN: U1.D1 (IO_L49N_M3A2_3); also elsewhere on the board
MMC_A13: U1.K5 (IO_L47P_M3A0_3); also elsewhere on the board
MMC_A14: U1.H4 (IO_L44P_GCLK21_M3A5_3); also elsewhere on the board
MMC_A15: U1.J6 (IO_L43P_GCLK23_M3RASN_3); also elsewhere on the board
MMC_A16: U1.H5 (IO_L43N_GCLK22_IRDY2_M3CASN_3); also elsewhere on the board
unnamed: T1.1 (1_1), U1.M12 (IO_L2P_CMPCLK_2)
SCL: U1.L7 (IO_L62N_D6_2); also elsewhere on the board
SDA: U1.L8 (IO_L62P_D5_2); also elsewhere on the board
TCK: J1.1, U1.C14 (TCK)
TDI: J1.9, U1.C12 (TDI)
TDO: J1.3, U1.E14 (TDO)
TMS: J1.5, U1.A15 (TMS)
VS_MISO: U1.N3 (IO_L34P_M3UDQS_3); also elsewhere on the board
VS_MOSI: U1.P2 (IO_L33P_M3DQ12_3); also elsewhere on the board
VS_SCLK: U1.K2 (IO_L37P_M3DQ0_3); also elsewhere on the board
VU_L0: U1.A2 (IO_L52N_M3A9_3); also elsewhere on the board
VU_L1: U1.B3 (IO_L83P_3); also elsewhere on the board
VU_L2: U1.A3 (IO_L83N_VREF_3); also elsewhere on the board
VU_R5: U1.M2 (IO_L35P_M3DQ10_3); also elsewhere on the board
VU_R6: U1.M3 (IO_L1N_VREF_3); also elsewhere on the board
VU_R7: U1.M4 (IO_L1P_3); also elsewhere on the board
YM_A0: U1.B2 (IO_L52P_M3A8_3); also elsewhere on the board
YM_A1: U1.B1 (IO_L50N_M3BA2_3); also elsewhere on the board
YM_CLK14: U1.L3 (IO_L36P_M3DQ8_3); also elsewhere on the board
YM_DATA: U1.K1 (IO_L37N_M3DQ1_3); also elsewhere on the board
YM_DCLK: U1.L1 (IO_L36N_M3DQ9_3); also elsewhere on the board
YM_SMP1: U1.J3 (IO_L38P_M3DQ2_3); also elsewhere on the board
YM_SMP2: U1.J1 (IO_L38N_M3DQ3_3); also elsewhere on the board
xA0: U1.P9 (IO_L14N_D12_2); also elsewhere on the board
xA1: U1.P8 (IO_L30P_GCLK1_D13_2); also elsewhere on the board
xA2: U1.N9 (IO_L14P_D11_2); also elsewhere on the board
xA3: U1.M9 (IO_L29P_GCLK3_2); also elsewhere on the board
xA4: U1.T5 (IO_L48N_RDWR_B_VREF_2); also elsewhere on the board
xA5: U1.R5 (IO_L48P_D7_2); also elsewhere on the board
xA6: U1.T4 (IO_L63N_2); also elsewhere on the board
xA7: U1.P5 (IO_L49N_D4_2); also elsewhere on the board
xA8: U1.R7 (IO_L32P_GCLK29_2); also elsewhere on the board
xA9: U1.P6 (IO_L47P_2); also elsewhere on the board
xA10: U1.T7 (IO_L32N_GCLK28_2); also elsewhere on the board
xA11: U1.T6 (IO_L47N_2); also elsewhere on the board
xA12: U1.R2 (IO_L32P_M3DQ14_3); also elsewhere on the board
xA13: U1.E3 (IO_L54N_M3A11_3); also elsewhere on the board
xA14: U1.P4 (IO_L63P_2); also elsewhere on the board
xA15: U1.G3 (IO_L40P_M3DQ6_3); also elsewhere on the board
xD0: U1.F4 (IO_L53P_M3CKE_3); also elsewhere on the board
xD2: U1.M1 (IO_L35N_M3DQ11_3); also elsewhere on the board
xD4: U1.P11 (IO_L13N_D10_2); also elsewhere on the board
xD5: U1.N1 (IO_L34N_M3UDQSN_3); also elsewhere on the board
xD7: U1.F3 (IO_L53N_M3A12_3); also elsewhere on the board
xF: U1.M7 (IO_L31N_GCLK30_D15_2); also elsewhere on the board
~CONF_CS: R2.1, U1.T3 (IO_L65N_CSO_B_2), U2.1 (~CS)
~IORQGE: U1.D3 (IO_L49P_M3A7_3); also elsewhere on the board
~MIDI_RST: U1.C3 (IO_L48P_M3BA0_3); also elsewhere on the board
~MMC_CS: U1.L4 (IO_L45P_M3A3_3); also elsewhere on the board
~MMC_RD: U1.M5 (IO_L2P_3); also elsewhere on the board
~MMC_WR: U1.J4 (IO_L42N_GCLK24_M3LDM_3); also elsewhere on the board
~ROMCS: U1.M11 (IO_L2N_CMPMOSI_2); also elsewhere on the board
~VS_RESET: U1.L10 (IO_L16P_2); also elsewhere on the board
~YM_CS: U1.C2 (IO_L48N_M3BA1_3); also elsewhere on the board
~xM1: U1.P7 (IO_L31P_GCLK31_D14_2); also elsewhere on the board
~xNMI: U1.M10 (IO_L16N_VREF_2); also elsewhere on the board
~xRD: U1.P1 (IO_L33N_M3DQ13_3); also elsewhere on the board
~xRST: U1.L5 (IO_L45N_M3ODT_3); also elsewhere on the board
~xWAIT: U1.N8 (IO_L29N_GCLK2_2); also elsewhere on the board
~xWR: U1.R1 (IO_L32N_M3DQ15_3); also elsewhere on the board

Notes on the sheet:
CONF FLASH
JTAG
MASTER CLOCK

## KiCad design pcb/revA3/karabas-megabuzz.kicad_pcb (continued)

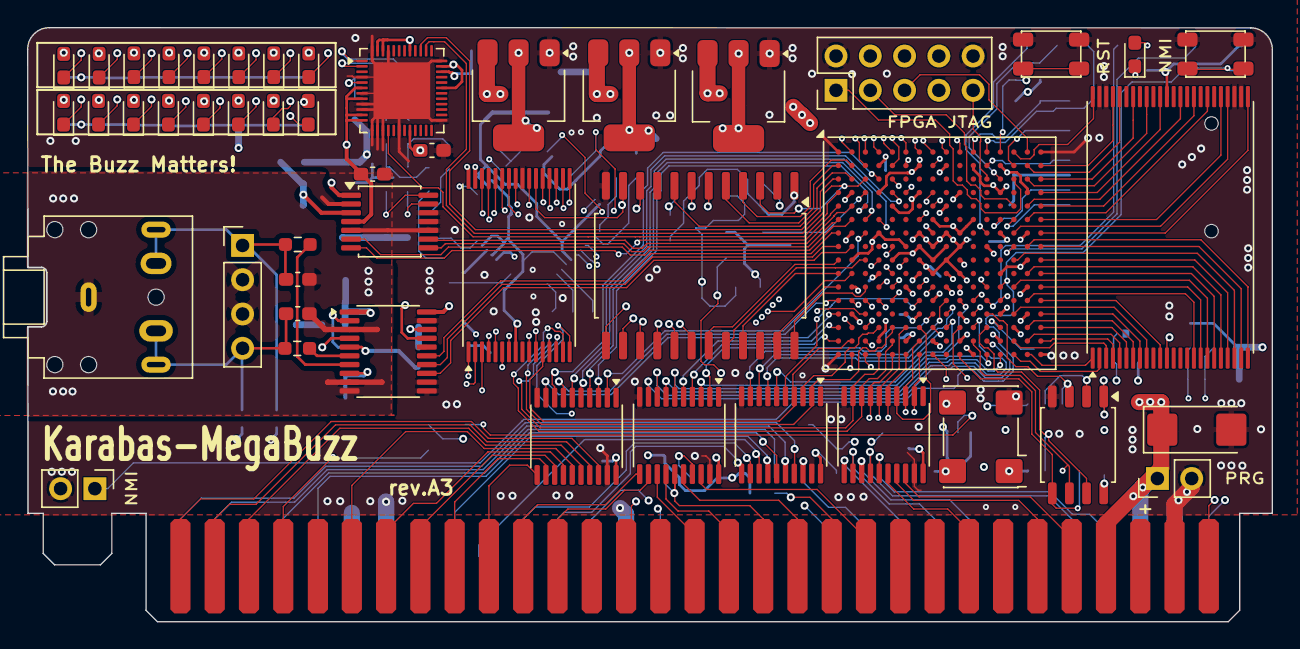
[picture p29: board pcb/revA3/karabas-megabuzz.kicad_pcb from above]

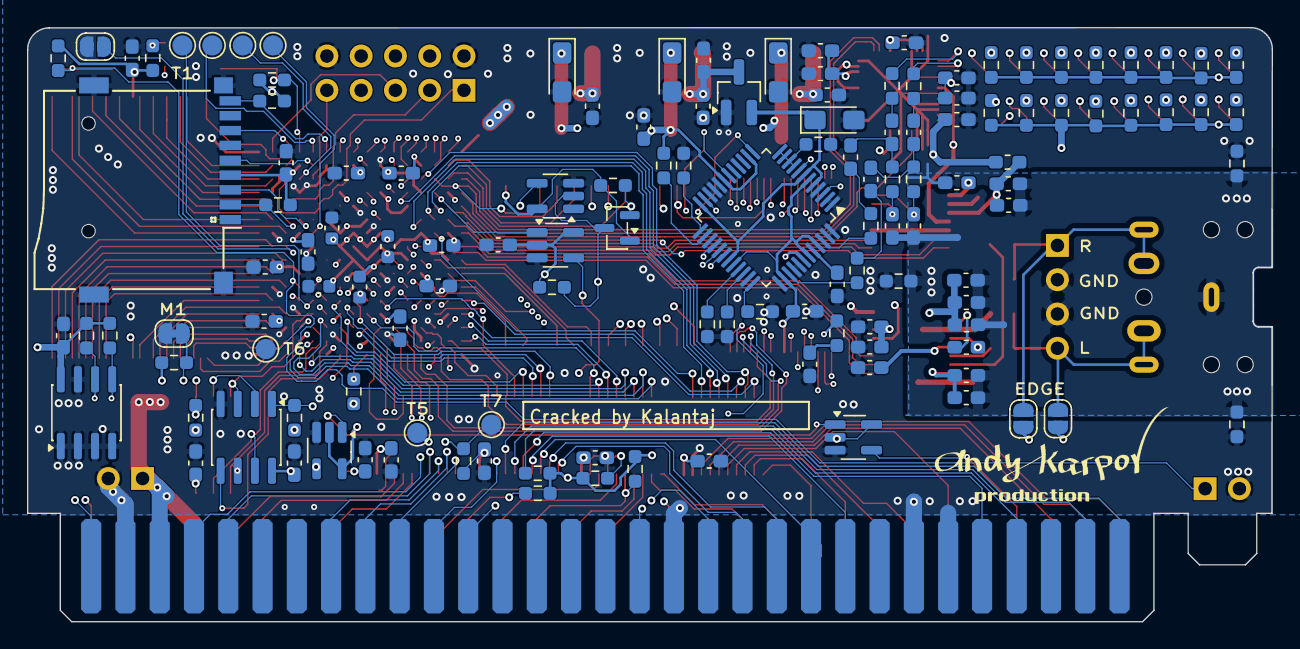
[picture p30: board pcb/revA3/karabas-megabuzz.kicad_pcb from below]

Board: 4 copper layers, 92.2 x 44.0 mm, 180 parts (132 on the bottom side), 245 nets.

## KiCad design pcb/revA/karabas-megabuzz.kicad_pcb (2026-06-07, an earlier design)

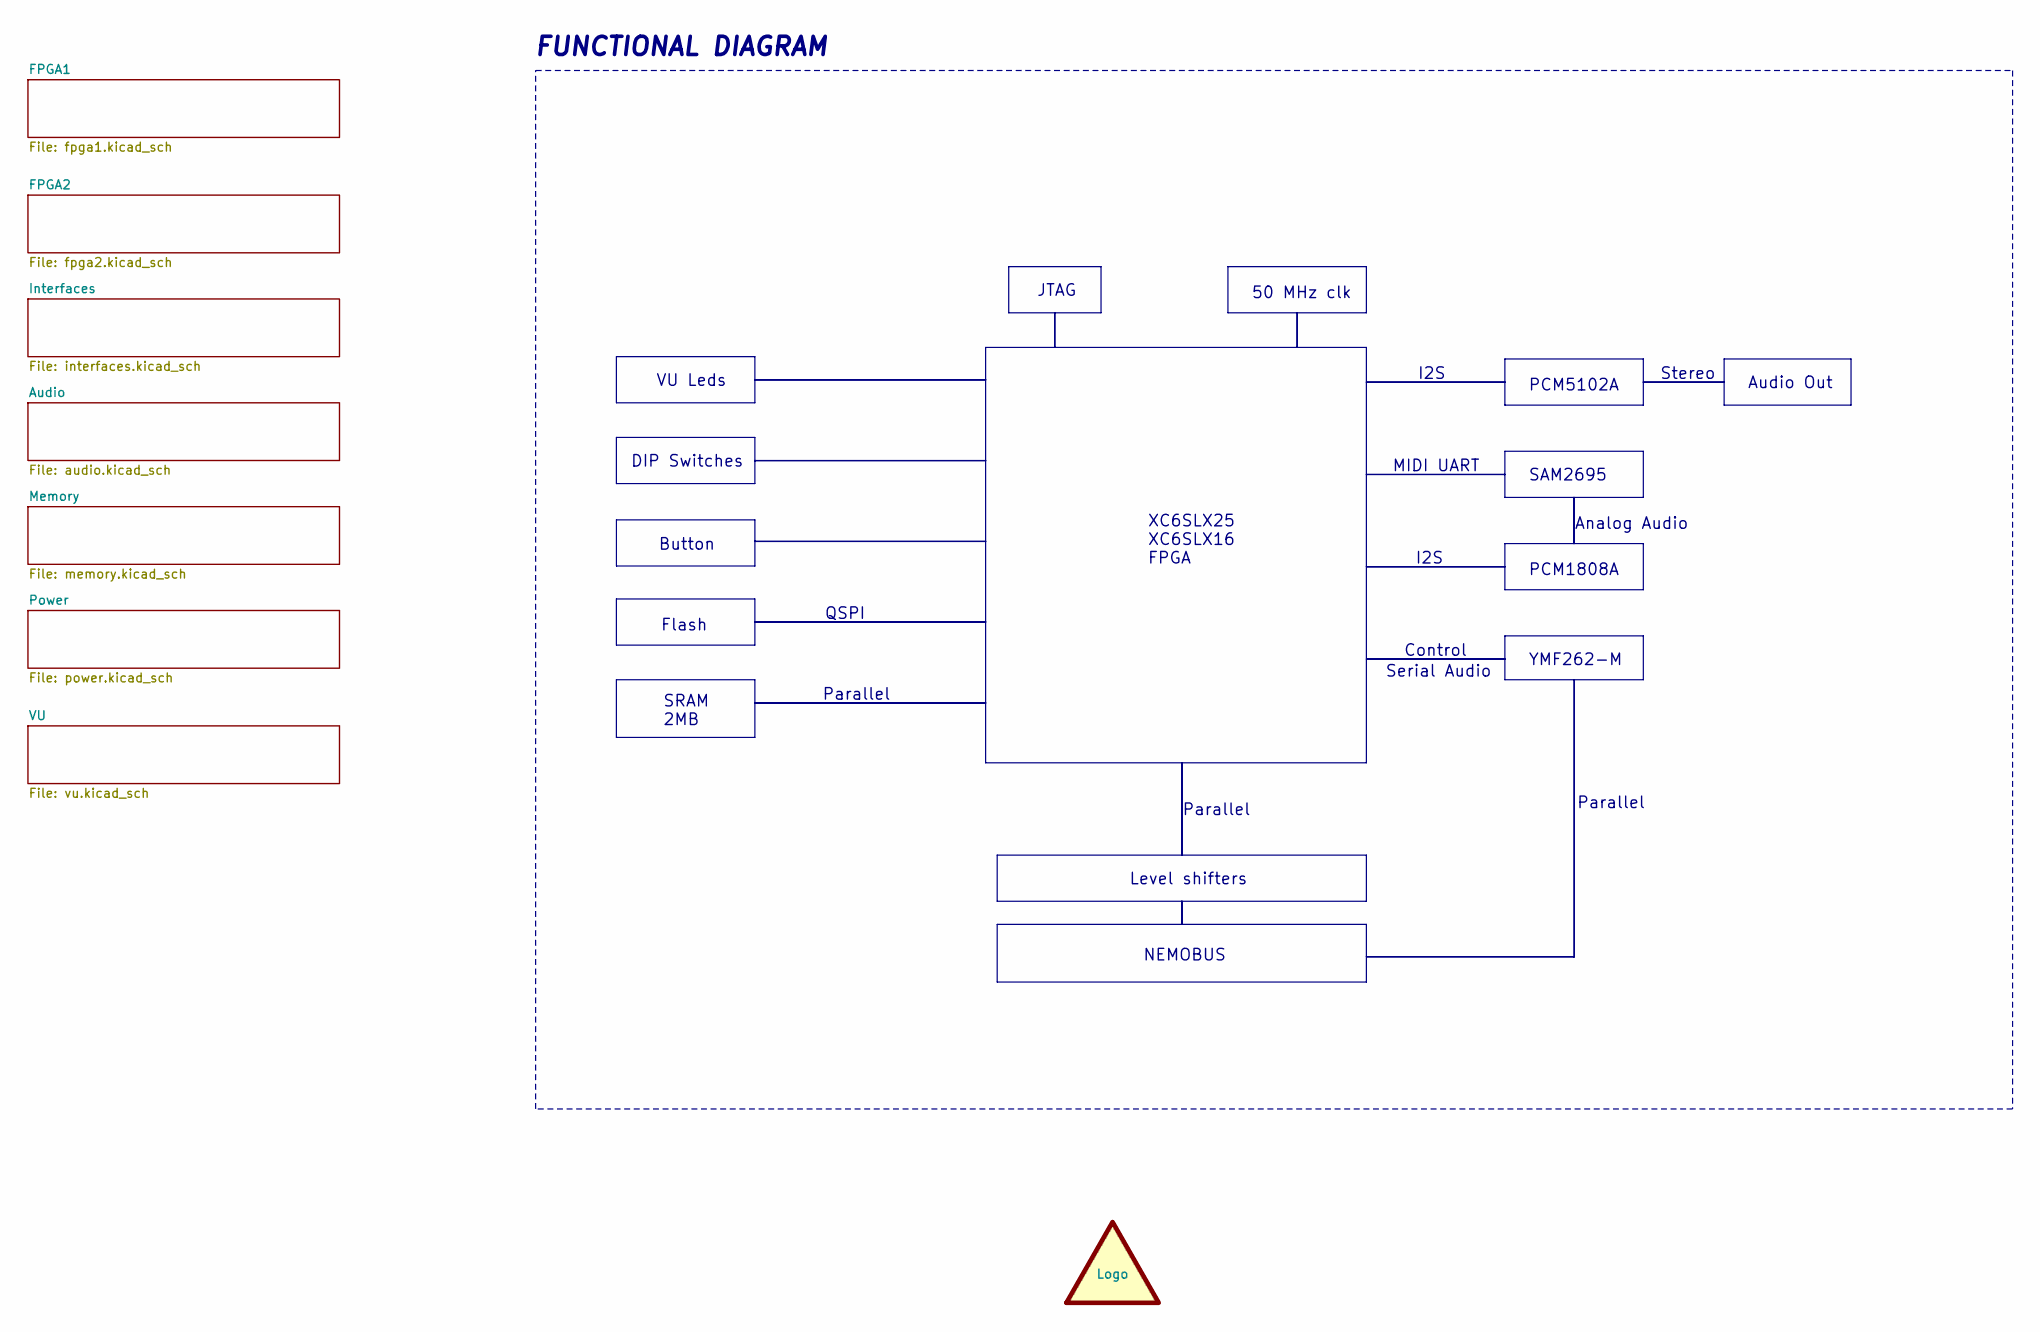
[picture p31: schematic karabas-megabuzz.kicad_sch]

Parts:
LOGO2: graphic; andy_karpov_logo4_silk

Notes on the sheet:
PCM5102A
VU Leds
XC6SLX25 XC6SLX16 FPGA
MIDI UART
Button
PCM1808A
Parallel
YMF262-M
NEMOBUS
DIP Switches
Audio Out
I2S
JTAG
Analog Audio
QSPI
50 MHz clk
Flash
SRAM 2MB
Level shifters
Control
Serial Audio
FUNCTIONAL DIAGRAM
SAM2695
Stereo

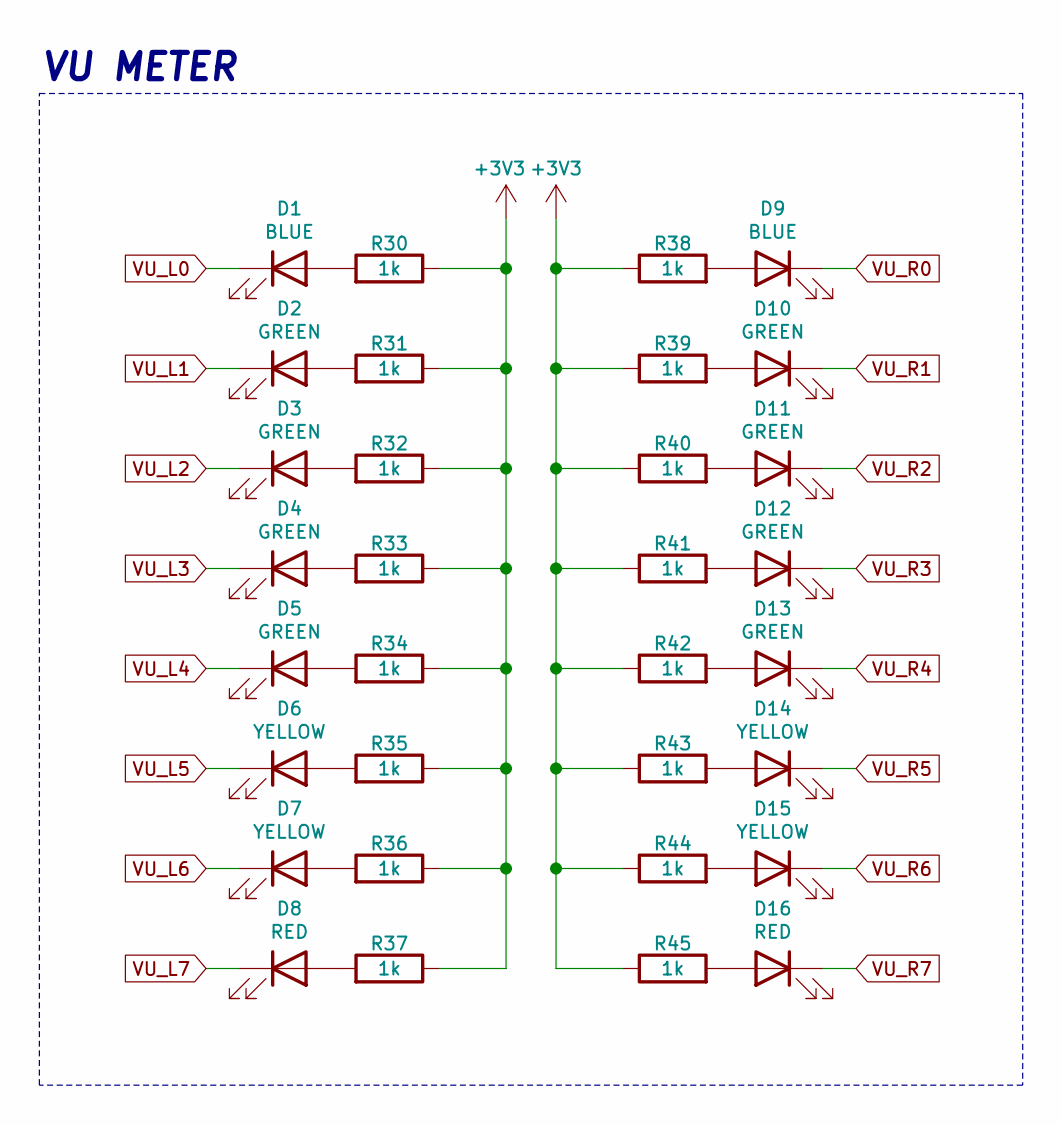
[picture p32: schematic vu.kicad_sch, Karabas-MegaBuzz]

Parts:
D1, D9: BLUE; LED_0603_1608Metric_Pad1.05x0.95mm_HandSolder
D2, D3, D4, D5, D10, D11, D12, D13: GREEN; LED_0603_1608Metric_Pad1.05x0.95mm_HandSolder
D6, D7, D14, D15: YELLOW; LED_0603_1608Metric_Pad1.05x0.95mm_HandSolder
D8, D16: RED; LED_0603_1608Metric_Pad1.05x0.95mm_HandSolder
R30, R31, R32, R33, R34, R35, R36, R37, R38, R39, R40, R41, R42, R43, R44, R45: 1k; R_0603_1608Metric_Pad0.98x0.95mm_HandSolder

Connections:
+3V3: R30.1, R31.1, R32.1, R33.1, R34.1, R35.1, R36.1, R37.1, R38.1, R39.1, R40.1, R41.1, R42.1, R43.1, R44.1, R45.1; also elsewhere on the board
unnamed: D1.2 (A), R30.2
unnamed: D2.2 (A), R31.2
unnamed: D3.2 (A), R32.2
unnamed: D4.2 (A), R33.2
unnamed: D5.2 (A), R34.2
unnamed: D6.2 (A), R35.2
unnamed: D7.2 (A), R36.2
unnamed: D8.2 (A), R37.2
unnamed: D9.2 (A), R38.2
unnamed: D10.2 (A), R39.2
unnamed: D11.2 (A), R40.2
unnamed: D12.2 (A), R41.2
unnamed: D13.2 (A), R42.2
unnamed: D14.2 (A), R43.2
unnamed: D15.2 (A), R44.2
unnamed: D16.2 (A), R45.2
VU_L0: D1.1 (K); also elsewhere on the board
VU_L1: D2.1 (K); also elsewhere on the board
VU_L2: D3.1 (K); also elsewhere on the board
VU_L3: D4.1 (K); also elsewhere on the board
VU_L4: D5.1 (K); also elsewhere on the board
VU_L5: D6.1 (K); also elsewhere on the board
VU_L6: D7.1 (K); also elsewhere on the board
VU_L7: D8.1 (K); also elsewhere on the board
VU_R0: D9.1 (K); also elsewhere on the board
VU_R1: D10.1 (K); also elsewhere on the board
VU_R2: D11.1 (K); also elsewhere on the board
VU_R3: D12.1 (K); also elsewhere on the board
VU_R4: D13.1 (K); also elsewhere on the board
VU_R5: D14.1 (K); also elsewhere on the board
VU_R6: D15.1 (K); also elsewhere on the board
VU_R7: D16.1 (K); also elsewhere on the board

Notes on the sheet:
VU METER


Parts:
C16, C18, C19, C20, C27, C30, C31, C35: 10u; C_0603_1608Metric_Pad1.08x0.95mm_HandSolder
C17, C21, C22, C23, C28, C32, C37: 100n; C_0603_1608Metric_Pad1.08x0.95mm_HandSolder
C24, C29, C33, C34: 2u2; C_0603_1608Metric_Pad1.08x0.95mm_HandSolder
C25, C26, C36, C38: 2n2; C_0603_1608Metric_Pad1.08x0.95mm_HandSolder
J3: PJ307; Jack_3.5mm_CUI_SJ1-3525N_Horizontal
J4: Conn_01x04; PinHeader_1x04_P2.54mm_Vertical; not fitted
R13, R14, R15, R16, R22, R25, R26: 27; R_0603_1608Metric_Pad0.98x0.95mm_HandSolder
R17, R18, R21: 1k; R_0603_1608Metric_Pad0.98x0.95mm_HandSolder
R19, R20, R23, R24: 470; R_0603_1608Metric_Pad0.98x0.95mm_HandSolder
U8: YMF262-M; ymf-262-m
U9: SAM2695; QFN-48-1EP_6x6mm_P0.4mm_EP4.2x4.2mm
U10: PCM5102A; TSSOP-20_4.4x6.5mm_P0.65mm
U11: PCM1808PWR; TSSOP-14_4.4x5mm_P0.65mm; PARTREV B

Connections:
+3V3: C17.1, C22.1, C29.1, R21.1, U9.6 (VA33), U9.8 (VD33), U9.11 (VD33), U9.12 (~WR), U9.20 (VD33), U9.31 (VD33), U9.35 (VD33), U9.41 (VD33), U9.46 (VD33), U9.47 (XDIV), U10.20 (DVDD), U11.4 (VDD); also elsewhere on the board
+3V3A: C27.1, C28.1, C31.2, C32.2, U10.1 (CPVDD), U10.8 (AVDD); also elsewhere on the board
+5V: U8.1 (VDD); also elsewhere on the board
+5VA: C24.2, U11.3 (VCC); also elsewhere on the board
ADC_BCK: R25.2; also elsewhere on the board
ADC_CLK: R22.1; also elsewhere on the board
ADC_DOUT: U11.9 (DOUT); also elsewhere on the board
ADC_LRCK: R26.2; also elsewhere on the board
AGND: C24.1, C25.2, C26.2, C27.2, C28.2, C31.1, C32.1, C36.1, C38.1, J3.S, J4.2, J4.3, U10.3 (CPGND), U10.9 (AGND), U11.2 (AGND); also elsewhere on the board
D0: U8.10 (D0); also elsewhere on the board
D1: U8.11 (D1); also elsewhere on the board
D2: U8.13 (D2); also elsewhere on the board
D3: U8.14 (D3); also elsewhere on the board
D4: U8.15 (D4); also elsewhere on the board
D5: U8.16 (D5); also elsewhere on the board
D6: U8.17 (D6); also elsewhere on the board
D7: U8.18 (D7); also elsewhere on the board
DAC_BCK: U10.13 (BCK); also elsewhere on the board
DAC_DAT: U10.14 (DIN); also elsewhere on the board
DAC_WS: U10.15 (LRCK); also elsewhere on the board
GND: C16.2, C17.2, C18.2, C21.2, C22.2, C23.2, C29.2, C30.1, C33.1, C35.1, C37.1, U8.12 (VSS), U9.4 (AGND), U9.7 (MICIN), U9.9 (GND), U9.10 (A0), U9.13 (GND), U9.14 (~CS), U9.15 (~RD), U9.18 (GND), U9.25 (GND), U9.36 (GND), U9.45 (GND), U9.48 (GND), U9.49 (GND), U10.10 (DEMP), U10.11 (FLT), U10.12 (SCK), U10.16 (FMT), U10.19 (DGND), U11.5 (DGND), U11.10 (MD0), U11.11 (MD1), U11.12 (FMT); also elsewhere on the board
MIDI_CLK: U9.39 (X1); also elsewhere on the board
MIDI_IN: U9.16 (MIDI_IN); also elsewhere on the board
MIDI_L: C19.2, R19.1
MIDI_R: C20.2, R20.1
unnamed: C19.1, R17.2
unnamed: C20.1, R18.2
unnamed: R14.1, U8.21 (DOAB)
unnamed: R15.1, U8.20 (SMPAC)
unnamed: R16.1, U8.19 (SMPBD)
unnamed: R13.1, U8.23 (ØSY)
unnamed: R17.1, U9.1 (AOUTL)
unnamed: R18.1, U9.2 (AOUTR)
unnamed: C18.1, C23.1, U9.34 (OUTVC12)
unnamed: C16.1, C21.1, U9.5 (VCM)
unnamed: C34.1, U10.4 (CAPM)
unnamed: C34.2, U10.2 (CAPP)
unnamed: C35.2, C37.2, U10.18 (LDOO)
unnamed: R23.1, U10.6 (OUTL)
unnamed: R24.1, U10.7 (OUTR)
unnamed: C33.2, U10.5 (VNEG)
unnamed: R21.2, U10.17 (XSMT)
unnamed: R25.1, U11.8 (BCK)
unnamed: R26.1, U11.7 (LRCK)
unnamed: R22.2, U11.6 (SCKI)
unnamed: C25.1, R19.2, U11.13 (VINL)
unnamed: C26.1, R20.2, U11.14 (VINR)
unnamed: C30.2, U11.1 (VREF)
SND_L: C36.2, J3.T, J3.TN, J4.4, R23.2
SND_R: C38.2, J3.R, J3.RN, J4.1, R24.2
YM_A0: U8.4 (A0); also elsewhere on the board
YM_A1: U8.5 (A1); also elsewhere on the board
YM_CLK14: U8.24 (ØM); also elsewhere on the board
YM_DATA: R14.2; also elsewhere on the board
YM_DCLK: R13.2; also elsewhere on the board
YM_SMP1: R15.2; also elsewhere on the board
YM_SMP2: R16.2; also elsewhere on the board
~MIDI_RST: U8.3 (IC), U9.38 (~RST); also elsewhere on the board
~RD: U8.7 (RD); also elsewhere on the board
~WR: U8.6 (WR); also elsewhere on the board
~YM_CS: U8.8 (CS); also elsewhere on the board

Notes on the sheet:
SOUND OUT
ADC
MIDI
DAC
OPL3


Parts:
C39: 100n; C_0603_1608Metric_Pad1.08x0.95mm_HandSolder
U12: CY62167EV30LL; TSOP-I-48_18.4x12mm_P0.5mm

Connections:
+3V3: C39.2, U12.12 (CE2), U12.37 (VCC); also elsewhere on the board
GND: C39.1, U12.26 (~CE1), U12.27 (GND), U12.46 (GND), U12.47 (~BYTE); also elsewhere on the board
MA0: U12.25 (A0); also elsewhere on the board
MA1: U12.24 (A1); also elsewhere on the board
MA2: U12.23 (A2); also elsewhere on the board
MA3: U12.22 (A3); also elsewhere on the board
MA4: U12.21 (A4); also elsewhere on the board
MA5: U12.20 (A5); also elsewhere on the board
MA6: U12.19 (A6); also elsewhere on the board
MA7: U12.18 (A7); also elsewhere on the board
MA8: U12.8 (A8); also elsewhere on the board
MA9: U12.7 (A9); also elsewhere on the board
MA10: U12.6 (A10); also elsewhere on the board
MA11: U12.5 (A11); also elsewhere on the board
MA12: U12.4 (A12); also elsewhere on the board
MA13: U12.3 (A13); also elsewhere on the board
MA14: U12.2 (A14); also elsewhere on the board
MA15: U12.1 (A15); also elsewhere on the board
MA16: U12.48 (A16); also elsewhere on the board
MA17: U12.17 (A17); also elsewhere on the board
MA18: U12.16 (A18); also elsewhere on the board
MA19: U12.9 (A19); also elsewhere on the board
MA20: U12.45 (A20/D15); also elsewhere on the board
MD0: U12.29 (D0); also elsewhere on the board
MD1: U12.31 (D1); also elsewhere on the board
MD2: U12.33 (D2); also elsewhere on the board
MD3: U12.35 (D3); also elsewhere on the board
MD4: U12.38 (D4); also elsewhere on the board
MD5: U12.40 (D5); also elsewhere on the board
MD6: U12.42 (D6); also elsewhere on the board
MD7: U12.44 (D7); also elsewhere on the board
~MRD: U12.28 (~OE); also elsewhere on the board
~MWR: U12.11 (~WE); also elsewhere on the board

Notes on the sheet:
GS RAM


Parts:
C1, C2, C3, C4, C5, C7, C9, C11, C13: 100n; C_0603_1608Metric_Pad1.08x0.95mm_HandSolder
C6, C8, C10, C12: 100n; C_0603_1608Metric
TP1, TP2, TP3, TP4, TP5, TP6, TP7: TestPoint; TestPoint_Pad_D1.5mm
U1: XC6SLX25-FTG256; BGA-256_17.0x17.0mm_Layout16x16_P1.0mm_Ball0.5mm_Pad0.4mm_N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

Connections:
+1V2: C6.1, C8.1, C10.1, C12.1, U1.G7 (VCCINT), U1.G9 (VCCINT), U1.H8 (VCCINT), U1.H10 (VCCINT), U1.J7 (VCCINT), U1.J9 (VCCINT), U1.K8 (VCCINT), U1.K10 (VCCINT); also elsewhere on the board
+3V3: C1.1, C2.1, C3.1, C4.1, C5.1, C7.1, C9.1, C11.1, C13.1, U1.B4 (VCCO_0), U1.B9 (VCCO_0), U1.B13 (VCCO_0), U1.D7 (VCCO_0), U1.D10 (VCCO_0), U1.D15 (VCCO_1), U1.E5 (VCCAUX), U1.F8 (VCCAUX), U1.F11 (VCCAUX), U1.G10 (VCCAUX), U1.G13 (VCCO_1), U1.H6 (VCCAUX), U1.J10 (VCCAUX), U1.J15 (VCCO_1), U1.K13 (VCCO_1), U1.L6 (VCCAUX), U1.L9 (VCCAUX), U1.N15 (VCCO_1), U1.R13 (VCCO_1); also elsewhere on the board
GND: C1.2, C2.2, C3.2, C4.2, C5.2, C6.2, C7.2, C8.2, C9.2, C10.2, C11.2, C12.2, C13.2, U1.A1 (GND), U1.A16 (GND), U1.B7 (GND), U1.B11 (GND), U1.D4 (GND), U1.D13 (GND), U1.E9 (GND), U1.G2 (GND), U1.G8 (GND), U1.G15 (GND), U1.H7 (GND), U1.H9 (GND), U1.H12 (GND), U1.J5 (GND), U1.J8 (GND), U1.K7 (GND), U1.K9 (GND), U1.L2 (GND), U1.L15 (GND), U1.M8 (GND), U1.N13 (GND), U1.P3 (GND), U1.R6 (GND), U1.R10 (GND), U1.T1 (GND), U1.T16 (GND); also elsewhere on the board
MA0: U1.G16 (IO_L36N_A8_M1BA1_1); also elsewhere on the board
MA1: U1.H15 (IO_L37P_A7_M1A0_1); also elsewhere on the board
MA2: U1.H16 (IO_L37N_A6_M1A1_1); also elsewhere on the board
MA3: U1.J14 (IO_L43P_GCLK5_M1DQ4_1); also elsewhere on the board
MA4: U1.J16 (IO_L43N_GCLK4_M1DQ5_1); also elsewhere on the board
MA5: U1.K15 (IO_L44P_A3_M1DQ6_1); also elsewhere on the board
MA6: U1.K16 (IO_L44N_A2_M1DQ7_1); also elsewhere on the board
MA7: U1.L14 (IO_L47P_FWE_B_M1DQ0_1); also elsewhere on the board
MA8: U1.T15 (IO_L50N_M1UDQSN_1); also elsewhere on the board
MA9: U1.R14 (IO_L50P_M1UDQS_1); also elsewhere on the board
MA10: U1.R16 (IO_L49N_M1DQ11_1); also elsewhere on the board
MA11: U1.R15 (IO_L49P_M1DQ10_1); also elsewhere on the board
MA12: U1.P16 (IO_L48N_M1DQ9_1); also elsewhere on the board
MA13: U1.P15 (IO_L48P_HDC_M1DQ8_1); also elsewhere on the board
MA14: U1.N16 (IO_L45N_A0_M1LDQSN_1); also elsewhere on the board
MA15: U1.N14 (IO_L45P_A1_M1LDQS_1); also elsewhere on the board
MA16: U1.A14 (IO_L65N_SCP2_0); also elsewhere on the board
MA17: U1.L16 (IO_L47N_LDC_M1DQ1_1); also elsewhere on the board
MA18: U1.M15 (IO_L46P_FCS_B_M1DQ2_1); also elsewhere on the board
MA19: U1.T14 (IO_L51P_M1DQ12_1); also elsewhere on the board
MA20: U1.B16 (IO_L29N_A22_M1A14_1); also elsewhere on the board
MD0: U1.F16 (IO_L35N_A10_M1A2_1); also elsewhere on the board
MD1: U1.F15 (IO_L35P_A11_M1A7_1); also elsewhere on the board
MD2: U1.E16 (IO_L34N_A12_M1BA2_1); also elsewhere on the board
MD3: U1.E15 (IO_L34P_A13_M1WE_1); also elsewhere on the board
MD4: U1.D16 (IO_L31N_A18_M1A12_1); also elsewhere on the board
MD5: U1.C15 (IO_L33P_A15_M1A10_1); also elsewhere on the board
MD6: U1.C16 (IO_L33N_A14_M1A4_1); also elsewhere on the board
MD7: U1.B15 (IO_L29P_A23_M1A13_1); also elsewhere on the board
unnamed: TP7.1 (1_1), U1.F14 (IO_L32N_A16_M1A9_1)
unnamed: TP6.1 (1_1), U1.F13 (IO_L32P_A17_M1A8_1)
unnamed: TP5.1 (1_1), U1.G12 (IO_L38P_A5_M1CLK_1)
unnamed: TP2.1 (1_1), U1.A11 (IO_L39N_0)
unnamed: TP1.1 (1_1), U1.A12 (IO_L62N_VREF_0)
unnamed: TP3.1 (1_1), U1.B12 (IO_L62P_0)
unnamed: TP4.1 (1_1), U1.C13 (IO_L63P_SCP7_0)
VU_L3: U1.A4 (IO_L1N_VREF_0); also elsewhere on the board
VU_L4: U1.A5 (IO_L2N_0); also elsewhere on the board
VU_L5: U1.B5 (IO_L2P_0); also elsewhere on the board
VU_L6: U1.A6 (IO_L4N_0); also elsewhere on the board
VU_L7: U1.B6 (IO_L4P_0); also elsewhere on the board
VU_R0: U1.A8 (IO_L33N_0); also elsewhere on the board
VU_R1: U1.A7 (IO_L6N_0); also elsewhere on the board
VU_R2: U1.B8 (IO_L33P_0); also elsewhere on the board
VU_R3: U1.A9 (IO_L34N_GCLK18_0); also elsewhere on the board
VU_R4: U1.A10 (IO_L35N_GCLK16_0); also elsewhere on the board
xD1: U1.D5 (IO_L3P_0); also elsewhere on the board
xD3: U1.R12 (IO_L52P_M1DQ14_1); also elsewhere on the board
xD6: U1.C4 (IO_L1P_HSWAPEN_0); also elsewhere on the board
~BTN_RST: U1.A13 (IO_L63N_SCP6_0); also elsewhere on the board
~MRD: U1.G14 (IO_L36P_A9_M1BA0_1); also elsewhere on the board
~MWR: U1.M16 (IO_L46N_FOE_B_M1DQ3_1); also elsewhere on the board
~xIORQ: U1.T12 (IO_L52N_M1DQ15_1); also elsewhere on the board
~xMREQ: U1.T13 (IO_L51N_M1DQ13_1); also elsewhere on the board


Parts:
C40, C43, C44, C45, C46, C48, C49, C54, C55: 100n; C_0603_1608Metric_Pad1.08x0.95mm_HandSolder
C41: 100u/16V; CP_Elec_6.3x7.7
C42, C50, C52: 10u; C_0603_1608Metric_Pad1.08x0.95mm_HandSolder
C47, C51, C53: 22u; CP_EIA-3216-18_Kemet-A_HandSolder
J5: 5V_PRG; PinHeader_1x02_P2.54mm_Vertical; not fitted
L1: 1uH; L_0603_1608Metric_Pad1.05x0.95mm_HandSolder
R27: 0; R_0603_1608Metric_Pad0.98x0.95mm_HandSolder
R28, R29: 0; R_0603_1608Metric_Pad0.98x0.95mm_HandSolder; not fitted
U13, U14: 1117-3.3; SOT-223-3_TabPin2
U15: 1117-1.2; SOT-223-3_TabPin2

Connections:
+1V2: C53.1, U15.2 (VO); also elsewhere on the board
+3V3: C40.1, C43.1, C45.1, C46.1, C47.1, C48.1, U13.2 (VO); also elsewhere on the board
+3V3A: C49.1, C51.1, U14.2 (VO); also elsewhere on the board
+5V: C41.1, C42.1, C44.2, C50.1, C52.1, C54.1, J5.1, L1.1, U13.3 (VI), U14.3 (VI), U15.3 (VI); also elsewhere on the board
+5VA: C55.1, L1.2; also elsewhere on the board
AGND: C49.2, C55.2, R27.1, R28.1, R29.1; also elsewhere on the board
GND: C40.2, C41.2, C42.2, C43.2, C44.1, C45.2, C46.2, C47.2, C48.2, C50.2, C51.2, C52.2, C53.2, C54.2, J5.2, R27.2, R28.2, R29.2, U13.1 (GND), U14.1 (GND), U15.1 (GND); also elsewhere on the board

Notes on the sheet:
POWER

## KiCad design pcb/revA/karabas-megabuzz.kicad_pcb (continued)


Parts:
BTN1: Reset; SW_SPST_PTS810_handsoldering
J2: Conn_02x30_Row_Letter_First; ZX_NEMO_60_EDGE
R5, R6, R7, R8, R9, R10, R11, R46: 10k; R_0603_1608Metric_Pad0.98x0.95mm_HandSolder
R12: 47k; R_0603_1608Metric_Pad0.98x0.95mm_HandSolder
SW1: SW_DIP_x05; SW_DIP_SPSTx05_Slide_6.7x14.26mm_W7.62mm_P2.54mm_LowProfile
U3: 74AHCT1G125DB; SOT-23-5_HandSoldering
U4, U5, U6, U7: SN74CB3T3245PW; TSSOP-20_4.4x6.5mm_P0.65mm
U22: SN74LV1T34DBV; SOT-23-5_HandSoldering

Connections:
+3V3: R5.1, R6.1, R7.1, R8.1, R9.1, R46.1, U4.20 (VCC), U5.20 (VCC), U6.20 (VCC), U7.20 (VCC), U22.5 (VCC); also elsewhere on the board
+5V: J2.a29, J2.b28, R10.1, R11.1, R12.1, U3.2, U3.5 (VCC); also elsewhere on the board
+12V: J2.b29
A0: J2.a9, U5.14 (B4)
A1: J2.a10, U5.13 (B5)
A2: J2.a11, U5.12 (B6)
A3: J2.a12, U5.11 (B7)
A4: J2.a24, U7.13 (B5)
A5: J2.a23, U7.12 (B6)
A6: J2.a22, U7.11 (B7)
A7: J2.a21, U5.18 (B0)
A8: J2.b26, U7.17 (B1)
A9: J2.a27, U7.14 (B4)
A10: J2.b27, U7.18 (B0)
A11: J2.a28, U7.15 (B3)
A12: J2.a2, U5.16 (B2)
A13: J2.b2, U4.17 (B1)
A14: J2.a1, U5.17 (B1)
A15: J2.b1, U4.18 (B0)
CFG0: R5.2, SW1.1; also elsewhere on the board
CFG1: R6.2, SW1.2; also elsewhere on the board
CFG2: R7.2, SW1.3; also elsewhere on the board
CFG3: R8.2, SW1.4; also elsewhere on the board
CFG4: R9.2, SW1.5; also elsewhere on the board
D0: J2.b6, U4.15 (B3); also elsewhere on the board
D1: J2.b7, U4.14 (B4); also elsewhere on the board
D2: J2.b8, U4.13 (B5); also elsewhere on the board
D3: J2.b11, U6.11 (B7); also elsewhere on the board
D4: J2.b12, U6.12 (B6); also elsewhere on the board
D5: J2.b10, U4.11 (B7); also elsewhere on the board
D6: J2.b9, U4.12 (B6); also elsewhere on the board
D7: J2.b3, U4.16 (B2); also elsewhere on the board
GND: BTN1.2, J2.a6, J2.a7, J2.a14, J2.a30, J2.b30, SW1.6, SW1.7, SW1.8, SW1.9, SW1.10, U3.3 (GND), U4.10 (GND), U4.19 (CE), U5.10 (GND), U5.19 (CE), U6.10 (GND), U6.19 (CE), U7.10 (GND), U7.19 (CE), U22.3 (GND); also elsewhere on the board
unnamed: J2.a13, U3.4
xA0: U5.6 (A4); also elsewhere on the board
xA1: U5.7 (A5); also elsewhere on the board
xA2: U5.8 (A6); also elsewhere on the board
xA3: U5.9 (A7); also elsewhere on the board
xA4: U7.7 (A5); also elsewhere on the board
xA5: U7.8 (A6); also elsewhere on the board
xA6: U7.9 (A7); also elsewhere on the board
xA7: U5.2 (A0); also elsewhere on the board
xA8: U7.3 (A1); also elsewhere on the board
xA9: U7.6 (A4); also elsewhere on the board
xA10: U7.2 (A0); also elsewhere on the board
xA11: U7.5 (A3); also elsewhere on the board
xA12: U5.4 (A2); also elsewhere on the board
xA13: U4.3 (A1); also elsewhere on the board
xA14: U5.3 (A1); also elsewhere on the board
xA15: U4.2 (A0); also elsewhere on the board
xD0: U4.5 (A3); also elsewhere on the board
xD1: U4.6 (A4); also elsewhere on the board
xD2: U4.7 (A5); also elsewhere on the board
xD3: U6.9 (A7); also elsewhere on the board
xD4: U6.8 (A6); also elsewhere on the board
xD5: U4.9 (A7); also elsewhere on the board
xD6: U4.8 (A6); also elsewhere on the board
xD7: U4.4 (A2); also elsewhere on the board
~BTN_RST: BTN1.1, R46.2; also elsewhere on the board
~DOS: J2.a4, R11.2, U5.15 (B3)
~IODOS: J2.b20, R10.2, U6.17 (B1)
~IORQGE: U3.1; also elsewhere on the board
~IORQ: J2.b17, U6.14 (B4)
~M1: J2.b24, U7.16 (B2)
~MREQ: J2.b16, U6.13 (B5)
~RD: J2.b18, R12.2, U6.15 (B3); also elsewhere on the board
~RST: J2.a20, U22.2 (A)
~WAIT: J2.b21, U6.18 (B0)
~WR: J2.b19, U6.16 (B2); also elsewhere on the board
~xDOS: U5.5 (A3); also elsewhere on the board
~xIODOS: U6.3 (A1); also elsewhere on the board
~xIORQ: U6.6 (A4); also elsewhere on the board
~xM1: U7.4 (A2); also elsewhere on the board
~xMREQ: U6.7 (A5); also elsewhere on the board
~xRD: U6.5 (A3); also elsewhere on the board
~xRST: U22.4 (Y); also elsewhere on the board
~xWAIT: U6.2 (A0); also elsewhere on the board
~xWR: U6.4 (A2); also elsewhere on the board

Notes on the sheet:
CONFIGURATION
LEVEL SHIFTERS
NEMOBUS SLOT
RESET BUTTON


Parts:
C14, C15: 100n; C_0603_1608Metric_Pad1.08x0.95mm_HandSolder
J1: FPGA JTAG; PinHeader_2x05_P2.54mm_Vertical; not fitted
JP1: Flash; SolderJumper-2_P1.3mm_Bridged_RoundedPad1.0x1.5mm
R1: 27; R_0603_1608Metric_Pad0.98x0.95mm_HandSolder
R2, R3, R4: 10k; R_0603_1608Metric_Pad0.98x0.95mm_HandSolder
TP8, TP9, TP10, TP11, TP12, TP13, TP14, TP15, TP16, TP17, TP18: TestPoint; TestPoint_Pad_D1.5mm
U1: XC6SLX25-FTG256; BGA-256_17.0x17.0mm_Layout16x16_P1.0mm_Ball0.5mm_Pad0.4mm_N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
U2: W25Q128JVS; SOIC-8_5.3x5.3mm_P1.27mm
X1: 50 MHz; Oscillator_SMD_SeikoEpson_SG8002CA-4Pin_7.0x5.0mm

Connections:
+3V3: C14.1, C15.1, J1.4, R2.2, R3.2, R4.2, U1.D2 (VCCO_3), U1.G4 (VCCO_3), U1.J2 (VCCO_3), U1.K4 (VCCO_3), U1.N2 (VCCO_3), U1.N7 (VCCO_2), U1.N10 (VCCO_2), U1.R4 (VCCO_2), U1.R8 (VCCO_2), U1.T11 (IO_L1N_M0_CMPMISO_2), U2.8 (VCC), X1.1 (~ST), X1.4 (VCC); also elsewhere on the board
/FPGA2/CLK: R1.1, X1.3 (OUT)
ADC_BCK: U1.F1 (IO_L41N_GCLK26_M3DQ5_3); also elsewhere on the board
ADC_CLK: U1.F2 (IO_L41P_GCLK27_M3DQ4_3); also elsewhere on the board
ADC_DOUT: U1.E2 (IO_L46P_M3CLK_3); also elsewhere on the board
ADC_LRCK: U1.E1 (IO_L46N_M3CLKN_3); also elsewhere on the board
CFG0: U1.H4 (IO_L44P_GCLK21_M3A5_3); also elsewhere on the board
CFG1: U1.H5 (IO_L43N_GCLK22_IRDY2_M3CASN_3); also elsewhere on the board
CFG2: U1.J6 (IO_L43P_GCLK23_M3RASN_3); also elsewhere on the board
CFG3: U1.J4 (IO_L42N_GCLK24_M3LDM_3); also elsewhere on the board
CFG4: U1.K5 (IO_L47P_M3A0_3); also elsewhere on the board
CLK_50MHZ: R1.2, U1.T8 (IO_L30N_GCLK0_USERCCLK_2)
CONF_CLK: TP13.1 (1_1), U1.R11 (IO_L1P_CCLK_2), U2.6 (CLK)
CONF_DONE: TP10.1 (1_1), U1.P13 (DONE_2)
CONF_INIT_B: TP9.1 (1_1), U1.R3 (IO_L65P_INIT_B_2)
CONF_IO0: TP14.1 (1_1), U1.T10 (IO_L3N_MOSI_CSI_B_MISO0_2), U2.5 (DI(IO0))
CONF_IO1: TP15.1 (1_1), U1.P10 (IO_L3P_D0_DIN_MISO_MISO1_2), U2.2 (DO(IO1))
CONF_IO2: TP16.1 (1_1), U1.N12 (IO_L12P_D1_MISO2_2), U2.3 (IO2)
CONF_IO3: TP17.1 (1_1), U1.P12 (IO_L12N_D2_MISO3_2), U2.7 (IO3)
CONF_M1: JP1.2 (B), R4.1, TP18.1 (1_1), U1.N11 (IO_L13P_M1_2)
CONF_PRG_B: R3.1, TP11.1 (1_1), U1.T2 (PROGRAM_B_2)
DAC_BCK: U1.H2 (IO_L39P_M3LDQS_3); also elsewhere on the board
DAC_DAT: U1.H1 (IO_L39N_M3LDQSN_3); also elsewhere on the board
DAC_WS: U1.G1 (IO_L40N_M3DQ7_3); also elsewhere on the board
GND: C14.2, C15.2, J1.2, J1.10, JP1.1 (A), U1.P14 (SUSPEND), U2.4 (GND), X1.2 (GND); also elsewhere on the board
MIDI_CLK: U1.C1 (IO_L50P_M3WE_3); also elsewhere on the board
MIDI_IN: U1.D1 (IO_L49N_M3A2_3); also elsewhere on the board
unnamed: TP8.1 (1_1), U1.M12 (IO_L2P_CMPCLK_2)
TCK: J1.1, U1.C14 (TCK)
TDI: J1.9, U1.C12 (TDI)
TDO: J1.3, U1.E14 (TDO)
TMS: J1.5, U1.A15 (TMS)
VU_L0: U1.A2 (IO_L52N_M3A9_3); also elsewhere on the board
VU_L1: U1.B3 (IO_L83P_3); also elsewhere on the board
VU_L2: U1.A3 (IO_L83N_VREF_3); also elsewhere on the board
VU_R5: U1.M2 (IO_L35P_M3DQ10_3); also elsewhere on the board
VU_R6: U1.M3 (IO_L1N_VREF_3); also elsewhere on the board
VU_R7: U1.M4 (IO_L1P_3); also elsewhere on the board
YM_A0: U1.B2 (IO_L52P_M3A8_3); also elsewhere on the board
YM_A1: U1.B1 (IO_L50N_M3BA2_3); also elsewhere on the board
YM_CLK14: U1.L3 (IO_L36P_M3DQ8_3); also elsewhere on the board
YM_DATA: U1.K1 (IO_L37N_M3DQ1_3); also elsewhere on the board
YM_DCLK: U1.L1 (IO_L36N_M3DQ9_3); also elsewhere on the board
YM_SMP1: U1.J3 (IO_L38P_M3DQ2_3); also elsewhere on the board
YM_SMP2: U1.J1 (IO_L38N_M3DQ3_3); also elsewhere on the board
xA0: U1.P9 (IO_L14N_D12_2); also elsewhere on the board
xA1: U1.P8 (IO_L30P_GCLK1_D13_2); also elsewhere on the board
xA2: U1.N9 (IO_L14P_D11_2); also elsewhere on the board
xA3: U1.M9 (IO_L29P_GCLK3_2); also elsewhere on the board
xA4: U1.T5 (IO_L48N_RDWR_B_VREF_2); also elsewhere on the board
xA5: U1.R5 (IO_L48P_D7_2); also elsewhere on the board
xA6: U1.T4 (IO_L63N_2); also elsewhere on the board
xA7: U1.P5 (IO_L49N_D4_2); also elsewhere on the board
xA8: U1.R7 (IO_L32P_GCLK29_2); also elsewhere on the board
xA9: U1.P6 (IO_L47P_2); also elsewhere on the board
xA10: U1.T7 (IO_L32N_GCLK28_2); also elsewhere on the board
xA11: U1.T6 (IO_L47N_2); also elsewhere on the board
xA12: U1.R2 (IO_L32P_M3DQ14_3); also elsewhere on the board
xA13: U1.E3 (IO_L54N_M3A11_3); also elsewhere on the board
xA14: U1.P4 (IO_L63P_2); also elsewhere on the board
xA15: U1.G3 (IO_L40P_M3DQ6_3); also elsewhere on the board
xD0: U1.F4 (IO_L53P_M3CKE_3); also elsewhere on the board
xD2: U1.M1 (IO_L35N_M3DQ11_3); also elsewhere on the board
xD4: U1.P11 (IO_L13N_D10_2); also elsewhere on the board
xD5: U1.N1 (IO_L34N_M3UDQSN_3); also elsewhere on the board
xD7: U1.F3 (IO_L53N_M3A12_3); also elsewhere on the board
~CONF_CS: R2.1, TP12.1 (1_1), U1.T3 (IO_L65N_CSO_B_2), U2.1 (~CS)
~IORQGE: U1.D3 (IO_L49P_M3A7_3); also elsewhere on the board
~MIDI_RST: U1.C3 (IO_L48P_M3BA0_3); also elsewhere on the board
~YM_CS: U1.C2 (IO_L48N_M3BA1_3); also elsewhere on the board
~xDOS: U1.P2 (IO_L33P_M3DQ12_3); also elsewhere on the board
~xIODOS: U1.M10 (IO_L16N_VREF_2); also elsewhere on the board
~xM1: U1.P7 (IO_L31P_GCLK31_D14_2); also elsewhere on the board
~xRD: U1.P1 (IO_L33N_M3DQ13_3); also elsewhere on the board
~xRST: U1.L5 (IO_L45N_M3ODT_3); also elsewhere on the board
~xWAIT: U1.N8 (IO_L29N_GCLK2_2); also elsewhere on the board
~xWR: U1.R1 (IO_L32N_M3DQ15_3); also elsewhere on the board

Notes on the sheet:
CONF FLASH
JTAG
MASTER CLOCK



Board: 4 copper layers, 92.2 x 44.0 mm, 162 parts (119 on the bottom side), 213 nets.

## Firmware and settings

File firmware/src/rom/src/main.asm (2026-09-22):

; =============================================================================
; Karabas MegaBuzz Configurator ROM
; main entry point
; =============================================================================

;        DEFINE DEBUG_MODE
;        DEFINE EMU_MODE

        DEVICE ZXSPECTRUM48
;        OUTPUT "megabuzz.rom"

        ORG 0x0000

; UI constants
NUM_CHECKBOXES  EQU 11                              ; count of checkboxes
INDEX_APPLY     EQU NUM_CHECKBOXES                  ; Apply button index
INDEX_CANCEL    EQU NUM_CHECKBOXES + 1              ; Cancel button index
BUTTONS_ROW     EQU 5 + NUM_CHECKBOXES + 2          ; buttons row
DEBUG_ROW       EQU BUTTONS_ROW + 2                 ; debug info row

Start:
        DI
        LD SP, 0xBD00       ; Init safe stack

        JP RealStart

        INCLUDE "screen.asm"
        INCLUDE "megabuzz.asm"
        INCLUDE "keyboard.asm"

RealStart:
        CALL Screen.Clear : CALL Screen.ResetAttributes
        LD DE, LoadingText : LD BC, 0x0504 : CALL Screen.PrintString
        XOR A : LD (SelectedOption), A : LD (CheckboxState), A : LD (CheckboxState2), A
        CALL MegaBuzz.WaitFlash
        CALL Screen.Clear : CALL Screen.ResetAttributes
        CALL MegaBuzz.WaitFlash
        CALL MegaBuzz.ReadConfig : LD (CheckboxState), A
        CALL MegaBuzz.WaitFlash
        CALL MegaBuzz.ReadConfig2 : LD (CheckboxState2), A
        CALL MegaBuzz.WaitFlash
        CALL DrawStaticInterface

MainLoop:
        CALL KeyDelay       

.WaitKey:
        CALL Keyboard.Scan   
        LD B, A                 

        CP Keyboard.KEY_UP                 
        JR NZ, .NotUp
        LD A, (SelectedOption)
        AND A
        JR Z, .WaitKey

        LD (OldSelectedOption), A        
        DEC A
        LD (SelectedOption), A
        CALL UpdateFocus
        JR MainLoop

.NotUp:
        CP Keyboard.KEY_DOWN                 
        JR NZ, .NotDown
        LD A, (SelectedOption)
        CP INDEX_CANCEL
        JR Z, .WaitKey 
        
        LD (OldSelectedOption), A         
        INC A
        LD (SelectedOption), A
        CALL UpdateFocus
        JR MainLoop

.NotDown:
        CP Keyboard.KEY_SELECT                 
        JR NZ, .WaitKey

        LD A, (SelectedOption)
        CP INDEX_APPLY
        JR Z, ActionApply       
        CP INDEX_CANCEL
        JR Z, ActionCancel      

        LD A, (SelectedOption)
        CP 8
        JR NC, .BitInState2

        LD C, A                 
        LD B, 1                 
        INC C
.ShiftLoop1:
        DEC C
        JR Z, .ShiftDone1
        SLA B                   
        JR .ShiftLoop1
.ShiftDone1:
        LD A, (CheckboxState)
        XOR B                   
        LD (CheckboxState), A
        JR .Redraw

.BitInState2:
        SUB 8
        LD C, A                 
        LD B, 1                 
        INC C
.ShiftLoop2:
        DEC C
        JR Z, .ShiftDone2
        SLA B                   
        JR .ShiftLoop2
.ShiftDone2:
        LD A, (CheckboxState2)
        XOR B                   
        LD (CheckboxState2), A

.Redraw:
        LD A, (SelectedOption)
        CALL RedrawSingleCheckbox
        JR MainLoop

ActionApply:
        CALL Screen.Clear : CALL Screen.ResetAttributes
        LD DE, SavingText : LD BC, 0x0504 : CALL Screen.PrintString        
        LD A, (CheckboxState) : CALL MegaBuzz.ApplyConfig
        LD A, (CheckboxState2) : CALL MegaBuzz.ApplyConfig2

ActionCancel:
        CALL Screen.Clear : CALL Screen.ResetAttributes
        LD DE, DoneText : LD BC, 0x0504 : CALL Screen.PrintString

        ;CALL MegaBuzz.Cancel   
        ;LD SP, 0xFFFF : JP 0x0000

        ; Copy executable code into ram at 0x8000 and execute it
        LD HL, RelocatableCode_Start
        LD DE, 0x8000
        LD BC, RelocatableCode_End - RelocatableCode_Start
        LDIR
        JP 0x8000

RelocatableCode_Start:
        ; disable cfg rom
        ld a, MegaBuzz.REG_ROMBANK : ld bc, MegaBuzz.PORT_ZXUNO_REG : out (c), a
        xor a : ld bc, MegaBuzz.PORT_ZXUNO_DATA : out (c), a
        ; jump to ZX ROM start
        LD SP, 0xFFFF : JP #0000
RelocatableCode_End:

KeyDelay:
        LD BC, 0x3FFF       
.Loop:
        DEC BC
        LD A, B
        OR C
        JR NZ, .Loop
        RET

DrawStaticInterface:
        LD DE, TitleText : LD BC, 0x0200 : CALL Screen.PrintString

        IFDEF EMU_MODE
        LD DE, Str_Help1 : LD BC, 0x1600 : CALL Screen.PrintString
        LD DE, Str_Help2 : LD BC, 0x1700 : CALL Screen.PrintString
        ENDIF

        ; Checkboxes (rows 5 и далее)
        XOR A : LD (CurrentStep), A
.LoopCB:
        LD A, (CurrentStep)
        LD C, 4             
        ADD A, 5            
        LD B, A             ; row 5+
        
        PUSH BC
        CALL GetCBText
        CALL Screen.PrintString    
        POP BC

        LD A, C
        ADD A, 5
        LD C, A             ; Text offset

        LD A, (CurrentStep)
        CALL GetOptionTextAddress
        CALL Screen.PrintString

        LD A, (CurrentStep)
        INC A
        LD (CurrentStep), A
        CP NUM_CHECKBOXES
        JR NZ, .LoopCB

        IFDEF DEBUG_MODE
        LD DE, Str_DebugCurr
        LD B, DEBUG_ROW : LD C, 4
        CALL Screen.PrintString
        LD A, (CheckboxState2)
        LD B, DEBUG_ROW : LD C, 9
        CALL Screen.PrintHexByte
        LD A, (CheckboxState)
        LD B, DEBUG_ROW : LD C, 11
        CALL Screen.PrintHexByte
        ENDIF

        LD B, BUTTONS_ROW : LD C, 4 : LD D, 9
        CALL Screen.ColorizeButtonDefault
        LD B, BUTTONS_ROW : LD C, 18 : LD D, 10
        CALL Screen.ColorizeButtonDefault

        LD DE, Btn_Apply : LD B, BUTTONS_ROW : LD C, 4 : CALL Screen.PrintString
        LD DE, Btn_Cancel : LD B, BUTTONS_ROW : LD C, 18 : CALL Screen.PrintString

        LD B, 5 : LD C, 4 : LD D, 24
        CALL Screen.ColorizeHighlight
        RET

UpdateFocus:
        LD A, (OldSelectedOption)
        CP INDEX_APPLY
        JR Z, .ClearApply
        CP INDEX_CANCEL
        JR Z, .ClearCancel
        
        ADD A, 5
        LD B, A : LD C, 4 : LD D, 24
        CALL Screen.ColorizeNormal
        JR .DrawNewFocus

.ClearApply:
        LD B, BUTTONS_ROW : LD C, 4 : LD D, 9
        CALL Screen.ColorizeButtonDefault
        JR .DrawNewFocus

.ClearCancel:
        LD B, BUTTONS_ROW : LD C, 18 : LD D, 10
        CALL Screen.ColorizeButtonDefault

.DrawNewFocus:
        LD A, (SelectedOption)
        CP INDEX_APPLY
        JR Z, .SetApply
        CP INDEX_CANCEL
        JR Z, .SetCancel

        ADD A, 5
        LD B, A : LD C, 4 : LD D, 24
        CALL Screen.ColorizeHighlight
        RET
.SetApply:
        LD B, BUTTONS_ROW : LD C, 4 : LD D, 9
        CALL Screen.ColorizeHighlight
        RET
.SetCancel:
        LD B, BUTTONS_ROW : LD C, 18 : LD D, 10
        CALL Screen.ColorizeHighlight
        RET

RedrawSingleCheckbox:
        PUSH AF             
        LD (CurrentStep), A 
        ADD A, 5
        LD B, A             
        LD C, 4             
        CALL GetCBText      
        CALL Screen.PrintString

        IFDEF DEBUG_MODE        
        LD A, (CheckboxState2)
        LD B, DEBUG_ROW : LD C, 9
        CALL Screen.PrintHexByte
        LD A, (CheckboxState)
        LD B, DEBUG_ROW : LD C, 11
        CALL Screen.PrintHexByte
        ENDIF        

        POP AF              
        RET

GetCBText:
        LD A, (CurrentStep) 
        CP 8
        JR NC, .GetFromState2

        LD E, A
        INC E
        LD A, (CheckboxState)
.Loop1:
        DEC E
        JR Z, .Done
        SRL A
        JR .Loop1

.GetFromState2:
        SUB 8
        LD E, A
        INC E
        LD A, (CheckboxState2)
.Loop2:
        DEC E
        JR Z, .Done
        SRL A
        JR .Loop2

.Done:
        AND 1
        LD DE, CB_Unselected
        RET Z
        LD DE, CB_Selected
        RET

GetOptionTextAddress:
        LD L, A
        LD H, 0
        ADD HL, HL          
        LD DE, OptionTexts
        ADD HL, DE
        LD E, (HL)
        INC HL
        LD D, (HL)
        RET

; Text data
TitleText:       DB "  KARABAS MEGABUZZ CONFIG v1.3  ", 0
LoadingText:     DB "Loading...", 0
SavingText:      DB "Saving...", 0
DoneText:        DB "Done! Safe to reboot", 0
CB_Unselected:   DB "[ ]", 0
CB_Selected:     DB "[x]", 0
Btn_Apply:       DB "  APPLY  ", 0
Btn_Cancel:      DB "  CANCEL  ", 0

; Options
Str_Opt1:        DB "DivMMC ", 0
Str_Opt2:        DB "ZC ", 0
Str_Opt3:        DB "Soundrive ", 0
Str_Opt4:        DB "Beeper ", 0
Str_Opt5:        DB "SAA1099 ", 0
Str_Opt6:        DB "GS ", 0
Str_Opt7:        DB "TSFM / MIDI ", 0
Str_Opt8:        DB "OPL3 ", 0
Str_Opt9:        DB "VU bar", 0
Str_Opt10:       DB "VU dot", 0
Str_Opt11:       DB "VU reversed", 0

    IFDEF DEBUG_MODE
Str_DebugCurr:   DB "VAL: #", 0
    ENDIF

    IFDEF EMU_MODE
Str_Help1:       DB "Please use UP/DOWN to navigate,", 0
Str_Help2:       DB "Use Enter or Space to change", 0
    ENDIF

OptionTexts:
        DW Str_Opt1, Str_Opt2, Str_Opt3, Str_Opt4
        DW Str_Opt5, Str_Opt6, Str_Opt7, Str_Opt8
        DW Str_Opt9, Str_Opt10, Str_Opt11

; Variables
SelectedOption:    EQU 0x5C00  
CheckboxState:     EQU 0x5C01
CheckboxState2:    EQU 0x5C02  
CurrentStep:       EQU 0x5C03
OldSelectedOption: EQU 0x5C04

; Expand ROM to 2KB
        IFDEF EMU_MODE
        BLOCK 16384-$, 0
        ELSE
        BLOCK 2048-$, 0
        ENDIF

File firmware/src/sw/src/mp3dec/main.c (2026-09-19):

/**
 * MP3 decoder firmware. 
 * VS1053 emulation:
 * - SPI + DREQ for incoming data
 * - CSF + DATA_READY for decoded stereo data
 */

#include <neorv32.h>

#ifdef __cplusplus
extern "C" {
#endif
#include "lib/mp3dec.h"
#ifdef __cplusplus
}
#endif

#define BAUD_RATE        115200    // UART baud
#define DREQ_PIN         0         // GPIO output: 1 - host can send 32 bytes by SPI
#define DATA_READY_PIN   1         // GPIO output: PCM data ready strobe

#define RING_BUF_SIZE   4096       // Ring buffer size
uint8_t ring_buf[RING_BUF_SIZE];
volatile uint32_t head = 0;
volatile uint32_t tail = 0;

// Get data from SDI buffer (our SPI-Slave)
void check_and_receive_spi_stream(void) {
    while (!neorv32_sdi_rx_empty()) {
        uint32_t next = (head + 1) & (RING_BUF_SIZE - 1);
        if (next != tail) {
            ring_buf[head] = (uint8_t)neorv32_sdi_get_nonblocking();
            head = next;
        } else {
            break; // Ring buffer overflow
        }
    }
}

uint32_t ring_buf_free_space(void) {
    return RING_BUF_SIZE - 1 - ((head - tail) & (RING_BUF_SIZE - 1));
}

int main(void) {
    
    neorv32_rte_setup();

    neorv32_uart0_setup(BAUD_RATE, 0);

    if (neorv32_uart0_available() == 0) {
        return 1;
    }
    
    neorv32_uart0_printf("\n<<< NEORV32 MP3 decoder >>>\n\n");

    if (neorv32_sdi_available() == 0) {
        neorv32_uart0_printf("ERROR! No SDI unit implemented.");
        return 1;
    }

    if (neorv32_smc_available() == 0) {
        neorv32_uart0_printf("ERROR! No SMC unit implemented.\n");
        return 1;
    }

    if (neorv32_gpio_available() == 0) { // GPIO available?
        neorv32_uart0_printf("ERROR! No GPIO module implemented!\n");
        return 1;
    }

    // setup SDI module
    neorv32_sdi_setup(0); // no interrupts

    // setup GPIO (pin, value)
    neorv32_gpio_pin_set(DREQ_PIN, 0);       // Default: DREQ = 0
    neorv32_gpio_pin_set(DATA_READY_PIN, 0); // Default: DATA_READY = 0

    // setup SMC (PSRAM)
    neorv32_smc_setup(
        0,             // single-chip mode; use only one PSRAM
        SMC_MSIZE_8MB, // PSRAM size = 8MB
        6,             // clock prescaler; use second-slowest PSRAM clock as default
        0,             // wait cycles for read access
        0x03,          // read command
        0x02,          // write command
        0x996600       // initialization sequence: 1. NOP (0x00), 2. RESET-EN (0x66), 3. RESET (0x99)
    );

    // get configured PSRAM clock speed in Hz
    uint32_t psram_fclk = neorv32_smc_get_clockspeed();
    neorv32_uart0_printf("PSRAM clock: %u Hz\n", psram_fclk);

    // get PSRAM base address (configured via top generic)
    uint32_t psram_base = neorv32_smc_get_baseaddr();
    neorv32_uart0_printf("PSRAM base:  0x%x\n", psram_base);


    // init MP3 decoder    
    HMP3Decoder hMP3Decoder = MP3InitDecoder();
    MP3FrameInfo mp3FrameInfo;
    
    uint8_t local_dec_buf[2 * MAINBUF_SIZE]; 
    short pcm_out_buf[1152 * 2];

    while(1) {
        // DREQ control logic for external hw
        if (ring_buf_free_space() >= 32) {
            neorv32_gpio_pin_set(DREQ_PIN, 1);
        } else {
            neorv32_gpio_pin_set(DREQ_PIN, 0);
        }

        // Receive data by SPI
        check_and_receive_spi_stream();

        // If is enough data to decode a frame
        uint32_t available = (head - tail) & (RING_BUF_SIZE - 1);
        if (available >= MAINBUF_SIZE) {
            
            for(int i = 0; i < MAINBUF_SIZE; i++) {
                local_dec_buf[i] = ring_buf[tail];
                tail = (tail + 1) & (RING_BUF_SIZE - 1);
            }
            
            int bytesLeft = MAINBUF_SIZE;
            uint8_t *readPtr = local_dec_buf;
            
            int offset = MP3FindSyncWord(readPtr, bytesLeft);
            if (offset >= 0) {
                readPtr += offset;
                bytesLeft -= offset;
                
                int err = MP3Decode(hMP3Decoder, &readPtr, &bytesLeft, pcm_out_buf, 0);
                if (err == ERR_MP3_NONE) {
                    MP3GetLastFrameInfo(hMP3Decoder, &mp3FrameInfo);
                    int samples = mp3FrameInfo.outputSamps;
                    
                    // Otput decoded audio data to CFS ports
                    if (mp3FrameInfo.nChans == 2) {
                        // Stereo streasm
                        for (int i = 0; i < samples; i += 2) {
                            NEORV32_CFS->REG[0] = (uint32_t)pcm_out_buf[i];   // Index [0] - Left
                            NEORV32_CFS->REG[1] = (uint32_t)pcm_out_buf[i+1]; // Index [1] - Right
                            
                            neorv32_gpio_pin_set(DATA_READY_PIN, 1);
                            asm volatile("nop");
                            neorv32_gpio_pin_set(DATA_READY_PIN, 0);
                        }
                    } else {
                        // Mono stream
                        for (int i = 0; i < samples; i++) {
                            NEORV32_CFS->REG[0] = (uint32_t)pcm_out_buf[i];
                            NEORV32_CFS->REG[1] = (uint32_t)pcm_out_buf[i];
                            
                            neorv32_gpio_pin_set(DATA_READY_PIN, 1);
                            asm volatile("nop");
                            neorv32_gpio_pin_set(DATA_READY_PIN, 0);
                        }
                    }

                }
            }
        }
    }
    return 0;
}

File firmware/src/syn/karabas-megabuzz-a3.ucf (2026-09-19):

# Karabas-MegaBuzz rev.A3 pinout

VCCAUX = 3.3;

# CLOCK
NET "clk"                 LOC="T8"    | IOSTANDARD = LVTTL;

# CFG
NET "cfg_n<5>"            LOC="H14"   | IOSTANDARD = LVCMOS33 | PULLUP;

# BTNS
NET "btn_reset_n"         LOC="A13"   | IOSTANDARD = LVCMOS33 | PULLUP;
NET "btn_nmi_n"           LOC="L13"   | IOSTANDARD = LVCMOS33 | PULLUP;

# RESET OUT
NET "o_reset_n"           LOC="C5"   | IOSTANDARD = LVCMOS33 | PULLUP;

# NEMO BUS
NET "bus_rst_n"           LOC="L5"    | IOSTANDARD = LVCMOS33 | PULLUP;
NET "bus_a<0>"            LOC="P9"    | IOSTANDARD = LVCMOS33 | PULLUP;
NET "bus_a<1>"            LOC="P8"    | IOSTANDARD = LVCMOS33 | PULLUP;
NET "bus_a<2>"            LOC="N9"    | IOSTANDARD = LVCMOS33 | PULLUP;
NET "bus_a<3>"            LOC="M9"    | IOSTANDARD = LVCMOS33 | PULLUP;
NET "bus_a<4>"            LOC="T5"    | IOSTANDARD = LVCMOS33 | PULLUP;
NET "bus_a<5>"            LOC="R5"    | IOSTANDARD = LVCMOS33 | PULLUP;
NET "bus_a<6>"            LOC="T4"    | IOSTANDARD = LVCMOS33 | PULLUP;
NET "bus_a<7>"            LOC="P5"    | IOSTANDARD = LVCMOS33 | PULLUP;
NET "bus_a<8>"            LOC="R7"    | IOSTANDARD = LVCMOS33 | PULLUP;
NET "bus_a<9>"            LOC="P6"    | IOSTANDARD = LVCMOS33 | PULLUP;
NET "bus_a<10>"           LOC="T7"    | IOSTANDARD = LVCMOS33 | PULLUP;
NET "bus_a<11>"           LOC="T6"    | IOSTANDARD = LVCMOS33 | PULLUP;
NET "bus_a<12>"           LOC="R2"    | IOSTANDARD = LVCMOS33 | PULLUP;
NET "bus_a<13>"           LOC="E3"    | IOSTANDARD = LVCMOS33 | PULLUP;
NET "bus_a<14>"           LOC="P4"    | IOSTANDARD = LVCMOS33 | PULLUP;
NET "bus_a<15>"           LOC="G3"    | IOSTANDARD = LVCMOS33 | PULLUP;
NET "bus_d<0>"            LOC="F4"    | IOSTANDARD = LVCMOS33 | PULLUP;
NET "bus_d<1>"            LOC="D5"    | IOSTANDARD = LVCMOS33 | PULLUP;
NET "bus_d<2>"            LOC="M1"    | IOSTANDARD = LVCMOS33 | PULLUP;
NET "bus_d<3>"            LOC="R12"   | IOSTANDARD = LVCMOS33 | PULLUP;
NET "bus_d<4>"            LOC="P11"   | IOSTANDARD = LVCMOS33 | PULLUP;
NET "bus_d<5>"            LOC="N1"    | IOSTANDARD = LVCMOS33 | PULLUP;
NET "bus_d<6>"            LOC="C4"    | IOSTANDARD = LVCMOS33 | PULLUP;
NET "bus_d<7>"            LOC="F3"    | IOSTANDARD = LVCMOS33 | PULLUP;
NET "bus_rd_n"            LOC="P1"    | IOSTANDARD = LVCMOS33 | PULLUP;
NET "bus_wr_n"            LOC="R1"    | IOSTANDARD = LVCMOS33 | PULLUP;
NET "bus_iorq_n"          LOC="T12"   | IOSTANDARD = LVCMOS33 | PULLUP;
NET "bus_mreq_n"          LOC="T13"   | IOSTANDARD = LVCMOS33 | PULLUP;
NET "bus_m1_n"            LOC="P7"    | IOSTANDARD = LVCMOS33 | PULLUP;
NET "bus_wait_n"          LOC="N8"    | IOSTANDARD = LVCMOS33 | PULLUP;
NET "bus_iorqge_n"        LOC="D3"    | IOSTANDARD = LVCMOS33 | PULLUP;
NET "bus_nmi_n"           LOC="M10"   | IOSTANDARD = LVCMOS33 | PULLUP;
NET "bus_f14"             LOC="M7"    | IOSTANDARD = LVCMOS33 | PULLUP;
NET "bus_romcs_n"         LOC="M11"   | IOSTANDARD = LVCMOS33 | PULLUP;

# MIDI
NET "midi_tx"             LOC="D1"    | IOSTANDARD = LVCMOS33;
NET "midi_reset_n"        LOC="C3"    | IOSTANDARD = LVCMOS33;
NET "midi_clk"            LOC="C1"    | IOSTANDARD = LVCMOS33;

# GS SRAM
NET "mem_a<0>"            LOC="G16"   | IOSTANDARD = LVCMOS33 | DRIVE = 4 | SLEW = "FAST" | NODELAY;
NET "mem_a<1>"            LOC="H15"   | IOSTANDARD = LVCMOS33 | DRIVE = 4 | SLEW = "FAST" | NODELAY;
NET "mem_a<2>"            LOC="H16"   | IOSTANDARD = LVCMOS33 | DRIVE = 4 | SLEW = "FAST" | NODELAY;
NET "mem_a<3>"            LOC="J14"   | IOSTANDARD = LVCMOS33 | DRIVE = 4 | SLEW = "FAST" | NODELAY;
NET "mem_a<4>"            LOC="J16"   | IOSTANDARD = LVCMOS33 | DRIVE = 4 | SLEW = "FAST" | NODELAY;
NET "mem_a<5>"            LOC="K15"   | IOSTANDARD = LVCMOS33 | DRIVE = 4 | SLEW = "FAST" | NODELAY;
NET "mem_a<6>"            LOC="K16"   | IOSTANDARD = LVCMOS33 | DRIVE = 4 | SLEW = "FAST" | NODELAY;
NET "mem_a<7>"            LOC="L14"   | IOSTANDARD = LVCMOS33 | DRIVE = 4 | SLEW = "FAST" | NODELAY;
NET "mem_a<8>"            LOC="N16"   | IOSTANDARD = LVCMOS33 | DRIVE = 4 | SLEW = "FAST" | NODELAY;
NET "mem_a<9>"            LOC="P15"   | IOSTANDARD = LVCMOS33 | DRIVE = 4 | SLEW = "FAST" | NODELAY;
NET "mem_a<10>"           LOC="P16"   | IOSTANDARD = LVCMOS33 | DRIVE = 4 | SLEW = "FAST" | NODELAY;
NET "mem_a<11>"           LOC="R15"   | IOSTANDARD = LVCMOS33 | DRIVE = 4 | SLEW = "FAST" | NODELAY;
NET "mem_a<12>"           LOC="R16"   | IOSTANDARD = LVCMOS33 | DRIVE = 4 | SLEW = "FAST" | NODELAY;
NET "mem_a<13>"           LOC="R14"   | IOSTANDARD = LVCMOS33 | DRIVE = 4 | SLEW = "FAST" | NODELAY;
NET "mem_a<14>"           LOC="T14"   | IOSTANDARD = LVCMOS33 | DRIVE = 4 | SLEW = "FAST" | NODELAY;
NET "mem_a<15>"           LOC="T15"   | IOSTANDARD = LVCMOS33 | DRIVE = 4 | SLEW = "FAST" | NODELAY;
NET "mem_a<16>"           LOC="A14"   | IOSTANDARD = LVCMOS33 | DRIVE = 4 | SLEW = "FAST" | NODELAY;
NET "mem_a<17>"           LOC="L16"   | IOSTANDARD = LVCMOS33 | DRIVE = 4 | SLEW = "FAST" | NODELAY;
NET "mem_a<18>"           LOC="M15"   | IOSTANDARD = LVCMOS33 | DRIVE = 4 | SLEW = "FAST" | NODELAY;
NET "mem_a<19>"           LOC="N14"   | IOSTANDARD = LVCMOS33 | DRIVE = 4 | SLEW = "FAST" | NODELAY;
NET "mem_a<20>"           LOC="B16"   | IOSTANDARD = LVCMOS33 | DRIVE = 4 | SLEW = "FAST" | NODELAY;
NET "mem_d<0>"            LOC="F16"   | IOSTANDARD = LVCMOS33 | DRIVE = 4 | SLEW = "FAST" | NODELAY;
NET "mem_d<1>"            LOC="F15"   | IOSTANDARD = LVCMOS33 | DRIVE = 4 | SLEW = "FAST" | NODELAY;
NET "mem_d<2>"            LOC="E16"   | IOSTANDARD = LVCMOS33 | DRIVE = 4 | SLEW = "FAST" | NODELAY;
NET "mem_d<3>"            LOC="E15"   | IOSTANDARD = LVCMOS33 | DRIVE = 4 | SLEW = "FAST" | NODELAY;
NET "mem_d<4>"            LOC="D16"   | IOSTANDARD = LVCMOS33 | DRIVE = 4 | SLEW = "FAST" | NODELAY;
NET "mem_d<5>"            LOC="C15"   | IOSTANDARD = LVCMOS33 | DRIVE = 4 | SLEW = "FAST" | NODELAY;
NET "mem_d<6>"            LOC="C16"   | IOSTANDARD = LVCMOS33 | DRIVE = 4 | SLEW = "FAST" | NODELAY;
NET "mem_d<7>"            LOC="B15"   | IOSTANDARD = LVCMOS33 | DRIVE = 4 | SLEW = "FAST" | NODELAY;
NET "mem_wr_n"            LOC="M16"   | IOSTANDARD = LVCMOS33 | DRIVE = 4 | SLEW = "FAST" | NODELAY;
NET "mem_rd_n"            LOC="G14"   | IOSTANDARD = LVCMOS33 | DRIVE = 4 | SLEW = "FAST" | NODELAY;
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

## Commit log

2026-04-19 Initial firmware
    [audio.kicad_sch, fpga1.kicad_sch, fpga2.kicad_sch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]
2026-04-20 Refactoring: project renamed
    [audio.kicad_sch, fpga1.kicad_sch, fpga2.kicad_sch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]
2026-04-20 Updated gerbers to min 0.2/0.45 vias, firmware build for xc6slx16
    [audio.kicad_sch, fpga1.kicad_sch, fpga2.kicad_sch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]
2026-05-12 gs test
    [notes.ods]
2026-05-23 midi tx sensor to disable adc out when no stream so far
2026-05-23 Added samplerate resampler
2026-05-23 Changed resample to actual output samplerate
2026-05-27 revA1 WIP
    [audio.kicad_sch, fpga1.kicad_sch, fpga2.kicad_sch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]
2026-05-29 revA1, WIP
    [audio.kicad_sch, fpga1.kicad_sch, fpga2.kicad_sch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]
2026-05-29 Latest PCB changes
2026-05-29 PCB changelog
2026-05-29 Small improvements to the revA1
    [audio.kicad_sch, fpga1.kicad_sch, fpga2.kicad_sch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]
2026-06-02 Updated revA - rerouted OPL3 reset to /MIDI_RST
    [audio.kicad_sch, fpga1.kicad_sch, fpga2.kicad_sch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]
2026-06-04 Removed polygons under BGA chip on F.Cu layer
    [karabas-megabuzz.kicad_pcb]
2026-06-07 Fixed missing LED1 connection, new revA1 release
    [fpga1.kicad_sch, fpga2.kicad_sch, interfaces.kicad_sch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]
2026-06-07 revB initial commit
    [audio.kicad_sch, fpga1.kicad_sch, fpga2.kicad_sch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]
2026-06-07 Updated revA (cosmetic changes)
    [audio.kicad_sch, fpga1.kicad_sch, fpga2.kicad_sch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]
2026-06-07 Added revB project files, actual 3d pcb screenshots
    [karabas-megabuzz.kicad_pcb, karabas-megabuzz.kicad_sch]
2026-06-14 Reset signal quite longer. clock for OPL3 always propagated. Added missing led1
2026-06-15 Fixed bus nmi out
    [zc_dicmmc.v]
2026-06-16 Fixed ROM block signal: swapped CSR / RDR
    [interfaces.kicad_sch, karabas-megabuzz.kicad_pcb]
2026-06-17 DivMMC + ZC for revA1 (#1)
    * Current Divmmc WIP
    * Added zx rom, fixed divmmc port decoding
    * Fixed A1 Schematics / PCB with RDR + BLK signals
    * Fixed divmmc by areset
    * WIP
    * Working 64kb divmmc + GS rom via flash loader
    * removed zc_busy
    * Project file update for 25k fpga
    * Build files for 25k
    * Fixed project for revA 16k
    * Fixed project for revA 25k
    * Added synth macros HW_A1
    * Added synth macros HW_A1
    [interfaces.kicad_sch, karabas-megabuzz.kicad_pcb]
2026-06-17 Docs, gerbers, ibom for Rev.A1
    [audio.kicad_sch, fpga1.kicad_sch, fpga2.kicad_sch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]
2026-06-21 pcb revA2
    [audio.kicad_sch, fpga1.kicad_sch, fpga2.kicad_sch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]
2026-06-21 revA2 updates
    [interfaces.kicad_sch, karabas-megabuzz.kicad_pcb]
2026-07-19 Added openocd for slx25
    [ocd.cfg]
2026-07-19 Added SD card LED
2026-07-19 Added adapter speed option
    [ocd.cfg]
2026-07-19 Added bscan spi loader for xc6slx16
2026-07-19 Fixed openocd bin file path
    [ocd.cfg]
2026-07-23 Makefile and universal top-level (#2)
    * added nettypes for modules
    * Added more files into gitignore
    * build by makefile
    * Universal top-level
    * Added comments
    * Latest build
    * vs1053 parallel interface
    * Added soft reset via status reg write
    * updated vs1053 module
    [flash.v, i2s_transceiver.v]
2026-07-23 Added pinmap to the ibom
    [karabas-megabuzz.kicad_pcb]
2026-09-19 Neorv32 (#4)
    * Added mp3dec sw for neorv32 risc-v cpu, added initial vhdl for neorv32
    * working vs1053/vs1063 module
    * Updated revA3 with required additional pullups
    * vs1053 testbench
    * neorv32 firmware update
    * Added a test zx program to play test mp3
    * playmp3 dot command for megabuzz
    * outdated files
    * Release bit files for A,A1,A2,A3 SLX16/25
    * latest test build
    * Updated comments
    * Updated A3 errata
    * Fixed buffer size
    * browser plugin
    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
    [audio.kicad_sch, fpga1.kicad_sch, fpga2.kicad_sch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]
2026-09-21 Fixed megabuzz rom applyconfig
    [main.asm]
2026-09-21 optimized spi controller for vs1053
2026-09-21 Fixed reboot after apply/cancel
    [main.asm]
2026-09-22 Added soft reset + zeroes fill
    [vs1053.v]
2026-09-22 Updated revA3 - the reset output on bss138
    [audio.kicad_sch, fpga1.kicad_sch, fpga2.kicad_sch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]
2026-09-24 Дока по портам Megabuzz
2026-11-09 Add output FIR filter and fix bus, reset and timing issues
    Audio: decimate the mix with a 64-tap FIR instead of sampling it
    unfiltered, drop the non-working OPL3 resampler, clock OPL3 at
    14.286 MHz, make GS INT exactly 37.5 kHz, widen mixer sums.
    Design: combinational GS page bits, GS flags set by one strobe,
    synchronized ioreq instead of bus_iorq_n, synchronous DivMMC automap
    and port E3, filtered resets, posedge-only ZC SPI, config write
    closed on A and A1, SRAM and pad-to-pad constraints.
    Config ROM v1.4: wait for key release, skip unchanged saves, verify
    after saving, WaitFlash timeout.
    All 8 bitstreams rebuilt; not yet tested on hardware.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
2026-11-09 Add MAC CFU for the Helix polyphase filter and the decode benchmark
    Replace the XTEA example in the neorv32 CFU with a pipelined 32x32
    multiply-accumulate unit and run PolyphaseMono/Stereo on it under
    USE_CFU_MAC. The worst 44.1 kHz stereo 320 kbps frame goes from
    2.63M to 1.32M cycles in GHDL, with bit-identical PCM.
    Add the GHDL benchmark in sw/bench and PLAN.md with the measurements
    and the remaining steps of the VS1053 emulation.
2026-11-09 Add VS1053 emulation on neorv32 for A2 and A3 on SLX25
    New targets all25_{a2,a3}_rv32 and flash25_{a2,a3}_rv32. The CPU runs at
    70 MHz and decodes MP3 from the existing host FIFO, the PCM goes to the
    mixer through a ring buffer played by an NCO. The firmware is loaded
    from SPI flash at 0x180000.
    On A2 neorv32 is always the decoder. On A3 the new configurator option
    "MP3 on RV32" (config bit 11) selects between it and the VS1053 chip.
    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
2026-11-09 Build SLX25 A, A2 and A3 with neorv32 and fix MP3 decoding on hardware
    The _rv32 targets are gone: all25_a, all25_a2 and all25_a3 are always
    built with the decoder, and their flash targets also write mp3dec.bin.
    A and A2 always use neorv32, A3 still selects it with config bit 11.
    A1 has no room, its DivMMC RAM lives in block RAM.
    The firmware did not decode anything when the host fed bytes slowly, and
    files with a large ID3 tag stayed silent: skip the tag, reject impossible
    headers and wait for the side info before calling MP3Decode.
    Average the MP3 output over the 32 clocks of the FIR input to keep the
    sample edge timing. The ROM is now 32 KB and the PCM ring moved to block
    RAM, Zicntr an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
2026-11-09 Stop resetting the host from the board
    The reset output goes through a diode on A1 and A2, which does not give
    a real low level for CMOS clones, and the reset at startup gets in the
    way of machines that start their own service on a reset, like Pentadiv.
    The output now always stays in Z. The internal reset after loading is
    unchanged. PORTS.md said that register #F9 resets the host, it only ever
    reset the internal logic.
2026-11-09 Share the GS SRAM with DivMMC on A1 and add neorv32 to A1 on SLX25
    A1 kept 64 KB of DivMMC RAM in block RAM, which took 36 of the block RAMs
    of the chip. A new arbiter gives the host the upper 512 KB of the SRAM
    of General Sound: GS keeps its direct path to the pads and is frozen
    through its CE while the host has them, then repeats its access. The
    host is held with WAIT when it is too fast for the access.
    GS sees 1.5 MB while DivMMC is enabled. With the block RAM freed, A1 on
    the SLX25 is built with the neorv32 MP3 decoder. The FIR filter on A1
    on the SLX16 can use block RAM again.
2026-11-10 Rewrite the README and add Russian and English versions of the docs
    README now covers what each board can do, the SD card layout, how to
    choose the MP3 decoder, and the settings on every revision, with a
    screenshot of the configurator taken from the real ROM. There is a
    Russian README and an English HOWTO, cross-linked with the originals.
2026-11-10 Filter the images of GS and MP3 out of the audio output
    GS (37.5 kHz) and MP3 (44.1 kHz) hold each sample, so their images above
    the audio band went straight to the DAC. Their sum now takes its own path:
    - audio_mixer outputs GS + MP3 apart from the main mix (img_l/img_r)
    - audio_avg: shared 32-clock average (replaces rv_audio_avg in rv_vs1053)
    - audio_fir_decim: 4 channels, the second pair decimates GS + MP3
    - audio_img_lpf: new 64-tap filter at 109.375 kHz, flat to 18 kHz,
    -2.2 dB at 20 kHz, -60 dB above 24.4 kHz (audio_img_gen.py, test
    audio_img_tb.py, bit-exact)
    - the two paths are summed and saturated before the DAC; the VU meters
    take the final output
    All 8 variants rebuilt, ti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
2026-11-11 Hide the RV32 option of the configurator on the XC6SLX16
    A new read-only ZXUNO register #F4 reports what the bitstream was
    built for: board revision (bits 2:0), XC6SLX25 (bit 3), neorv32
    (bit 4) and the VS1053 chip (bit 5). The SLX25 variants get a SLX25
    define for it. #F4 is free in ZX-UNO, Next, profi and tsconf.
    The configurator ROM reads it at start and on the SLX16 neither
    draws "MP3 on RV32" nor lets the focus stop on it; config bit 11 is
    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
2026-11-12 Идеи
